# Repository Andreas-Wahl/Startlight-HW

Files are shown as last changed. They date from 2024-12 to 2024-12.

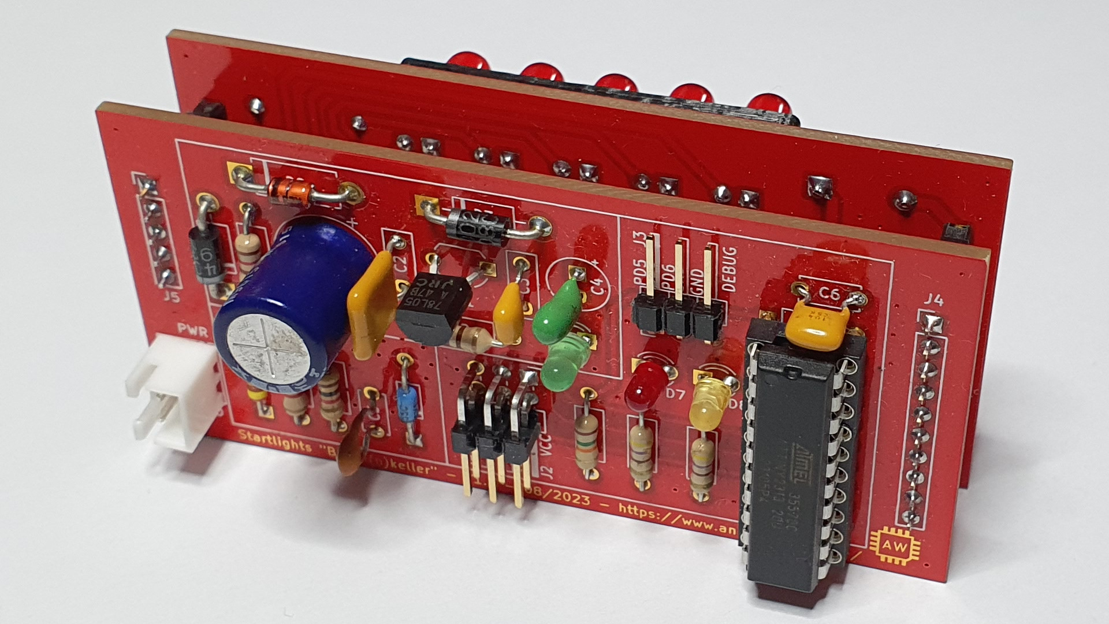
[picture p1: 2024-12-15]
#JPEG/Picture_PCB1-Mainboard.jpeg

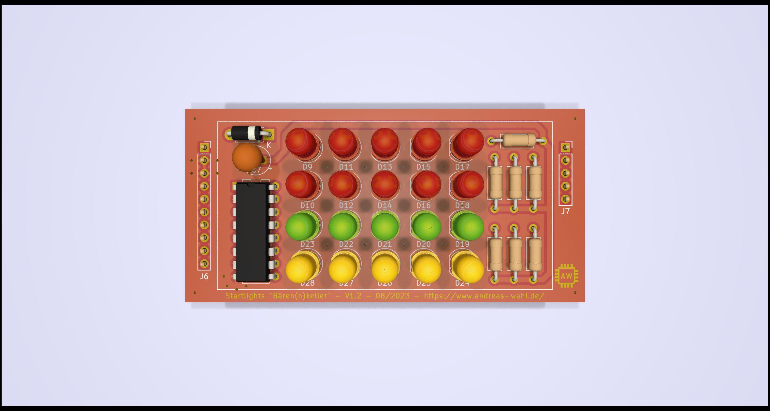
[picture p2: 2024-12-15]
#JPEG/3D-Viewer_PCB2_Display.jpg

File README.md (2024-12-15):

# STARTAMPEL "Bären(n)keller" 🚦

## Project Overview 🏎️

In a private cellar bar that has been in existence for over two generations, originally named "Bärenkeller," a CARRERA® digital 132 racetrack was set up, and the first races were held. This quickly gained popularity among friends and acquaintances. As a result, the racetrack was gradually expanded, and possible extensions were discussed.

The idea of creating a custom starting light emerged because the original CARRERA® Startlight (30354) could not bridge three lanes (two lanes + pit lane). Additionally, the custom STARTAMPEL should not only display the start sequence with red lights but also indicate the race operation with green LEDs, the safety car/pace car operation, and a false start.

The idea was quickly taken up, the data signal was analyzed with an oscilloscope and data logger, and the development of hardware, software, and housing design was initiated.

In reference to the "Bärenkeller," which was renamed "Bären(n)keller" due to the expansion of the CARRERA® digital 132 racetrack, the custom starting light was also named "STARTAMPEL 'Bären(n)keller'."

The STARTAMPEL "Bären(n)keller" was so well received that the developer decided to produce a small quantity as "prototypes" and make the development available for non-commercial use.

## Licensing 📜

- **Electronics and Housing Design**: Released under the Creative Commons Attribution-NonCommercial-ShareAlike 4.0 International License (CC BY-NC-SA 4.0).
- **Software**: Released under the GNU Affero General Public License, Version 3.0 (AGPL-3.0).

## Repository Contents 📂

- **Schematic**: The complete schematic for the STARTAMPEL "Bären(n)keller".
- **PCB Layout**: The PCB layout files for the project.
- **Hardware Documentation**: Detailed documentation on the hardware development and usage.

## Getting Started 🚀

To get started with the project, clone the repository and follow the instructions in the documentation to set up the hardware and software.

```bash
git clone https://github.com/Andreas-Wahl/Startlight-HW.git

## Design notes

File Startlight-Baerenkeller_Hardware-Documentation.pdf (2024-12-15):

# SLOTCAR STARTAMPEL „Bären(n)keller“

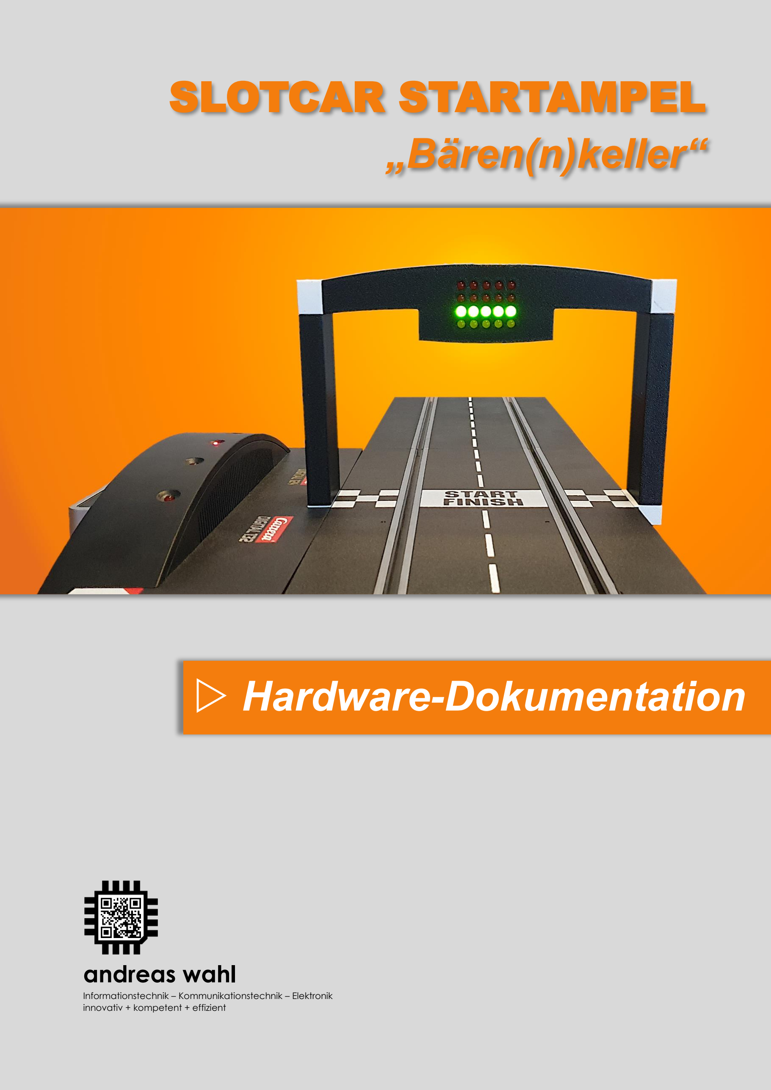
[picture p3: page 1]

SLOTCAR STARTAMPEL "Bären(n)keller" - Hardware-Dokumentation

# - Hardware-Dokumentation

## andreas wahl

Informationstechnik – Kommunikationstechnik – Elektronik innovativ + kompetent + effizient

# SLOTCAR STARTAMPEL

# „Bären(n)keller“

# Hardware-Dokumentation

# Version 1.0 - 31.01.2024

Software-Version: 1.0
https://github.com/Andreas-Wahl/Startlight-SW
Hardware-Version: 1.3
https://github.com/Andreas-Wahl/Startlight-HW
Gehäuse-Version 1.0
https://github.com/Andreas-Wahl/Startlight-3D

## andreas wahl

Informationstechnik – Kommunikationstechnik – Elektronik innovativ + kompetent + effizient
https:/www.andreas-wahl.de/

### Inhaltsverzeichnis

### Einführung und Ziele

Idee und Namensgebung

In einer bereits über zwei Generationen bestehenden privaten Kellerbar, die ursprünglich den Namen „Bärenkeller“ erhalten hat, wurde eine CARRERA® digital 132 Rennbahn aufgebaut und die ersten Rennen ausgetragen.

Schnell fand dies bei Freunden und Bekannten großen Anklang. So wurde die Rennbahn sukzessive weiter ausgebaut und über mögliche Erweiterungen diskutiert.

So entstand auch die Idee einer eigenen Startampel, da die originale Startampel CARRERA® Startlight (30354) nicht über drei Fahrspuren (zwei Fahrspuren + Boxengasse) überbrücken kann. Weiter sollte die eigene Startampel nicht nur die Start-Sequenz über rote Anzeigen darstellen können, sondern auch den freigegebenen Rennbetrieb mit grünen LEDs, den Safety-Car-/Pace-Car-Betrieb und einen Frühstart anzeigen.

Kurzerhand wurde die Idee aufgegriffen, das Datensignal mit Oszilloskop und Datenlogger analysiert und die Entwicklung von Hardware, Software und Gehäuse-Design angestoßen.

In Bezug auf den „Bärenkeller“, welcher durch die Erweiterung der CARRERA® digital 132 Rennbahn zum „Bärennkeller“ umbenannt wurde, erhielt auch die selbst entwickelte Startampel den Namen „STARTAMPEL „Bären(n)keller““.

Die STARTAMPEL „Bären(n)keller“ fand so großen Anklang, dass sich der Entwickler entschlossen hat, eine kleine Menge als „Prototypen“ zu produzieren und die Entwicklung für nicht kommerzielle Nutzung zur Verfügung zu stellen.

Die Elektronik und das Gehäusedesign sind unter der Creative Commons Version 4.0 Lizenz „Namensnennung, nicht kommerziell, Weitergabe unter gleichen Bedingungen (CC BY-NC-SA 4.0)“ und die Software unter der „GNU Affero General Public License, Version 3.0“ veröffentlicht.
Über diese Dokumentation

Nachfolgend wird die für die „STARTAMPEL „Bären(n)keller“ entwickelte Elektronik betrachtet und beschrieben.

Das Projekt „STARTAMPEL „Bären(n)keller“ soll insbesondere dazu anregen, sich spielerisch mit der Elektronik und der Programmierung von Mikrocontrollern, insbesondere in Assembler, auseinanderzusetzen.

Diese Dokumentation soll als Hilfestellung dienen und weitere Anreize und Ideen für interessanten Projekten bei Spiel und Spaß bieten.

Entsprechend der Software-Dokumentation wurde auch die Hardware-Dokumentation weitgehend an den Aufbau und die Struktur der arc42¹
-Software-Architekturdokumentation angelehnt. Dadurch erhalten sowohl die Software- als auch die Hardware-Dokumentation einen vergleichbaren Aufbau und eine durchgängige Struktur, was die Lesbarkeit und das Verständnis erleichtern sollen.

1 arc42: https://arc42.org/

Aufgabenstellung

Für die STARTAMPEL „Bären(n)keller“ wurden nachfolgend aufgeführte und beschriebene Funktionen festgelegt.

ID | Anforderung | Erklärung
M-1 | THT-Aufbau | Damit die Elektronik auch von Anfängern leicht nachgebaut und gewartet werden kann, ist diese in Durchsteckmontage (THT, through-hole technology) aufzubauen.
M-2 | AVR-Mikrocontroller | Für die Steuerung ist der AVR® Mikrocontroller Attiny2313 zu verwenden.
M-3 | 4x5 5 mm-LED Anzeige | Für die Anzeige der Startampel sind 5 mm LEDs zu verwenden, welche in 4 Reihen und 5 Spalten wie folgt aufzubauen sind: 2 Reihen in 5 Spalten rot, 1 Reihe grün, 1 Reihe gelb.
M-4 | Unterbringung im Startampelgehäuse | Die komplette Elektronik muss im Gehäuse der Startampel untergebracht werden können.
M-5 | Stromversorgung und Daten über den Fahrleiter | Die Stromversorgung der Elektronik muss über den Fahrleiter der CARRERA® digital Rennbahn erfolgen. Über diesen ist auch das Datensignal zu gewinnen.
M-6 | Schutz vor Anschlussfehler | Die Elektronik muss vor fehlerhaftem Anschluss der Anschlussleitungen geschützt werden.
M-7 | Schutz vor Überspannung | Die Elektronik muss vor Überspannungen, welche auf dem Fahrleiter auftreten könnten, geschützt werden.
M-8 | Zugängliche ISP-Schnittstelle | Für die Software-Entwicklung und spätere Aktualisierungen muss die ISP-Schnittstelle des Mikrocontrollers über Pfostenverbinder zugänglich sein.
M-9 | Einfacher Nachbau | Die Schaltung soll auch für Einsteiger verständlich und leicht nachzubauen sein. Auch bei der Bauteilauswahl soll daher auf gut verfügbare Bauteile und Werte Rücksicht genommen werden.

Qualitätsziele

Folgende wesentliche Qualitätsanforderungen wurden für die STARTAMPEL „Bären(n)keller“ bestimmt:

ID | Anforderung | Erklärung
Q-1 | Korrektheit | Die jeweils signalisierten Zustände müssen korrekt sein.
Q-2 | Zuverlässigkeit | Die Zustände müssen zuverlässig signalisiert werden.
Q-3 | Leistungsfähigkeit | Schnelle Auswertung und kurze Reaktionszeit.
Q-4 | Darstellung | Gute und eindeutige Darstellung der einzelnen Zustände.

Stakeholder

Folgende Personen und Gruppen haben Interesse am Aufbau, an der Funktion und Qualität der Elektronik (Hardware) der STARTAMPEL „Bären(n)keller“:

Rolle | Ziel | Erwartungshaltung
Rennleitung | Zuverlässiger Betrieb. | Möchte eine zuverlässige und störungsfreie Funktion.
Fahrer | Schnelle, zuverlässige und fehlerfreie Signalisierung. | Möchte die Zustände des Rennbetriebes schnell, korrekt und zuverlässig erkennen können.
Zuschauer | Gute Visualisierung des Rennbetriebs. | Möchte die Zustände des Rennbetriebes gut und ohne Verwechslungsgefahr erkennen können.

Folgende Personen und Gruppen haben Interesse am Schaltplan und einer Beschreibung der Hardware für die STARTAMPEL „Bären(n)keller“:

Rolle | Ziel | Erwartungshaltung
Entwickler | Effizientes Umsetzen der definierten Anforderung in der Hardware. | Gute und detaillierte Beschreibung der zu erwartenden Funktionen und Qualitätsziele sowie umfangreiche Dokumentation der angebundenen Systeme.
Tester | Prüfen der Anwendung auf mögliche Fehler. | Ausfallsichere und langlebige Hardware, die robust gegenüber möglichen Störungen und Fehlbedienung ist
Nutzer | Möchte die Elektronik nachbauen und bei Bedarf reparieren. | Leichter Nachbau, klare, präzise und fehlerfreie Dokumentation.

### Randbedingungen

Für die Entwicklung der Elektronik (Hardware) für die STARTAMPEL „Bären(n)keller“ liegen folgende Randbedingungen vor.

ID | Anforderung
RB-1 | Mikrocontroller: Microchip AVR®-Mikrocontroller ATtiny2313² 8 MHz Taktfrequenz, interner Takt Interner SRAM Externen Interrupt 7 digitale Ausgänge In-System-Programmierung und debugWIRE
RB-2 | Carrera® digital 124/132 Rennbahn³ 14,8 V Fahrspannung bei 132 (18 V Fahrspannung bei 124) 10 kHz Manchester Code
RB-3 | 5mm-LEDs für die Anzeige 2 Reihen rot in 5 Spalten 1 Reihe grün 1 Reihe gelb
RB-4 | Verfügbarer Platz im Gehäuse der STARTAMPEL „Bären(n)keller“: Breite: 79 mm Höhe: 39 mm Tiefe: 41 mm +15 mm für LEDs
RB-5 | Die Schaltung und das Platinen-Layout sind mit der Open-Source Schematic Capture & PCB Design Software KiCAD EDA⁴ zu entwickeln.
RB-6 | Für Schaltungssimulationen ist die von ANALOG DEVICES⁵ kostenlos zur Verfügung gestellte Simulationssoftware LTspice⁶ zu verwenden.

2 Microchip ATtiny2313: https://www.microchip.com/en-us/product/ATtiny2313
3 CARRERA® digital 132 Rennbahn: https://carrera-toys.com/digital-132
4 KiCad Open Source Electronics Design Automation Suite: https://www.kicad.org/
5 ANALOG DEVICES: https://www.analog.com/en/index.html
6 LTspice: https://www.analog.com/en/resources/design-tools-and-calculators/ltspice-simulator.html

### Kontextabgrenzung

Fachlicher Kontext

Spannungsversorgung

Die Fahrbahnen der CARRERA® digital 124/132 Rennbahnen⁷ werden mit folgende Versorgungsspannungen betrieben:

Variante/Maßstab | Nennspannung | Nennstrom | Nennleistung
digital 124 | 18 V | 3 A | 54 VA
digital 132 | 14,8 V | 3,5 A | 51 VA
Die hier beschriebene Hardware wurde für die CARRERA® digital 132 dimensioniert. Daher berücksichtigt diese Dokumentation maßgeblich die Nennspannung von 14,8 V.

Über die Fahrspannung wird das Datensignal in Anlehnung an den Manchester Code⁸ moduliert.

Im Abstand von 6,2 ms folgen Datenpakete mit einer Länge von acht bis zwölf Bits und einer Dauer von 0,8 bis 1,2 ms.

Während der Übertragung wird die Spannungsversorgung entsprechend dem Flankenwechsel des Datensignales unterbrochen. Die längste Low- (GND-) Phase liegt außerhalb einer Boxengasse entsprechend der Übertragungsfrequenz von 10 kHz bei 100 µs Periodendauer. Für den Datenempfang von Fahrzeugen und Zubehör erzeugt die CARRERA® digital Control-Unit ebenfalls Low- (GND-) Phasen mit einer Länge von 50 µs, auf die bei Bedarf mit einem Hochziehen des Signales auf High-Potential geantwortet wird.

Datensignal

Die Datenübertragung erfolgt im Manchester-Code mit einer Übertragungsfrequenz von 10 kHz, was einer Übertragungsrate von 10 KBaud entspricht.

Werden aufeinanderfolgend gleiche Bits (bspw.: 00000000 oder 11111111) übertragen, findet ein Flankenwechsel alle 50 µs statt, was einer Frequenz von 20 kHz entspricht.

Bei jeweils aufeinanderfolgend unterschiedlichen Bits (bspw. 01010101), erfolgt der Flankenwechsel alle 100 µs, was einer Frequenz von 20 kHz, entspricht.

Der durchschnittliche Tastgrad (Duty-Cycle) des Manchester-Code-Datensignals beträgt 0,5 (50 %).

Anzeige-Einheit

Die Anzeigeeinheit der STARTAMPEL „Bären(n)keller“ soll aus jeweils 5 x 2 roten LEDs für die Anzeige der Startsequenz (Countdown), 5 grünen LEDs für die freigegebene Rennstrecke und 5 gelbe LEDs für die Pace-Car/Safety-Car-Phase bestehen.

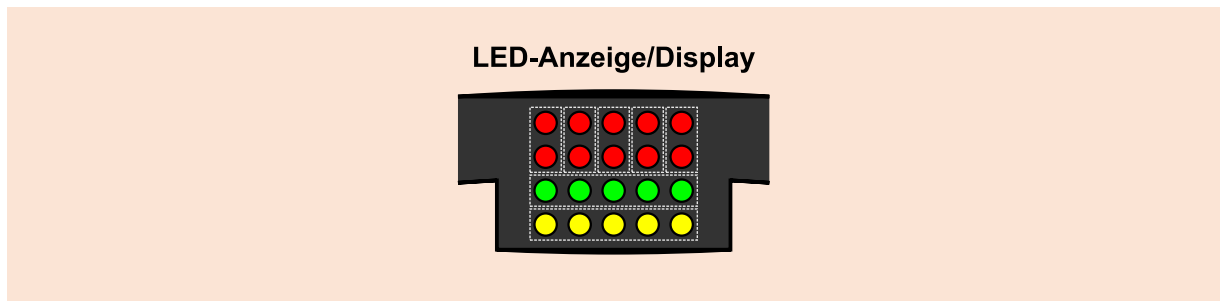
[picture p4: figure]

7 CARRERA® digital 132 Rennbahn: https://carrera-toys.com/digital-132 8 Manchester Code: https://de.wikipedia.org/wiki/Manchester-Code

Technischer Kontext

Übersicht der Komponenten

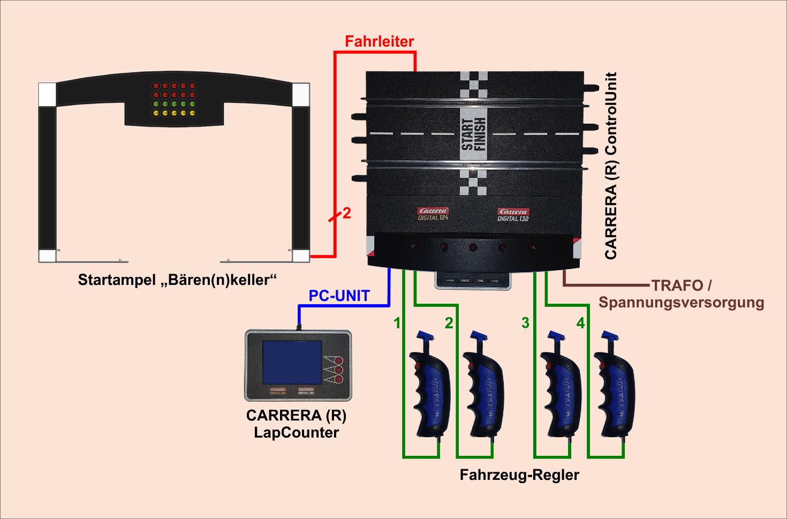
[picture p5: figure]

Bezeichnung | Beschreibung
Control-Unit | Zentraleinheit der CARRERA® digital 124/132 Rennbahn für die Bedienung und Steuerung des Rennbetriebs und Anschluss aller Komponenten.
Lap-Counter | Rundenzähler für die CARRERA® digital 124/132 Rennbahn. Über diesen werden Zeit- und Rundenrennen gestartet und das Rennen entsprechend beendet, wenn Zeit oder Anzahl der Runden erreicht wurden. Der Sieger, bzw. das Fahrzeug, welches das Rennen beendet, wird durch den Lap-Counter signalisiert. Alternativ können an der PC-Unit-Schnittstelle auch anderweitige Lösungen, wie bspw. PC-Software, angebunden werden.
Regler | Mit den Reglern (Controller / Drücker) werden die Fahrzeuge (fern-) gesteuert. Es können bis zu 6 Regler gleichzeitig angeschlossen werden.
Fahrzeug | Das Fahrzeug (Slotcar) im Maßstab 1:24 bzw. 1:32 fährt mittels Leitkiel in einem Schlitz seiner zugehörigen Fahrspur auf der Rennstrecke. Über Kontaktschleifer wird das Fahrzeug über die Fahrbahn mit Spannung versorgt. Bei der CARRERA® digital 124/132 Rennbahn erhält das Fahrzeug über den Fahrleiter auch die Steuerinformationen mittels Datenpaketen im Manchester Code. Es können bis zu 8 Fahrzeuge (6x Regler +1 Ghost Car +1 Pace Car) zeitgleich auf der Rennstrecke fahren.
Startampel | Die STARTAMPEL „Bären(n)keller“ ergänzt die Rennstrecke um eine Visualisierung der Start-Sequenz, des Zustandes der Rennstrecke usw.
Datenpakete | Mittels Datenpaketen, welche im Manchester-Code über den Fahrleiter gesendet werden, kommuniziert die CARRERA® digital 124/132 Control-Unit mit Fahrzeugen und Zubehör (wie Weichen, Zeitmessungen, Boxengassen u. ä.). Auch die für die STARTAMPEL „Bären(n)keller“ erforderlichen Informationen werden auf diese Weise übertragen.

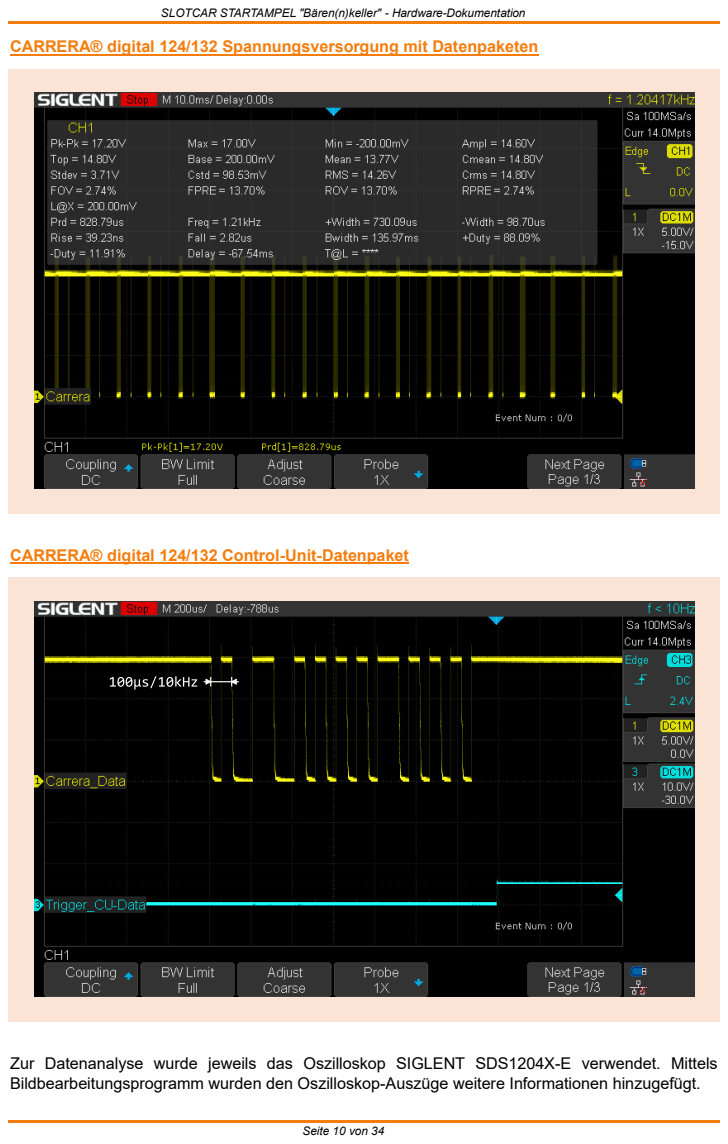
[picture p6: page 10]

CARRERA® digital 124/132 Spannungsversorgung mit Datenpaketen

CARRERA® digital 124/132 Control-Unit-Datenpaket

Zur Datenanalyse wurde jeweils das Oszilloskop SIGLENT SDS1204X-E verwendet. Mittels
Bildbearbeitungsprogramm wurden den Oszilloskop-Auszüge weitere Informationen hinzugefügt.

### Lösungsstrategie

Die Elektronik wird in zwei Platinen

- Hauptplatine
(Enthält alle Komponenten zur Auswertung des Datensignals.)
- Displayplatine
(Enthält alle Komponenten für die LED-Anzeige.)

aufgeteilt, welche über Stift- und Buchsenleisten jeweils rückseitig zusammengesteckt werden und damit eine Einheit bilden.

Auf den einzelnen Platinen wird die Elektronik in Funktionsblöcken aufgeteilt, die in der nachfolgenden Beschreibung näher betrachtet werden:

Hauptplatine:

- Spannungsversorgung Mikrocontroller
(Stellt aus der Fahrspannung der CARRERA® digital Rennbahn eine stabile +5 V Spannungsversorgung für den Mikrocontroller bereit.)
- Signalaufbereitung
(Bereitet das auf der Fahrspannung der CARRERA® digital Rennbahn modulierte Datensignal für die Verarbeitung über einen Porteingang des Mikrocontrollers auf.)
- Mikrocontroller
(Enthält den Mikrocontroller und dessen zum Betrieb erforderliche Komponenten.)

Displayplatine:

- LED-Anzeige
(Enthält die LEDs der Startampel, sowie die notwendigen Treiber.)

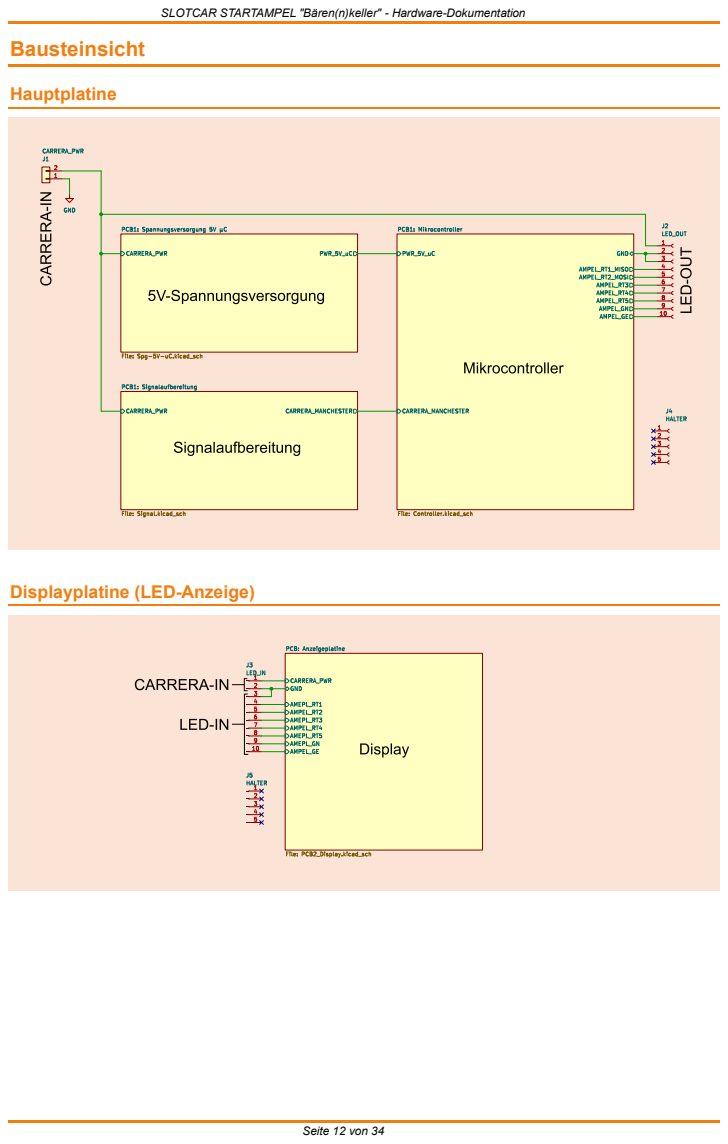
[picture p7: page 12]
Bausteinsicht; Hauptplatine

Displayplatine (LED-Anzeige)

### Schaltungsentwicklung

Stromversorgung (Hauptplatine)

Eckdaten

Auf der Hauptplatine benötigt der Microchip AVR®-Mikrocontroller ATtiny2313 und seine externe Beschaltung eine Spannungsversorgung von 5 V.

Zur Ermittlung des Strombedarfes werden folgende Komponenten berücksichtigt:

Nr. | Komponente | Strombedarf
1 | Mikrocontroller Atmel 2313 mit internem Oszillator bei 8 MHz | 7,5 mA
2 | Spannungsregler | 6 mA
3 | Power-LED, 3 mm, grün | 10 mA
4 | Debug-LED, 3 mm, gelb | 10 mA
5 | Debug-LED, 3 mm, rot | 10 mA
6 Ansteuerung Treiberbaustein ULN2003A | (maximal 5 Treiber zeitgleich aktiv) | 5x1,35 mA =6,75 mA
| Maximaler Gesamtstrombedarf (ICC): | 50,3 mA

Schaltungsaufbau

Die dargestellte Schaltung zur 5 V-Spannungsversorgung des Mikrocontrollers mit einem linearen Festspannungsregler wird im Folgenden näher beschrieben.

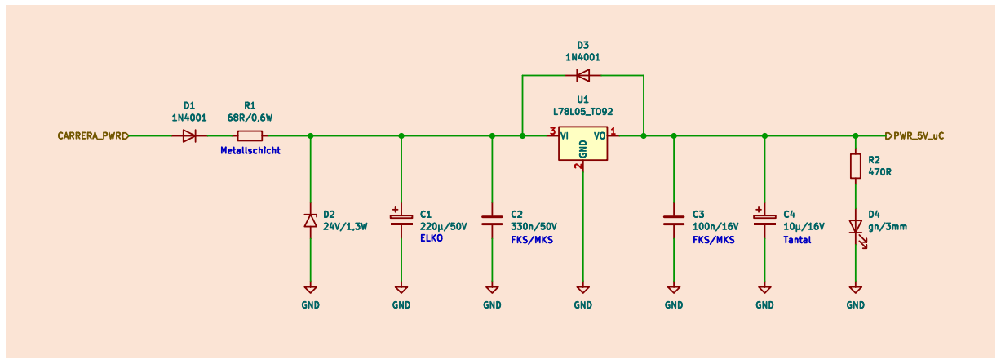
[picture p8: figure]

Verpolungsschutz und Rückwirkungsfreiheit

Um die Schaltung vor fehlerhaftem Anschluss zu schützen, wird am Eingang eine 1N4001-Diode (D1) in Durchlassrichtung eingesetzt. Zudem verhindert die Diode am Eingang Rückwirkungen auf das durch die Control-Unit modulierte Datensignal der Fahrspannung, die durch die nachfolgenden Glättungs- und Siebkondensatoren verursacht werden könnten.

Vorwiderstand

Um die Verlustleistung am nachfolgenden Spannungsregler zu begrenzen, wird ein Vorwiderstand in Reihe geschaltet. Ziel ist es, die Verlustleistung zwischen Widerstand und Spannungsregler so zu verteilen, dass es bei keinem der beiden Bauteile in Extremfällen zu einer Überlastung kommen kann.

Damit dem Spannungsregler eine ausreichende Eingangsspannung zur Verfügung steht, ist die maximal am Vorwiderstand abfallende Spannung wie folgt zu berechnen:

UR1 = URV = UCC − UD1 − UU1 − UU1_Ausgang

Die im Datenblatt⁹ des Spannungsreglers 78L05 von ST angegebene Dropout-Spannung beträgt 1,7 V. Um die Störunterdrückung bei eingangsseitigen Spannungsschwankungen in den vom Hersteller angegebenen Grenzen zu halten, wurden 300 mV Regelreserve für die Betriebssicherheit berücksichtigt.

UU1 = UU1_DropOut + UU1_Regelreserve = 1,7 V + 0,3 V = 2 V

Damit ergibt sich für die am Vorwiderstand maximal abfallende Spannung:

UR1 = 14,8 V − 0,7 V − 2 V − 5 V = 7, 1 V

Die von der Control-Unit übertragenen Daten sind periodisch und nicht sinusförmig (Rechteck). Das für die Spannungsversorgung bei der Manchester-Code-Übertragung ungünstigste Tastverhältnis liegt bei 0,5. Bei einem Tastverhältnis von 50 % und einem Gleichstrommittelwert von 50,3 mA muss somit in der ersten Halbwelle des Rechtecksignals der doppelte Strom zur Verfügung stehen, damit die Schaltung mit ausreichend Energie versorgt wird. (Siehe auch Pulsweitenmodulation¹⁰)

Somit ergibt sich für den Vorwiderstand:

R1 = RV =

UR1

ICC

× d =

UR1

ICC

×

tein
t

=

7,1 V
50,3 mA

×

50 µs
100 µs

= 70, 6 Ω

Durch die Auswahl eines 68 Ω-Vorwiderstandes aus der E12-Reihe ist der ungünstigste Fall des Tastverhältnisses für eine sichere und zuverlässige Versorgung der Schaltung mit der erforderlichen Energie berücksichtigt.

Berechnung der Verlustleistung am Vorwiderstand R1:

Für den nach der E12-Serie ausgewählten 68 Ω Widerstand ergibt sich folgende mittlere Verlustleistung:

PR1 =

UR1

2
R1

× d =

(7,1 V)

2
68 Ω

×

50 µs
100 µs

= 370, 7 mW

Damit ist ein üblicher Kohleschichtwiderstand mit 1/4 W maximaler Verlustleistung für den zuverlässigen Dauerbetrieb nicht ausreichend. Hier wird deshalb ein 0,6 W Metallschichtwiderstand eingesetzt.

Überspannungsschutz

Eine nachgeschaltete Zenerdiode in Sperrrichtung gegen Ground schützt die Schaltung vor möglichen Spannungsspitzen der Eingangsspannung, die durch Induktivitäten der Fahrzeuge und Weichen auf der CARRERA® digital Rennbahn verursacht werden könnten.

9 78L05 – Datenblatt von ST: https://www.st.com/resource/en/datasheet/l78l.pdf
10 Pulsweitenmodulation: https://www.mikrocontroller.net/articles/Pulsweitenmodulation

Glättungskondensator

Die mit 10 kHz Manchester-Code modulierte Fahrspannung muss für eine stabile 5 V-Spannungsversorgung zunächst „geglättet“ werden, um auch in den Low-Phasen der Eingangsspannung den nachfolgenden Spannungsregler mit der erforderlichen Eingangsspannung von mindestens ca. 7,1 V sicher zu versorgen.

Bei einer mit Manchester-Code modulierten Spannung handelt es sich um eine periodische, nicht sinusförmige Rechteckspannung. Übliche Berechnungen für sinusförmige periodische Signale sind hier daher nichtzutreffend.

Kapazität

Da das Rechtecksignal einem wechselnden Ein- und Ausschalten einer an den Kondensator angeschlossenen Spannungsquelle entspricht, wird zur Ermittlung der erforderlichen Kapazität der Lade- und Entladevorgang des Kondensators betrachtet. Während der High-Phase des Rechtecksignals wird der Kondensator aufgeladen, und während der Low-Phase wird er entladen.

Für die Ladung eines Kondensators gilt:

Q = I × t und Q = C × U

Daraus ergibt sich:

I × t = C × U

Die erforderliche Kapazität des Glättungskondensators lässt sich damit für einen Laststrom von ICC=50,3 mA, einer maximalen Restwelligkeit von ΔUU1_Ripple_Eingang=0,1 V und einer High-Phase des 10 kHz-Rechtecksignals von t=50 µs, wie folgt berechnen:

C1 =

ICC × Δt

∆UU1_Ripple_Eingang

=

50,3 mA × 50 µs
0,1 V

= 25, 2 µF

Equivalent Series Resistance (ESR)

### 11 und Lebensdauer

Für die Auswahl eines Kondensators ist es, insbesondere bei höherfrequenten Spannungen, entscheidend, wie schnell sich der Kondensator aufladen lässt und wie schnell er die Ladung wieder abgeben kann. Maßgeblich hierfür ist der Innenserienwiderstand des Kondensators, auch als ESR (Equivalent Series Resistance) bekannt. Je niedriger der ESR, desto schneller kann der Kondensator auf- und entladen werden. Ein niedrigerer ESR bedeutet auch eine niedrigere Restwelligkeit des geglätteten Signals und eine niedrigere Verlustleistung im Kondensator.

Grundsätzlich bietet ein Tantal-Kondensator aufgrund seines vergleichsweisen niedrigen
äquivalenten | Serienwiderstands | (ESR) | im | Verhältnis | zu | seinen | Abmessungen | zu
Elektrolytkondensatoren einen Vorteil. Allerdings sind Tantal-Kondensatoren teurer und empfindlicher gegenüber Ripplestrom-Überlastungen und schnellen Schaltflanken. Daher wurde für den Eingang des Spannungsreglers entschieden, einen vergleichbaren Elektrolytkondensator auszuwählen.

Zu berücksichtigen ist allerdings, dass sich bei Elektrolytkondensatoren der Innenserienwiderstand ESR mit dem Alter infolge der Diffundierung ihres Elektrolytes erhöht. Dabei sinkt auch die Kapazität. Die Lebensdauer von handelsüblichen Elektrolytkondensatoren bei Ausschöpfung der Nenndaten beträgt je nach Qualität etwa 2.000 bis 5.000 Betriebsstunden bei voller Ausnutzung der Kapazität und Einhaltung des Umgebungstemperaturbereichs. Durch höheres Dimensionieren kann eine

11 Ersatzserien-Widerstand / Equivalent Series Resistance (ESR): https://de.wikipedia.org/wiki/Elektrolytkondensator#Scheinwiderstand_Z_und_Ersatzserienwiderstand_ESR

Verlängerung der Lebensdauer erreicht werden, da der Elektrolytkondensator nicht im Grenzbereich betrieben wird und genügend Reservekapazität besteht.

Bei der Auswahl des Elektrolytkondensators wurde, ausgehend von einem Tantal-Kondensator¹² mit 33 µF Kapazität, ein ESR von ca. 77 mΩ gemessen.

Da sich bei Elektrolytkondensatoren mit steigender Frequenz die effektiv wirkende Kapazität verringert, wurde ein Elektrolytkondensator mit ausreichender Restkapazität in angegebenem Frequenzbereich ausgewählt, um die Restwelligkeit in oben berechneten Grenzen zu halten. Ein Elektrolytkondensator mit einer Kapazität von 220 µF hatte einen vergleichbaren ESR von ca. 77 mΩ und wird in dieser Schaltung eingesetzt.

Spannungsregler

Der Einsatz eines 5 V-Festspannungsreglers¹³ 78L05¹⁴ (U1) bietet eine einfache Möglichkeit, eine stabile Versorgungsspannung von 5 V bereitzustellen. Unter Berücksichtigung des ermittelten Strombedarfs ist der lineare Festspannungsregler 78L05 im TO-92 Gehäuse ausreichend und kann einen Strom von bis zu 100 mA liefern. Die maximal zulässige Eingangsspannung des 78L05 beträgt 30 V und wird durch die geringeren Fahrspannungen der Carrera® digital Rennbahnen nicht erreicht.

Um die 5 V Ausgangsspannung zuverlässig bereitzustellen, benötigt der 78L05 bei einer Dropout-Spannung von 1,7 V am Eingang eine Eingangsspannung von mindestens 6,7 V. Wie oben bereits erwähnt, sind für die Regelreserve zusätzliche 0,3 V berücksichtigt.

Restwelligkeit (Ripple)

Der vorgeschaltete Glättungskondensator wurde für eine Restwelligkeit von maximal ΔUU1_Ripple_Eingang=0,1 V dimensioniert, sodass die erforderliche Eingangsspannung bereits sehr stabil und zuverlässig zur Verfügung steht. Über die Supply Voltage Rejection (SVR) lässt sich die zu erwartende Restwelligkeit am Ausgang eines Spannungsreglers berechnen.

Der hier eingesetzte lineare Festspannungsregler 78L05 von ST hat gemäß Datenblatt im ungünstigsten Fall ein SVR von -40 dB.

Für die Amplitude (A) gilt:

A = 20 × log (
UAusgang

UEingang)

Nach Umstellung auf Ua

Ua = Ue × 10(

A
20)

lässt sich die zu erwartende Restwelligkeit wie folgt berechnen:

∆UU1_Ripple_Ausgang = ∆UU1_Ripple_Eingang × 10(

SVR
20 ) = 0,1 V × 10(

−40
20 ) = 1 mV

Verlustleistung

Die am Spannungsregler abfallende Verlustleistung berechnet sich wie folgt:

PU1 = UU1 × ICC = 2V × 50,3 mA = 100, 6mW

12 Tantal-Kondensatoren: https://de.wikipedia.org/wiki/Tantal-Elektrolytkondensator 13 Festspannungsregler: https://de.wikipedia.org/wiki/Spannungsregler
14 78L05 – Datenblatt von ST: https://www.st.com/resource/en/datasheet/l78l.pdf

Daraus ergibt sich eine Wärmeentwicklung von

∆T = PU1 × θJA = 100,6 mW × 200 K/W = 20, 12 K

Bei einer Umgebungstemperatur von 25°C steigt die Temperatur auf 45,12°C. Eine für den eingesetzten Festspannungsregler ohne Kühlung mögliche Temperatur.

Schwingneigung

Um ein Schwingen des Spannungsreglers zu verhindern, ist gemäß dem Datenblatt am Eingang ein Kondensator mit einer Kapazität von 330 nF (C2) und am Ausgang ein Kondensator mit einer Kapazität von 100 nF (C3) vorzusehen. Dies wurde hier entsprechend übernommen.

Schutzdiode

Eine Diode (D3) in Sperrrichtung vom Eingang zum Ausgang des Spannungsreglers schützt diesen davor, dass dessen Ausgangsspannung nicht spürbar (hier maximal 0,7 V) über der
Eingangsspannung | liegen | kann. | Würde | die | Ausgangsspannung | deutlich | über | der
Eingangsspannung liegen, könnte dies den im Spannungsregler eingebauten Längstransistor zerstören. Dieser Fall könnte beispielsweise durch einen Kurzschluss am Glättungskondensator (C1) eintreten.

Pufferkondensator

Um die 5 V-Ausgangsspannung weiter zu stabilisieren, insbesondere zur Pufferung der Stromspitzen des Mikrocontrollers sowie als Blockkondensator zur Filterung von hochfrequenten Störungen, wird am Ausgang der 5 V-Spannungsversorgung ein 10 µF Tantal-Kondensator (C4)
eingesetzt. | Tantal-Kondensatoren | haben, | wie | oben | bereits | beschrieben, | gegenüber
Elektrolytkondensatoren einen deutlich niedrigeren äquivalenten Serienwiderstand (ESR, Equivalent Series Resistance) und können daher benötigte Energie deutlich schneller bereitstellen, da sie sich schnell laden und entladen lassen.

Da die eingangsseitige Glättung und der lineare Festspannungsregler die Spannung bereits wesentlich stabilisieren und damit die Restwelligkeit deutlich verringern, fällt die Empfindlichkeit von Tantal-Kondensatoren gegenüber Ripplestrom-Überlastungen und schnellen Schaltflanken hier nicht mehr maßgeblich ins Gewicht.

Kontroll-LED-Anzeige

Zur Kontrolle der anliegenden 5 V-Ausgangsspannung wird eine grüne LED (D4) mit entsprechendem Vorwiderstand (R2) an den Ausgang geschaltet.

Signalaufbereitung (Hauptplatine)

Eckdaten

Die I/O-Eingänge des Mikrocontrollers haben einen Spannungsbereich von -0,5 V bis VCC +0,5 V. Eingangsspannungen

- im Bereich von -0,5 V bis 0,3 * VCC werden sicher als Low-Pegel und
- im Bereich von 0,6 * VCC und VCC + 0,5 V als High-Pegel

erkannt.

Bei einer Spannungsversorgung von VCC=5 V ergibt sich somit

- eine maximale Eingangsspannung von 5,5 V,
- ein Low-Pegel zwischen -0,5 V und 1,5 V und
- ein High-Pegel zwischen 3,0 V und 5,5 V

Das CARRERA® digital 124/132 Datensignal hat eine Spannung von 14,8 V (132) und 18 V (124) und muss daher über einen Spannungsteiler auf die zulässige Eingangsspannung des verwendeten I/O-Pins des Mikrocontrollers reduziert werden.

Zusätzlich muss der I/O-Pin des Mikrocontrollers vor Spannungsspitzen über 5,5 V geschützt werden.

Schaltungsaufbau

Für den Teil der Signalaufbereitung ergibt sich folgender Schaltungsaufbau:

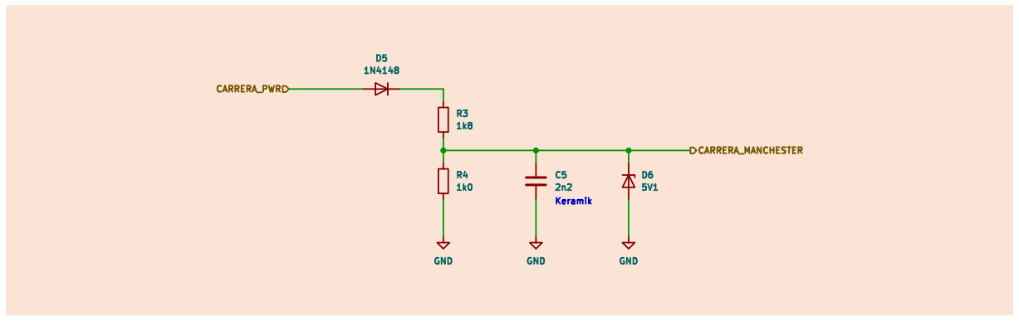
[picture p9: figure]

Schutzschaltungen

Um die Schaltung vor falscher Polung zu schützen, wird am Eingang in Durchlassrichtung eine 1N4148-Diode (D5) eingesetzt. Zudem verhindert die Diode am Eingang Rückwirkungen auf die Fahrspannung und das darauf modulierte Datensignal durch den nachfolgenden Tiefpass-Kondensator.

Eine 5V1-Zenerdiode¹⁵
, (D6) welche in Sperrrichtung am I/O-Pin des Mikrocontrollers Richtung Ground geschaltet wird, schützt den Eingang des Mikrocontrollers vor Überspannungen.

Hinweis: Durch diese Zenerdiode ist grundsätzlich auch ein unveränderter Betrieb an einer CARRERA® digital 124 Rennbahn möglich. Allerdings fließt dabei ein unnötig hoher Strom über den 1k8-Widerstand und die Zenerdiode ab.

Spannungsteiler

Zunächst wird die Eingangsspannung durch die Eingangsdiode um 0,7 V herabgesetzt. Der darauffolgende Spannungsteiler mit den Widerständen 1k8 (R3) und 1k0 (R4) der E12-Reihe teilt die Spannung weiter im Verhältnis 1,8:1,0 auf. Am Eingang des Mikrocontrollers liegt bei 14,8 V Fahrspannung ein High-Pegel von 5,04 V an.

Hinweis: Wird der Spannungsteiler für den dauerhaften Betrieb an einer CARRERA® digital 124 Rennbahn mit einer Fahrspannung von 18 V angepasst, so muss auch die nachfolgende Berechnung des Kondensators entsprechend angepasst werden!

Bei Betrieb an einer CARRERA® digital 124 Rennbahn mit 18 V Fahrspannung empfiehlt es sich daher, den 1k8 Widerstand gegen einen 2k7 Widerstand zu ersetzen. Dann liegt bei 18 V Fahrspannung ein High-Pegel von 4,68 V am Eingang des Mikrocontrollers an. Dies ist noch ausreichend, um ein High-Signal am Eingang sicher zu erkennen.

15 Zenerdiode: https://de.wikipedia.org/wiki/Z-Diode

Filter

Zur Filterung hochfrequenter Störungen des Eingangssignals am Mikrocontroller wird ein Kondensator vom Eingangssignal gegen Ground geschaltet. Dieser bildet zusammen mit dem Spannungsteiler einen Tiefpass¹⁶

Die Grenzfrequenz¹⁷ (-3 dB) des Tiefpasses soll bei etwa der 10-fachen Frequenz des Nutzsignals liegen. Da die Übertragung des Manchester-Codes mit 10 kHz erfolgt, berechnet sich der Filterkondensator für eine Grenzfrequenz von 100 kHz wie folgt:

Cg =

1
2 × π × R × fg

Gemäß dem Thévenin-Theorem¹⁸ werden für die Wechselstromanalyse Spannungsquellen kurzgeschlossen und Stromquellen geöffnet. Damit sind die Widerstände des Spannungsteilers für die Frequenzanalyse als Parallelschaltung zu betrachten.

Für den Widerstand Rp ergibt sich somit:

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
1,8 kΩ

+

1
1,0 kΩ

=

1
1,556 kΩ

⇒ Rp = 643 Ω

Nun lässt sich der Filterkondensator (C5) wie folgt berechnen:

C5 = Cg =

1
2 × π × Rp × fg

=

1
2 × π × 643 Ω × 100 kHz = 2, 4 nF

Für eine genauere Berechnung des Tiefpasses müssten zusätzlich der Eingangswiderstand und die Eingangskapazität des Mikrocontrollers sowie die entsprechenden Eigenschaften der Zenerdiode berücksichtigt werden. Für diesen Anwendungszweck werden diese Abweichungen jedoch in Kauf genommen.

Unter Berücksichtigung verfügbarer Kondensatoren gemäß der E6-Reihe wird für C5 ein Keramikkondensator mit einer Kapazität von 2,2 nF ausgewählt.

Daraus ergibt sich eine Grenzfrequenz von:

fg =

1
2 × π × Rp × C5

=

1
2 × π × 643 Ω × 2,2 nF = 112 kHz

16 Tiefpass: https://de.wikipedia.org/wiki/Tiefpass
17 Grenzfrequenz: https://de.wikipedia.org/wiki/Grenzfrequenz
18 Thévenin-Theorem: https://de.wikipedia.org/wiki/Th%C3%A9venin-Theorem

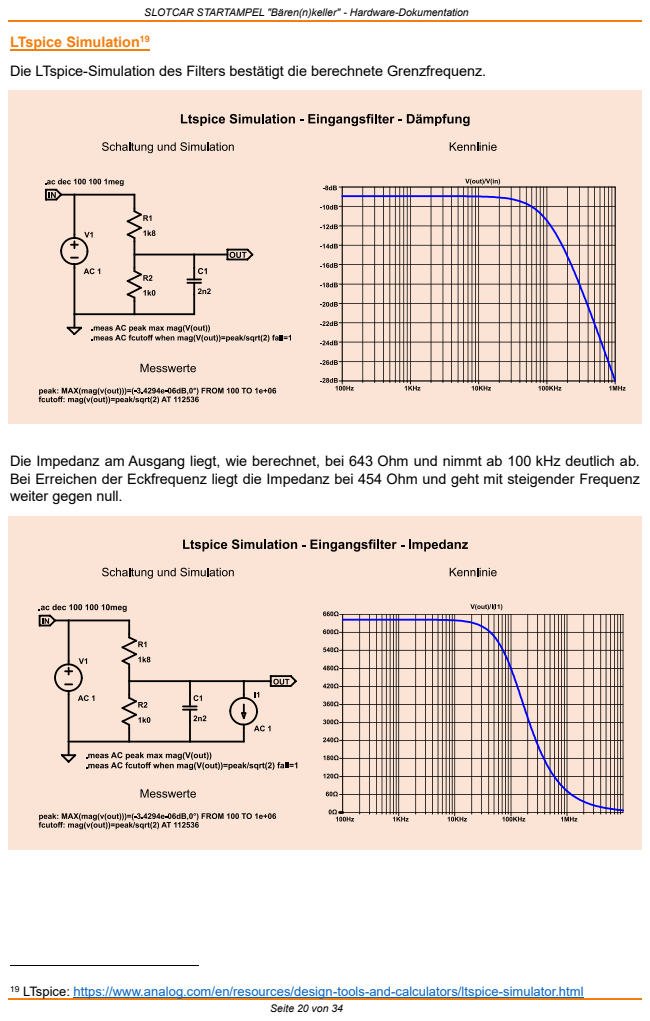
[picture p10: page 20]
LTspice Simulation¹⁹

Die LTspice-Simulation des Filters bestätigt die berechnete Grenzfrequenz.

Die Impedanz am Ausgang liegt, wie berechnet, bei 643 Ohm und nimmt ab 100 kHz deutlich ab.
Bei Erreichen der Eckfrequenz liegt die Impedanz bei 454 Ohm und geht mit steigender Frequenz
weiter gegen null.

19 LTspice: https://www.analog.com/en/resources/design-tools-and-calculators/ltspice-simulator.html

Mikrocontroller (Hauptplatine)

Eckdaten

Das Herzstück ist der Microchip AVR®-Mikrocontroller ATtiny2313²⁰, welcher mit der eigens dafür entwickelten Assembler-Software²¹ die Dekodierung und Auswertung des CARRERA® digital 124/132 Datensignales sowie die Steuerung der LED-Anzeigen der Startampel „Bären(n)keller“ übernimmt. Für den Systemtakt wird der interne Oszillator verwendet, wodurch eine separate Quarz-Beschaltung entfällt.

Hinweis: Für die Assembler-Software wurde eine eigene Software-Dokumentation erstellt, auf die hier für Informationen zur Software verwiesen wird.

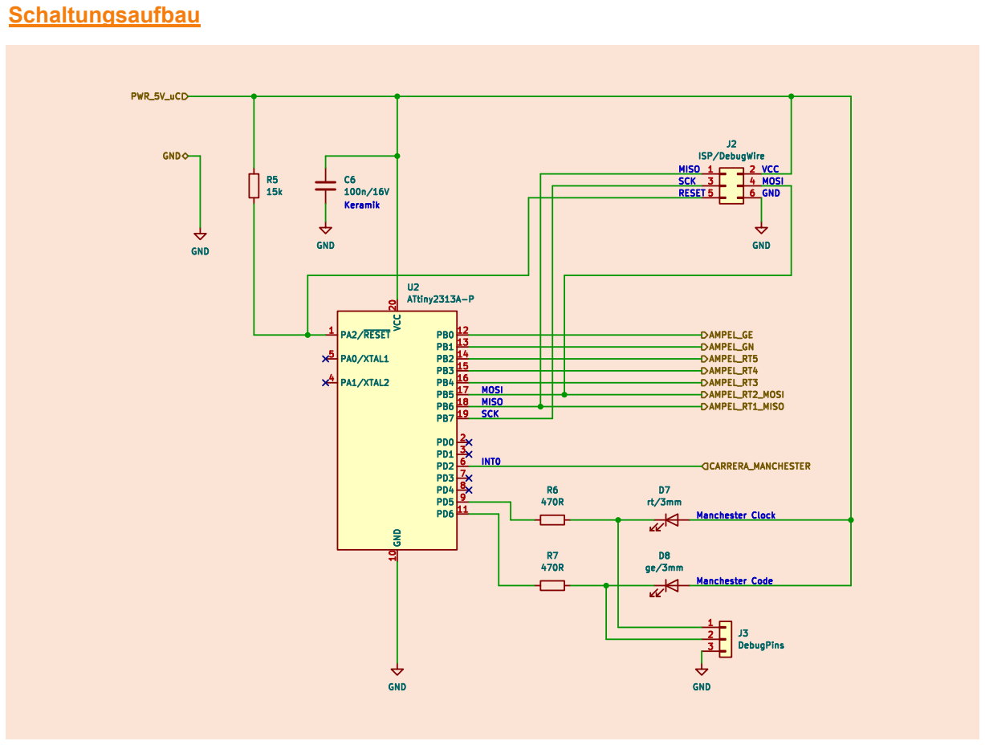
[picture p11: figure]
Schaltungsaufbau

Stromversorgung

Der Mikrocontroller erhält über den linearen Festspannungsregler der Hauptplatine seine 5 V-Versorgungsspannung. Ein Blockkondensator²² (C6) von 100 nF zwischen VCC und Ground direkt am Mikrocontroller sorgt dafür, dass Störungen durch impulsweise sehr hohe Ströme frühzeitig abgeblockt werden und sich nicht störend auf den Rest der Schaltung ausbreiten.

20 ATtiny2313: https://www.microchip.com/en-us/product/ATtiny2313 21 Assembler: https://de.wikipedia.org/wiki/Assemblersprache
22 Blockkondensator: https://de.wikipedia.org/wiki/Blockkondensator

ISP und debugWIRE

Die Schnittstellen für die In-System-Programmierung²³ (ISP) und zur Fehlersuche (debugWIRE²⁴) werden über eine Pfostensteckverbindung so herausgeführt, dass ein einfaches Programmieren und Debuggen komfortabel möglich sind. Hierzu wird der Programmieradapter Microchip Atmel ICE²⁵ verwendet.
Selbstverständlich | kann | dies | auch | mit | anderen | ISP- | und | debugWIRE-kompatiblen
Programmieradaptern erfolgen, die von der verwendeten Programmiersoftware unterstützt werden.

Pull-up-Widerstand für Reset-PIN

Der Reset-PIN wird zusätzlich zum relativ hochohmigen internen Pull-up-Widerstand mit einem externen Pull-up-Widerstand von 15 kOhm gegen VCC beschaltet. So wird sichergestellt, dass der Mikrocontroller nicht durch Einstreuung von Störsignalen ungewollt ein Reset-Signal erhält. Weiterhin ist der Pull-up-Widerstand (R15) mit 15 kOhm ausreichend hochohmig, damit der Programmieradapter am ISP/debugWIRE die Reset-Funktion sicher auslösen kann.

Debug-PINs und -LEDs

Zur Kontrolle und Fehlersuche werden zwei I/O-Ausgänge als Debug-PINs (J3) für Messungen herausgeführt und zur optischen Signalisierung mit LEDs beschaltet. Um Beschädigungen durch versehentliche Kurzschlüsse bei Messungen zu vermeiden, erfolgt der Abgriff der herausgeführten Debug-PINs jeweils im Spannungsteiler zwischen der jeweiligen LED (D7, D8) und dem Vorwiderstand (R7, R8).

Dabei wird die LED mit der Anode an VCC angeschlossen und mit der Kathode über einen Vorwiderstand an den I/O-Ausgang des Mikrocontrollers. Die jeweiligen Debug-PINs werden zwischen der Kathode der LED und dem Vorwiderstand abgegriffen. Bei einem versehentlichen Kurzschluss über die Messleitung wird der Strom, welcher aus oder in den Mikrocontroller fließt, über den Vorwiderstand der LED begrenzt.

LED-Anzeige (Displayplatine)

Eckdaten

Die LED-Anzeige oder Displayplatine wird rückseitig über Pfostenverbinder mit der Hauptplatine verbunden und bildet so eine kompakte Einheit. Zur Stromversorgung der LEDs wird die Fahrspannung der CARRERA® digital 124/132 verwendet.

Die LED-Anzeige der STARTAMPEL „Bären(n)keller“ besteht aus:

- 5 roten LEDs, jeweils 2 in Reihe geschaltet, für die Startphase
- 4 grünen LEDs, in Reihe geschaltet, für den Rennbetrieb
- 4 gelben LEDs, in Reihe geschaltet, für die Pace-Car-/Safety-Car-Phase

Diese werden durch den Mikrocontroller über das 7-fach-Darlington-Transistor-Array ULN2003A angesteuert.

23 In-System-Programmierung: https://de.wikipedia.org/wiki/In-System-Programmierung 24 debugWire: https://de.wikipedia.org/wiki/DebugWIRE
25 Atmel ICE: https://www.microchip.com/en-us/development-tool/atatmel-ice

Zur Ermittlung des Strombedarfes werden folgende Komponenten berücksichtigt:

Nr. | Komponente | Strombedarf
1 | 5 Spalten, je 2 in Reihe geschaltete rote LEDs | 5x 10 mA = 50 mA
2 | 1 Reihe mit 4 in Reihe geschalteten grüne LEDs | 10 mA
3 | 1 Reihe mit 4 in Reihe geschalteten gelben LEDs | 10 mA
| Maximaler Gesamtstrombedarf: | 70 mA

Unter Berücksichtigung, dass nicht alle LEDs gleichzeitig aktiv sein werden, wird der ermittelte maximale Gesamtstrombedarf im realen Betrieb nicht erreicht. Der maximale Strom im Regelbetrieb fließt, wenn alle roten LEDs eingeschaltet sind. Zu diesem Zeitpunkt sind die grünen und gelben LEDs nicht aktiv. Der ermittelte Strombedarf im Regelbetrieb wird bei maximal 50 mA liegen. Dies tritt ein, wenn durch die Startampel „Bären(n)keller“ signalisiert wird, dass die Rennstrecke aktuell gesperrt ist (Chaos) oder bei Rennvorbereitung und am Ende der Startsequenz.

Schaltungsaufbau

Es ergibt sich folgender Schaltungsaufbau für den Teil der Displayplatine:

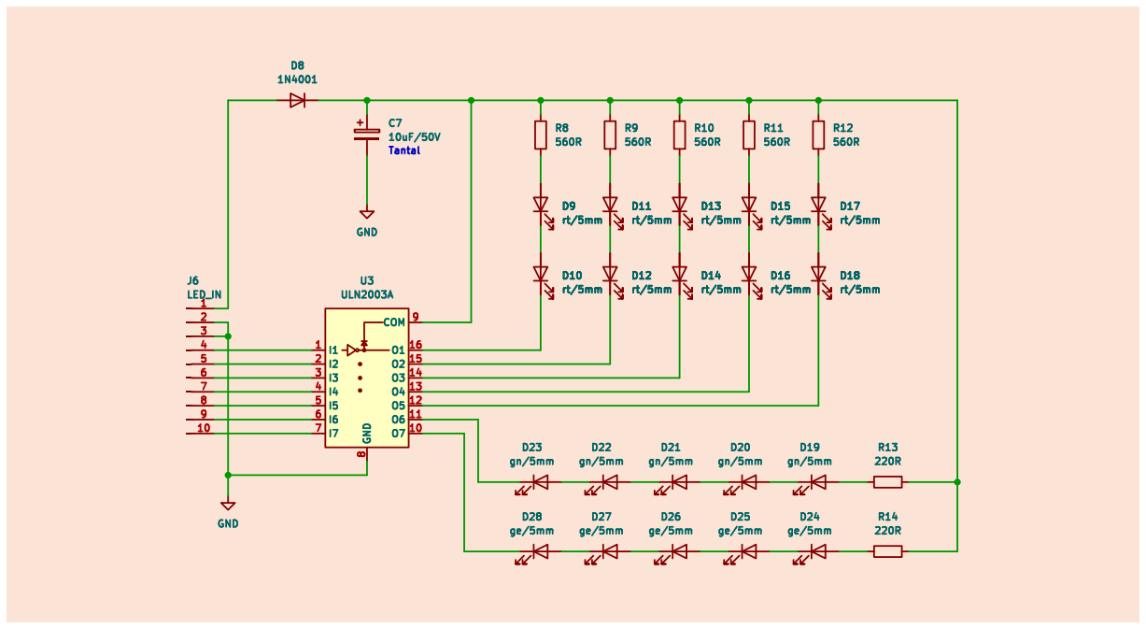
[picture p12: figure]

Schutzschaltungen

Um die Schaltung vor falscher Polung zu schützen, wird am Eingang in Durchlassrichtung eine 1N4001-Diode (D8) eingesetzt. Zudem verhindert die Diode am Eingang Rückwirkungen auf die Fahrspannung und das darauf modulierte Datensignal.

Pufferkondensator

Um eine möglichst stabile Versorgungsspannung zu gewährleisten, wird als Pufferkondensator ein 10 µF Tantal-Kondensator (C7) eingesetzt, welcher die Spannungseinbrüche aufgrund des auf die Fahrspannung modulierten Datensignals überbrückt. Tantal-Kondensatoren haben gegenüber Elektrolytkondensatoren einen deutlich niedrigeren äquivalenten Serienwiderstand (ESR, Equivalent Series Resistance) und können daher benötigte Energie deutlich schneller bereitstellen, da sie sich schnell laden und entladen lassen.

Wie oben bereits beschrieben, sind Tantal-Kondensatoren teurer und empfindlicher gegenüber Ripplestromüberlastungen und schnellen Schaltflanken. Aufgrund des Vorteils eines niedrigeren ESR wurde hier dennoch entschieden, einen Tantal-Kondensator zu verwenden, um die LEDs jederzeit mit ausreichend Energie versorgen zu können.

Darlington-Array

Die Eingänge des Darlington²⁶
-Arrays (U3) werden über Pfostenverbinder mit den Ausgängen des Mikrocontrollers verbunden. Der gemeinsame Anschluss (COM) der Freilaufdioden des ULN2003A²⁷ müsste zwingend nur bei induktiven Lasten an VCC angeschlossen werden. Aufgrund der Vollständigkeit und um mögliche Störungen abzuleiten, wurde der COM-Anschluss hier trotz ausschließlich ohmscher Lasten mit VCC verbunden.

LEDs

Die LEDs (D9-D23) werden über die entsprechenden Vorwiderstände (R8-R14) mit der gepufferten Fahrspannung und über den jeweils vorgesehenen Ausgang des Darlington-Arrays mit Ground verbunden.

26 Darlington-Schaltung: https://de.wikipedia.org/wiki/Darlington-Schaltung
27 Texas Instruments ULN2003A: https://www.ti.com/product/de-de/ULN2003A

### Platinen-Layout

Der Aufbau der Platine wurde so gewählt, dass die Bauteile zu den jeweiligen Funktionsblöcken
(Spannungsversorgung, | Signalaufbereitung, | Mikrocontroller) | logisch | gruppiert | sind. | Die
Funktionsblöcke sind deutlich zu erkennen.

Bei der Leiterbahnführung wurde auf möglichst kurze Leiterbahnen unter Berücksichtigung des Stromflusses geachtet. Mittels Durchkontaktierungen wird für eine möglichst niederohmige Verbindung zum GND-Potential gesorgt, um insbesondere hochfrequente Störeinflüsse möglichst zu vermeiden bzw. deutlich zu verringern.

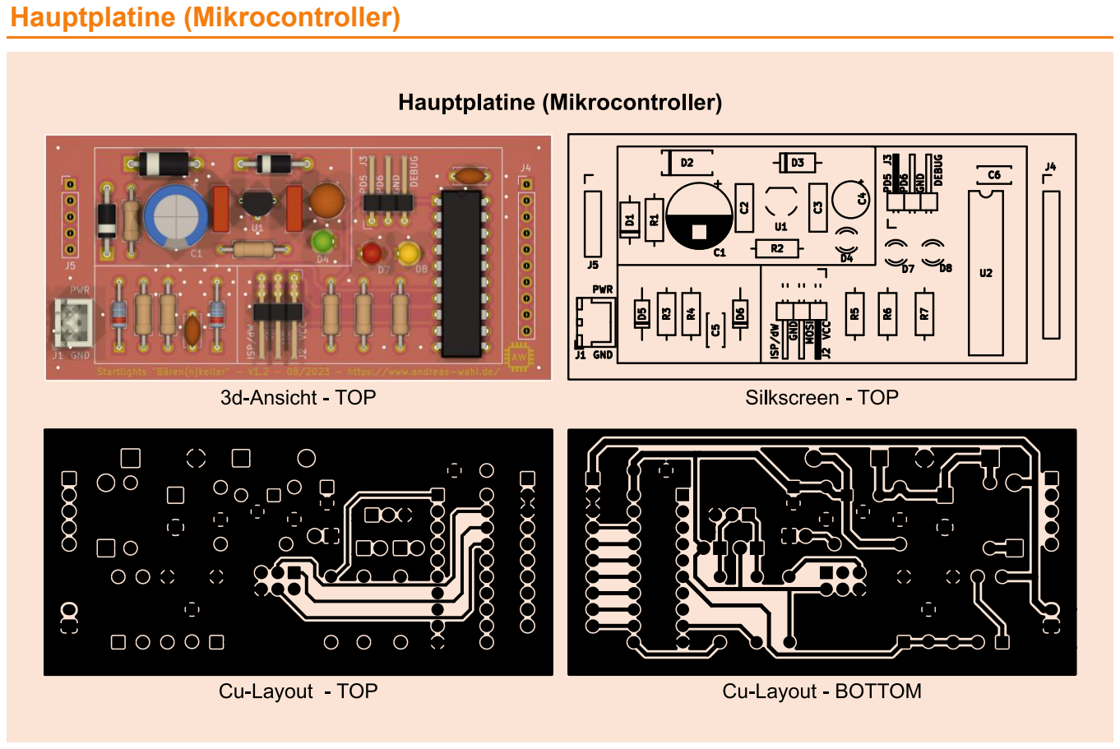
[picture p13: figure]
Hauptplatine (Mikrocontroller)
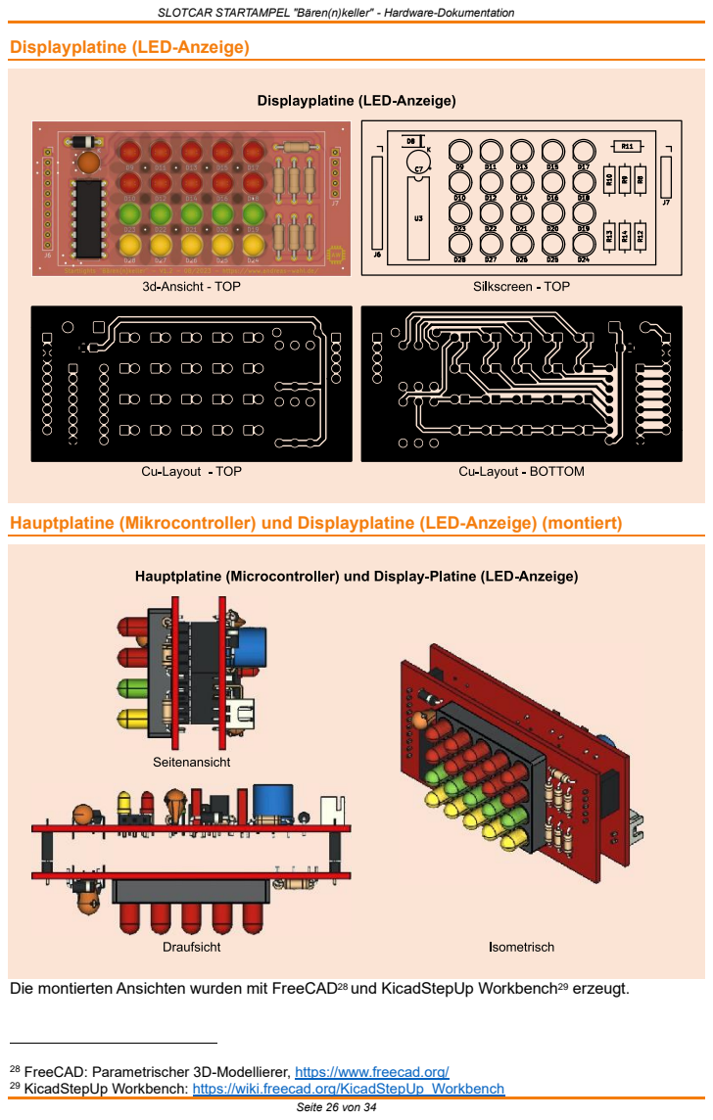
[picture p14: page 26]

Displayplatine (LED-Anzeige)

Hauptplatine (Mikrocontroller) und Displayplatine (LED-Anzeige) (montiert)

Die montierten Ansichten wurden mit FreeCAD²⁸ und KicadStepUp Workbench²⁹ erzeugt.

28 FreeCAD: Parametrischer 3D-Modellierer, https://www.freecad.org/
29 KicadStepUp Workbench: https://wiki.freecad.org/KicadStepUp_Workbench

### Qualitätsanforderungen

Für die nachfolgende Messungen wurde das Oszilloskop SIGLENT SDS-1204X-E

30 verwendet. Bei
allen Messungen wurden die Masse mit der Ground Spring am Tastkopf direkt in Signalnähe abgegriffen, um Einstreuungen durch Erdschleifen der Masse-Leitungen zu vermeiden. Dies ist insbesondere bei der Messung der Restwelligkeit³¹ (Ripple) von Bedeutung, da hier in Größenordnungen von wenigen Millivolt gemessen wird.

### 5 V-Spannungsversorgung

Zunächst wurde die 5 V-Spannungsversorgung in der Gleichstrombetrachtung gemessen. Für die Zeitbasis wurden 100 µs/Div. gewählt, um eventuelle Einflüsse durch das 10 kHz-Datensignal direkt zu erkennen. Der Messbereich für die Spannung liegt bei 2,00 V/Div. und wurde zur Darstellung der Messergebnisse um -6 V nach unten verschoben.

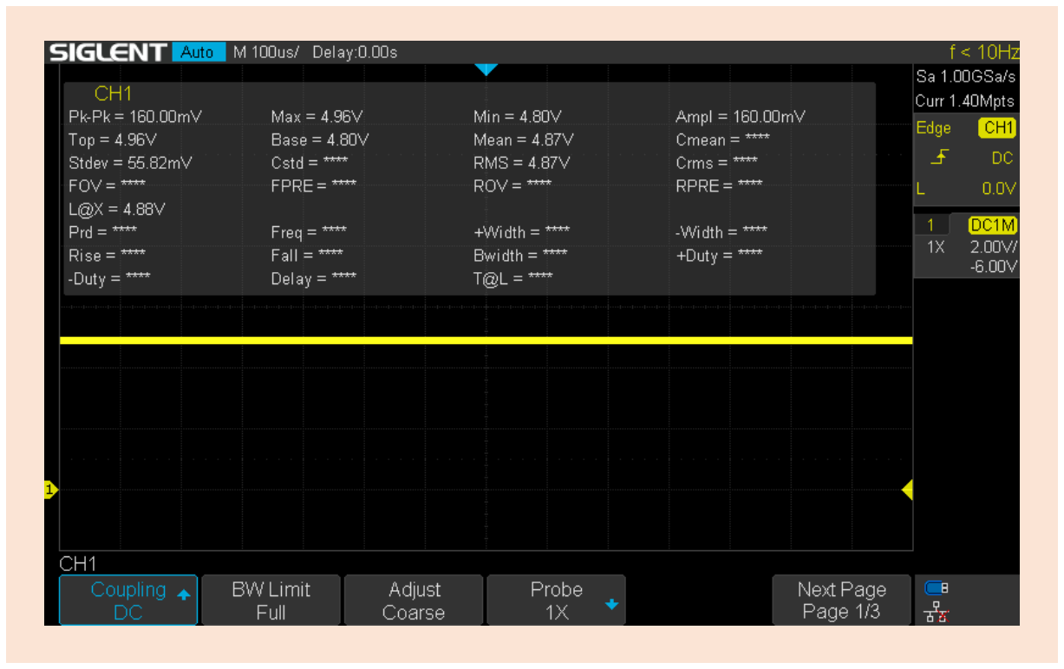
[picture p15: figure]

Die Messung zeigt eine konstante Spannungsversorgung von 4,87 V mit einer durchschnittlichen Restwelligkeit von 55,82 mV. Einzelne Peaks wurden mit +90 mV und -70 mV festgestellt.

Im Wechselstrommodus (AC) lässt sich der Ripple näher betrachten. Die Zeitbasis wurde auf 200 µs/Div. erhöht, um einen größeren Zeitausschnitt zu betrachten. Für den Messbereich der Spannung wurden 5,00 mV/Div. gewählt und zur Anzeige der Messdaten um -10,0 mV nach unten verschoben.

30 SIGLENT SDS1204X-E: https://www.siglent.eu/product/1139259/siglent-sds1204x-e-200mhz-four-channel-oscilloscope (https://www.siglent.eu/product/1139259/siglent-sds1204x-e-200mhz-four-channel-oscilloscope)
31 Restwelligkeit: https://de.wikipedia.org/wiki/Restwelligkeit

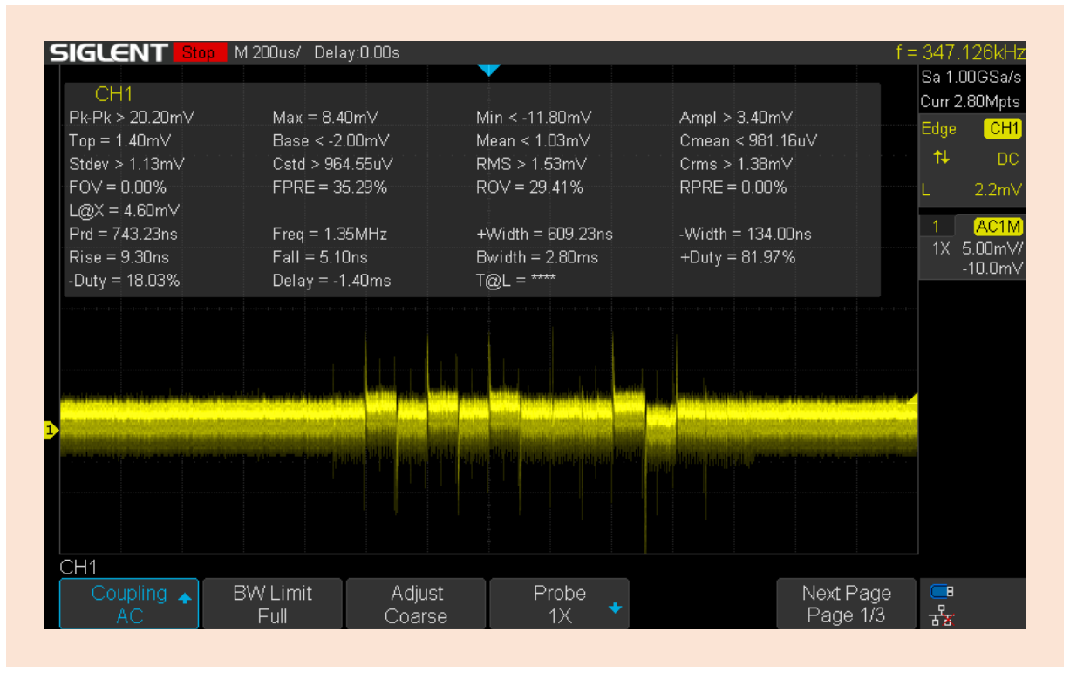
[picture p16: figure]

Zu erkennen sind die trotz Glättung und Siebung verbliebenen Störimpulse, die durch das der auf die Fahrspannung modulierte, steilflankige Datensignal verursacht werden. Diese werden hier mit einer Spitzen-Spitzen-Spannung von 20,2 mVPk-Pk gemessen. Der Maximalwert der Störimpulse liegt bei +8,4 mVMax, der Minimalwert der Störimpulse bei -11,80 mVMin.

Die durchschnittliche Restwelligkeit beträgt 3,4mVAmpl und bewegt sich im Bereich von +1,4 mVTop bis -2,0 mVBase.

Für diesen Anwendungsfall der STARTAMPEL „Bären(n)keller“ wird die erreichte Qualität der Spannungsversorgung als mehr als ausreichend erachtetet.

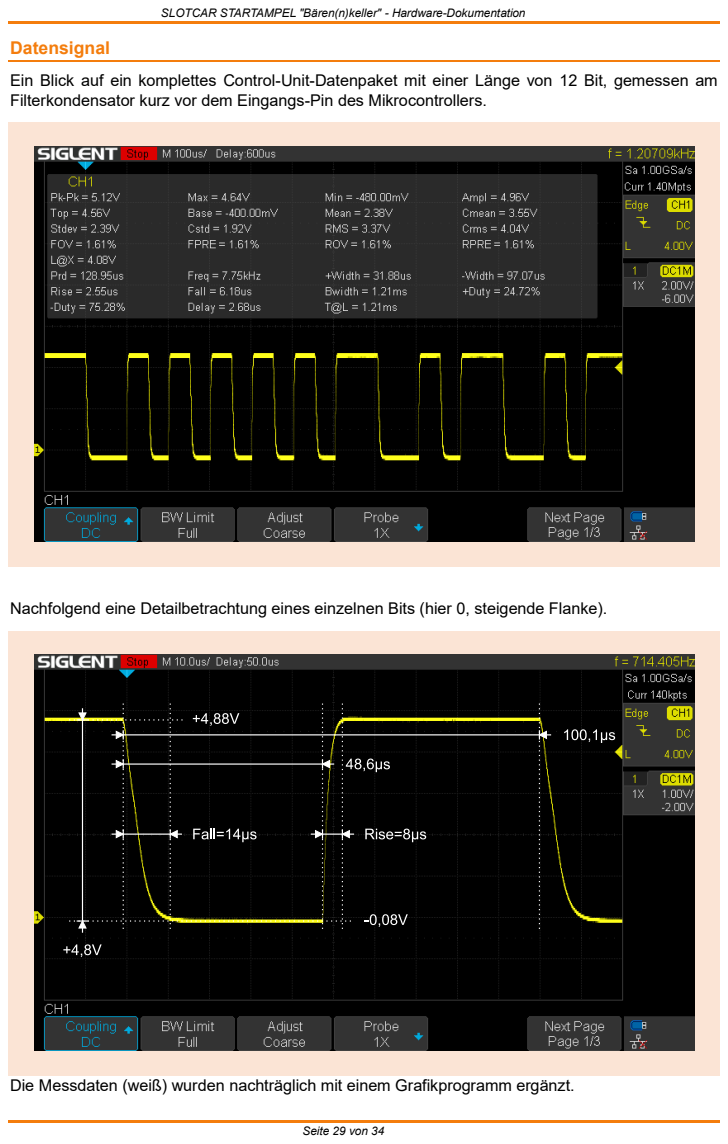
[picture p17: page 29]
Datensignal

Ein Blick auf ein komplettes Control-Unit-Datenpaket mit einer Länge von 12 Bit, gemessen am
Filterkondensator kurz vor dem Eingangs-Pin des Mikrocontrollers.

Nachfolgend eine Detailbetrachtung eines einzelnen Bits (hier 0, steigende Flanke).

Die Messdaten (weiß) wurden nachträglich mit einem Grafikprogramm ergänzt.

### Technische Daten

Funktionen³²:
- Startsequenz
- Pace Car - Anzeige
- Frühstart - Anzeige
- Chaos-/Stop - Anzeige
- Renn-Ende/Sieger - Anzeige³³

Spannungsversorgung (aus Fahrleiter):
digital 132 | 14,8 V
digital 124 | 18,0 V

Stromaufnahme @ 14,8V (digital 132):
maximal: | 110 mA
bei Fahrbetrieb (grün) | 40 mA
bei Start/Chaos (alle rot) ....... 109 mA

Stromaufnahme @ 18V (digital 124):
maximal: | 135 mA
bei Fahrbetrieb (grün) | 50 mA
bei Start/Chaos (alle rot) ....... 132 mA

Decoder:
Assembler Software Decoder für Microchip/Atmel AVR ATtiny 2313
Reaktionszeit: | 125 µs

Abmessungen:
Höhe: | 161 cm
Tiefe: | 44 cm
Breite bei 2 Spuren: | 228 cm
Breite bei 3 Spuren: | 327 cm
Breite bei 4 Spuren: | 426 cm

32 In Verbindung mit der CARRERA® Control Unit (Art.-Nr.: 20030352).
33 Zusätzlich mit dem CARRERA® Lap Counter (Art.-Nr.: 20030355).

### Glossar

arc42 | Frei verfügbares (Open Source) Konzept für die Entwicklung, Dokumentation und zur Kommunikation von Softwareprojekten. https://arc42.org/
Assembler | Maschinenorientierte Programmiersprache https://de.wikipedia.org/wiki/Assemblersprache
AVR® Mikrocontroller | 8 Bit-Mikrocontroller-Familie des US-amerikanischen Herstellers Microchip, vormals Atmel. https://www.microchip.com/en-us/products/microcontrollers-and-microprocessors/8-bit-mcus/avr-mcus (https://www.microchip.com/en-us/products/microcontrollers-and-microprocessors/8-bit-mcus/avr-mcus) https://de.wikipedia.org/wiki/Microchip_AVR
Control-Unit | Zentraleinheit zur Bedienung, Steuerung und Stromversorgung der CARRERA® digital 124/132 Modellrennbahn. CARRERA® Control-Unit (Art.-Nr. 20030352) https://carrera-toys.com/de/product/20030352-control-unit
debugWire | Serielles Übertragungsprotokoll von Atmel (Microchip) für die Programmierung und Fehlersuche bei AVR®-Mikrocontrollern. https://de.wikipedia.org/wiki/DebugWIRE
ISP | Schnittstelle zur Programmierung von AVR®-Mikrocontrollern (In-System Programming).
Lap-Counter | Renncomputer zur Zeitmessung und Zählung der Rennrunden und Steuerung von Rennen als Ergänzung zur CARRERA® Control-Unit. CARRERA® Lap-Counter (Art.-Nr. 20030355) https://carrera-toys.com/de/product/20030355-lap-counter
Oszilloskop | Elektronisches Messgerät, welches den zeitlichen Verlauf von elektrischen Spannungen optisch darstellen kann. https://de.wikipedia.org/wiki/Oszilloskop
SRAM | Static random-access memory https://de.wikipedia.org/wiki/Static_random-access_memory Arbeitsspeicher des Mikrocontrollers
Startampel Startlight | Startampel zur Signalisierung der Startfreigabe für den stehenden Start im Motorsport. https://de.wikipedia.org/wiki/Start_(Motorsport) CARRERA® Startlights (Art.-Nr. 20030354) https://carrera-toys.com/product/20030354-startlight
Startlight „Bären(n)keller“ | Eigenentwicklung einer Startampel mit erweitertem Funktionsumfang. (Start-Sequenz, Früh-Start, Pace-Car, Chaos, Sieger,…) In diesem Dokument beschrieben.

### Ergänzende Informationen

Carrera Toys GmbH

- CARRERA Toys GmbH
https://carrera-toys.com/
- CARRERA® digital 132
https://carrera-toys.com/digital-132
- CARRERA® digital 124
https://carrera-toys.com/digital-124
- CARRERA® Control-Unit (20030352)
https://carrera-toys.com/product/20030352-control-unit
- CARRERA® Handregler/Controller (20030340)
https://carrera-toys.com/product/20030340-digital-132-124-handregler
- CARRERA® Startlight (20030354)
https://carrera-toys.com/product/20030354-startlight
- CARRERA® Lap-Counter (20030355)
https://carrera-toys.com/product/20030355-lap-counter
- CARRERA® Position Tower (20030357)
https://carrera-toys.com/product/20030357-position-tower
- CARRERA® Adapter Unit (20030360)
https://carrera-toys.com/de/product/20030360-adapter-unit
Entwickler-Tools
- KiCAD EDA Suite
Schaltplan und Platinenlayout
https://www.kicad.org/
- Analog Devices LTspice
Simulation von elektronischen Schaltungen
https://www.analog.com/en/design-center/design-tools-and-calculators/ltspice-simulator.html
- Microchip Studio
Software-Entwicklung für Mikrocontroller ATmega/ATtiny in Assembler und C
https://www.microchip.com/en-us/tools-resources/develop/microchip-studio
- FreeCAD
Parametrische 3D-Konstruktionen
https://www.freecadweb.org/
- Ultimaker Cura
3D printing Software / Slicer
https://ultimaker.com/software/ultimaker-cura/
Ähnliche Projekte
- Dipl.-Ing. Peter Niehues
http://www.wasserstoffe.de/carrera-hacks/
- Stephan Heß
http://slotbaer.de/carrera-digital-124-132.html

### Entwickler und Herausgeber

## andreas wahl

Informationstechnik – Kommunikationstechnik – Elektronik innovativ + kompetent + effizient
https://www.andreas-wahl.de/

STARTAMPEL „Bären(n)Keller“ auf GitHub:

- Software
https://github.com/Andreas-Wahl/Startlight-SW
- Hardware
https://github.com/Andreas-Wahl/Startlight-HW
- Gehäuse
https://github.com/Andreas-Wahl/Startlight-3D

STARTAMPEL – Bären(n)keller auf Thingiverse:

- Gehäuse
https://www.thingiverse.com/thing:6443510
- Stecker
https://www.thingiverse.com/thing:6444956

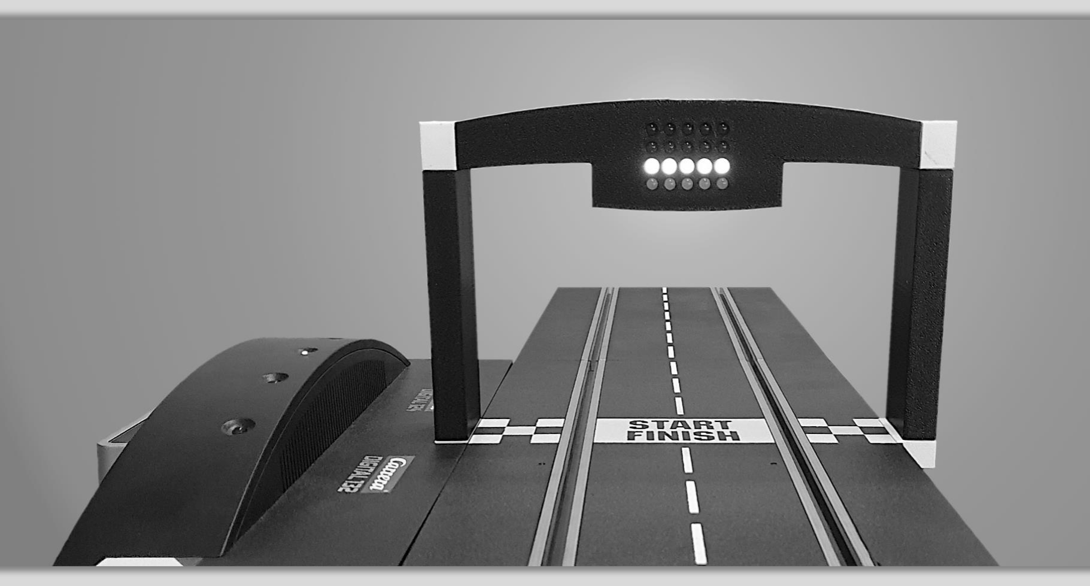
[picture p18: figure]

## andreas wahl

Informationstechnik – Kommunikationstechnik – Elektronik innovativ + kompetent + effizient

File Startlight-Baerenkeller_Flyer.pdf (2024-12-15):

# SLOTCAR STARTAMPEL „Bären(n)keller“

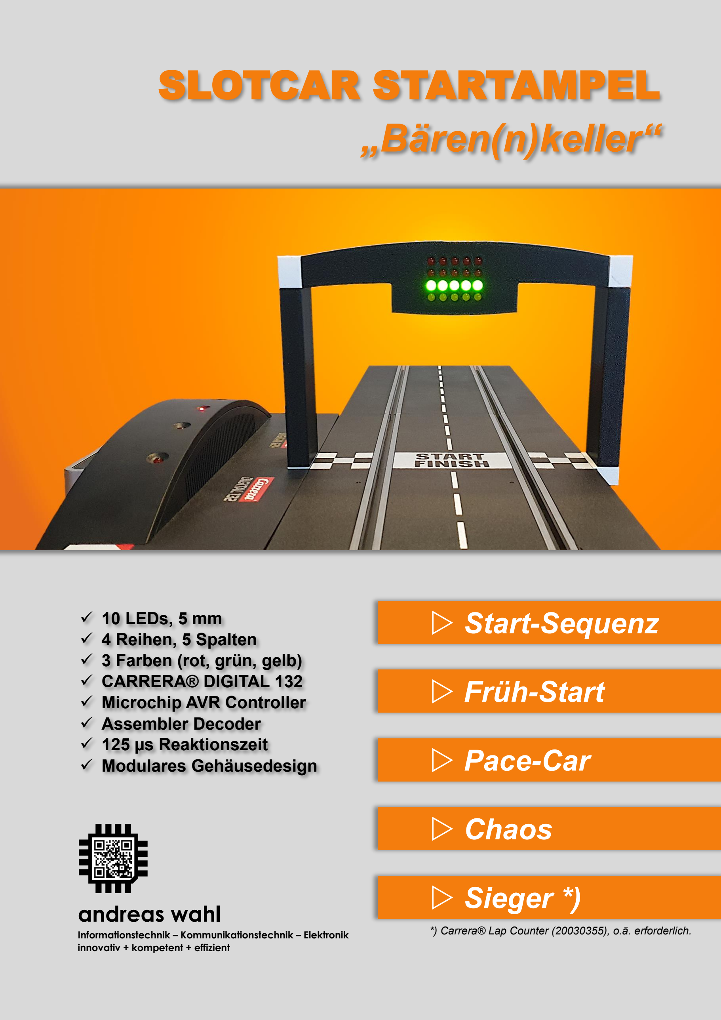
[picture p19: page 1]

# - Start-Sequenz

# - Früh-Start

# - Pace-Car

# - Sieger *)

# - Chaos

✓ 10 LEDs, 5 mm
✓ 4 Reihen, 5 Spalten
✓ 3 Farben (rot, grün, gelb) ✓ CARRERA® DIGITAL 132
✓ Microchip AVR Controller ✓ Assembler Decoder
✓ 125 µs Reaktionszeit
✓ Modulares Gehäusedesign

## andreas wahl

Informationstechnik – Kommunikationstechnik – Elektronik innovativ + kompetent + effizient

*) Carrera® Lap Counter (20030355), o.ä. erforderlich.

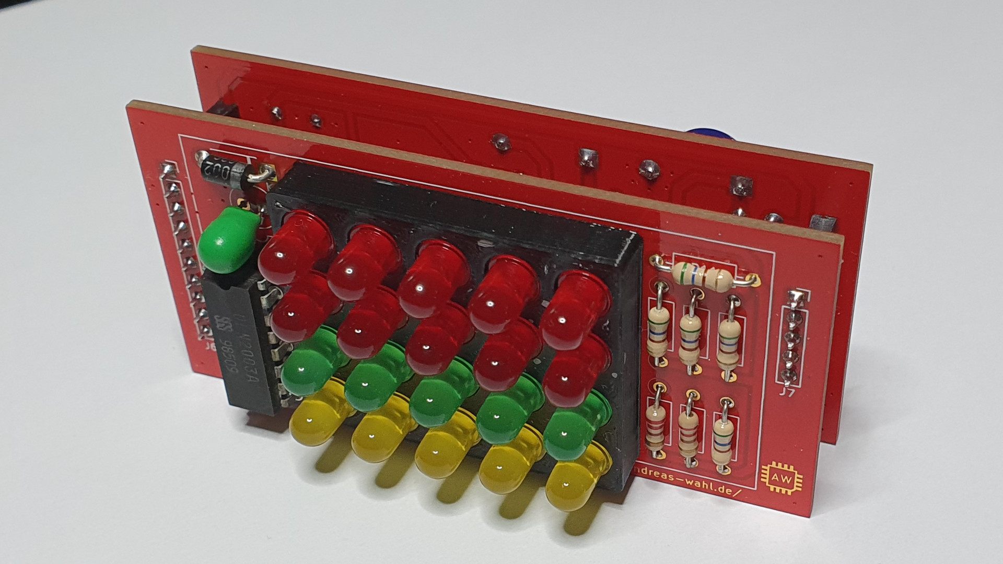
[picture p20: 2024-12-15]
#JPEG/Picture_PCB2-Display.jpeg

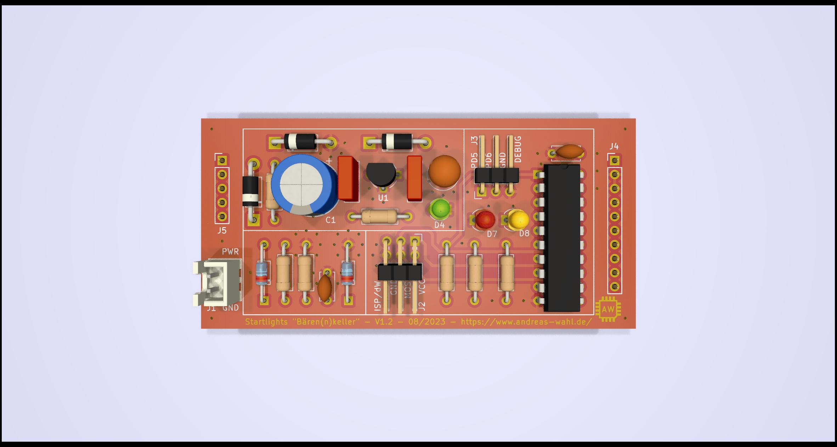
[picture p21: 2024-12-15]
#JPEG/3D-Viewer_PCB1_Mainboard.jpg

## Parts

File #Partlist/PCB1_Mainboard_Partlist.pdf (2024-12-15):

Startlight "Bärenkeller"

### PCB1: MAINBOARD - Stückliste - Version 1.2 - 08/2023

Nr | Platine | Referenz | Wert | Beschreibung | Stückzahl | Best. Nr. (Reichtelt) | Stückpreis | Gesamtpreis
1 | Mainboard | PCB1 | | PCB1_Mainboard_Controller | 1 | | 7,10 EUR | 7,10 EUR
2 | Mainboard | C1 | 220µ/50V | CP_Radial_D10.0mm_P5.00mm | 1 | M-A 220U 63 | 0,38 EUR | 0,38 EUR
3 | Mainboard | C2 | 330n/50V | C_Rect_L7.2mm_W2.5mm_P5.00mm_FKS2_FKP2_MKS2_MKP2 | 1 | MKS2-50 330N | 0,33 EUR | 0,33 EUR
4 | Mainboard | C3 | 100n/16V | C_Rect_L7.2mm_W2.5mm_P5.00mm_FKS2_FKP2_MKS2_MKP2 | 1 | MKS2-63 100N | 0,29 EUR | 0,29 EUR
5 | Mainboard | C4 | 10µ/16V | CP_Radial_Tantal_D5.5mm_P2.50mm | 1 | TANTAL 10/35 | 0,61 EUR | 0,61 EUR
6 | Mainboard | C5 | 2n2 | C_Disc_D5.0mm_W2.5mm_P5.00mm | 1 | KERKO 2,2N | 0,02 EUR | 0,02 EUR
7 | Mainboard | C6 | 100n/16V | C_Disc_D5.0mm_W2.5mm_P5.00mm | 1 | KERKO 100N | 0,03 EUR | 0,03 EUR
8 | Mainboard | R2, R6, R7 | 470R | R_Axial_DIN0207_L6.3mm_D2.5mm_P10.16mm_Horizontal | 3 | 1/4W 470 | 0,12 EUR | 0,36 EUR
9 | Mainboard | R1 | 68R / 0,6W | R_Axial_DIN0207_L6.3mm_D2.5mm_P10.16mm_Horizontal | 1 | METALL 68,0 | 0,07 EUR | 0,07 EUR
10 | Mainboard | R3 | 1k8 | R_Axial_DIN0207_L6.3mm_D2.5mm_P10.16mm_Horizontal | 1 | 1/4W 1,8K | 0,15 EUR | 0,15 EUR
11 | Mainboard | R4 | 1k0 | R_Axial_DIN0207_L6.3mm_D2.5mm_P10.16mm_Horizontal | 1 | 1/4W 1,0K | 0,11 EUR | 0,11 EUR
12 | Mainboard | R5 | 15k | R_Axial_DIN0207_L6.3mm_D2.5mm_P10.16mm_Horizontal | 1 | 1/4W 15K | 0,10 EUR | 0,10 EUR
13 | Mainboard | D1, D3 | 1N4001 | D_DO-41_SOD81_P10.16mm_Horizontal | 2 | 1N 4001 | 0,03 EUR | 0,06 EUR
14 | Mainboard | D2 | 24V 1,3W | D_DO-41_SOD81_P10.16mm_Horizontal | 1 | BZX 85C24 VIS | 0,09 EUR | 0,09 EUR
15 | Mainboard | D4 | gn/3mm | LED_D3.0mm-gn | 1 | LED 3MM ST GN | 0,15 EUR | 0,15 EUR
16 | Mainboard | D5 | 1N4148 | D_DO-35_SOD27_P10.16mm_Horizontal | 1 | 1N 4148 DIO | 0,02 EUR | 0,02 EUR
17 | Mainboard | D6 | 5V1 | D_DO-35_SOD27_P10.16mm_Horizontal | 1 | BZX 85C5V1 VIS | 0,08 EUR | 0,08 EUR
18 | Mainboard | D7 | rt/3mm | LED_D3.0mm-rd | 1 | LED 3MM ST RT | 0,18 EUR | 0,18 EUR
19 | Mainboard | D8 | ge/3mm | LED_D3.0mm-ye | 1 | LED 3MM ST GE | 0,15 EUR | 0,15 EUR
20 | Mainboard | D4, D7, D8 | LED/Halter/3mm | LED_Halter_D3.00mm_L5.00mm | 3 | MEN 2818.3045 | 0,25 EUR | 0,75 EUR
21 | Mainboard | U1 | L78L05_TO92 | TO-92_Wide | 1 | MC 78L05 ACPG | 0,24 EUR | 0,24 EUR
22 | Mainboard | U2 | ATtiny2313A-P | DIP-20_W7.62mm | 1 | ATTINY 2313 DIP | 2,45 EUR | 2,45 EUR
23 | Mainboard | J1 | CARRERA_PWR | JST_XH_B2B-XH-A_1x02_P2.50mm_Vertical | 1 | JST XH2P ST | 0,15 EUR | 0,15 EUR
24 | Mainboard | J1 | CARRERA_PWR | JST_XH_B2B-XH-A_1x02_P2.50mm_Vertical | 1 | JST XH2P BU | 0,06 EUR | 0,06 EUR
25 | Mainboard | J1 | CARRERA_PWR | JST_XH_B2B-XH-A_1x02_P2.50mm_Vertical | 2 | JST XH CKB | 0,13 EUR | 0,26 EUR
26 | Mainboard | J2 | ISP/DebugWire | PinHeader_2x03_P2.54mm_Horizontal | 1 | MPE 088-2-006 | 0,33 EUR | 0,33 EUR
27 | Mainboard | J3 | DebugPins | PinHeader_1x03_P2.54mm_Horizontal | 1 | SL1X50W 2,54 | 2,05 EUR | 2,05 EUR
28 | Mainboard | J4 | LED_OUT | PinSocket_1x10_P2.54mm_Vertical | 1 | MPE 094-1-005 | 0,29 EUR | 0,29 EUR
29 | Mainboard | J5 | HALTER | PinSocket_1x05_P2.54mm_Vertical | 1 | MPE 094-1-010 | 0,31 EUR | 0,31 EUR
Preise inklusive Mehrwertsteuer zum Zeitpunkt der Auflistung. Verfügbarkeit und Preise jeweils neu nachfragen! | SUMME | 17,17 EUR

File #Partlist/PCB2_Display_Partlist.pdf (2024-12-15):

Startlight "Bärenkeller"

### PCB2: DISPLAY - Stückliste - Version 1.2 - 08/2023

Nr | Platine | Referenz | Wert | Beschreibung | Stückzahl | Best. Nr. (Reichelt) | Stückpreis | Gesamtpreis
1 | Display | PCB2 | | PCB2_Display | 1 | | 7,10 EUR | 7,10 EUR
2 | Display | C7 | 10uF/50V | CP_Radial_Tantal_D5.5mm_P2.50mm | 1 | TANTAL 10/35 | 0,61 EUR | 0,61 EUR
3 | Display | R8, R9, R10, R11, R12 | 560R | R_Axial_DIN0207_L6.3mm_D2.5mm_P10.16mm_Horizontal | 5 | 1/4W 560 | 0,06 EUR | 0,30 EUR
4 | Display | R13, R14 | 220R | R_Axial_DIN0207_L6.3mm_D2.5mm_P10.16mm_Horizontal | 2 | 1/4W 220 | 0,11 EUR | 0,22 EUR
5 | Display | D9, D10, D11, D12, D13, D14, D15, D16, D17, D18 | rt/5mm | LED_D5.0mm_rd | 10 | LED 5MM ST RT | 0,17 EUR | 1,70 EUR
6 | Display | D19, D20, D21, D22, D23 | gn/5mm | LED_D5.0mm_gn | 5 | LED 5MM ST GN | 0,14 EUR | 0,70 EUR
7 | Display | D24, D25, D26, D27, D28 | ge/5mm | LED_D5.0mm_ye | 5 | LED 5MM ST GE | 0,15 EUR | 0,75 EUR
8 | Display | D9-28 | LED/Halter/5mm | LED_Halter_D5.00mm_L5.00mm | 20 | MEN 2819.5045 | 0,25 EUR | 5,00 EUR
9 | Display | D8 | 1N4001 | D_DO-41_SOD81_P7.62mm_Horizontal | 1 | 1N 4001 | 0,03 EUR | 0,03 EUR
10 | Display | U3 | ULN2003A | DIP-16_W7.62mm | 1 | ULN 2003A STM | 0,30 EUR | 0,30 EUR
11 | Display | J6 | LED_IN | PinHeader_1x10_P2.54mm_Vertical | 1 | MPE 087-1-010 | 0,25 EUR | 0,25 EUR
12 | Display | J7 | HALTER | PinHeader_1x05_P2.54mm_Vertical | 1 | MPE 087-1-005 | 0,14 EUR | 0,14 EUR
Preise inklusive Mehrwertsteuer zum Zeitpunkt der Auflistung. Verfügbarkeit und Preise jeweils neu nachfragen! | SUMME | 17,10 EUR

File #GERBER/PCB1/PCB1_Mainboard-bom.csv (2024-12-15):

Designator | Quantity | Value | Footprint | Package | MPN | DNP | Mount_Type | Sim.Device | Sim.Pins
C1 | 1 | 220µ/50V | CP_Radial_D10.0mm_P5.00mm |  |  |  | tht
C2 | 1 | 330n/50V | C_Rect_L7.2mm_W2.5mm_P5.00mm_FKS2_FKP2_MKS2_MKP2 |  |  |  | tht
C3 | 1 | 100n/16V | C_Rect_L7.2mm_W2.5mm_P5.00mm_FKS2_FKP2_MKS2_MKP2 |  |  |  | tht
C4 | 1 | 10µ/16V | CP_Radial_Tantal_D5.5mm_P2.50mm |  |  |  | tht
C5 | 1 | 150p/16V | C_Disc_D5.0mm_W2.5mm_P5.00mm |  |  |  | tht
C6 | 1 | 100n/16V | C_Disc_D5.0mm_W2.5mm_P5.00mm |  |  |  | tht
D1, D3 | 2 | 1N4001 | D_DO-41_SOD81_P10.16mm_Horizontal |  |  |  | tht | D | 1=K 2=A
D2 | 1 | 24V/1,3W | D_DO-41_SOD81_P10.16mm_Horizontal |  |  |  | tht
D4 | 1 | gn/3mm | LED_D3.0mm-gn |  |  |  | tht
D5 | 1 | 1N4148 | D_DO-35_SOD27_P10.16mm_Horizontal |  |  |  | tht | D | 1=K 2=A
D6 | 1 | 5V1/0,5W | D_DO-35_SOD27_P10.16mm_Horizontal |  |  |  | tht
D7 | 1 | rt/3mm | LED_D3.0mm-rd |  |  |  | tht
D8 | 1 | ge/3mm | LED_D3.0mm-ye |  |  |  | tht
J1 | 1 | CARRERA_PWR | JST_XH_B2B-XH-A_1x02_P2.50mm_Vertical |  |  |  | tht
J2 | 1 | ISP/DebugWire | PinHeader_2x03_P2.54mm_Horizontal |  |  |  | tht
J3 | 1 | DebugPins | PinHeader_1x03_P2.54mm_Horizontal |  |  |  | tht
J4 | 1 | LED_OUT | PinSocket_1x10_P2.54mm_Vertical |  |  |  | tht
J5 | 1 | HALTER | PinSocket_1x05_P2.54mm_Vertical |  |  |  | tht
R1 | 1 | 68R/0,6W | R_Axial_DIN0207_L6.3mm_D2.5mm_P10.16mm_Horizontal |  |  |  | tht
R2, R6, R7 | 3 | 470R | R_Axial_DIN0207_L6.3mm_D2.5mm_P10.16mm_Horizontal |  |  |  | tht
R3 | 1 | 1k8 | R_Axial_DIN0207_L6.3mm_D2.5mm_P10.16mm_Horizontal |  |  |  | tht
R4 | 1 | 1k0 | R_Axial_DIN0207_L6.3mm_D2.5mm_P10.16mm_Horizontal |  |  |  | tht
R5 | 1 | 15k | R_Axial_DIN0207_L6.3mm_D2.5mm_P10.16mm_Horizontal |  |  |  | tht
U1 | 1 | L78L05_TO92 | TO-92_Wide |  |  |  | tht
U2 | 1 | ATtiny2313A-P | DIP-20_W7.62mm |  |  |  | tht

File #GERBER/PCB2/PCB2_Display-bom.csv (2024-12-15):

Designator | Quantity | Value | Footprint | Package | MPN | DNP | Mount_Type | Description | Sim.Device | Sim.Pins
C7 | 1 | 10uF/50V | CP_Radial_Tantal_D5.5mm_P2.50mm |  |  |  | tht | Polarized capacitor
D10, D11, D12, D13, D14, D15, D16, D17, D18, D9 | 10 | rt/5mm | LED_D5.0mm_rd |  |  |  | tht | Light emitting diode
D19, D20, D21, D22, D23 | 5 | gn/5mm | LED_D5.0mm_gn |  |  |  | tht | Light emitting diode
D24, D25, D26, D27, D28 | 5 | ge/5mm | LED_D5.0mm_ye |  |  |  | tht | Light emitting diode
D8 | 1 | 1N4001 | D_DO-41_SOD81_P7.62mm_Horizontal |  |  |  | tht | 50V 1A General Purpose Rectifier Diode, DO-41 | D | 1=K 2=A
J6 | 1 | LED_IN | PinHeader_1x10_P2.54mm_Vertical |  |  |  | tht | Generic connector, single row, 01x10, script generated
J7 | 1 | HALTER | PinHeader_1x05_P2.54mm_Vertical |  |  |  | tht | Generic connector, single row, 01x05, script generated
R10, R11, R12, R8, R9 | 5 | 560R | R_Axial_DIN0207_L6.3mm_D2.5mm_P10.16mm_Horizontal |  |  |  | tht | Resistor
R13, R14 | 2 | 220R | R_Axial_DIN0207_L6.3mm_D2.5mm_P10.16mm_Horizontal |  |  |  | tht | Resistor
U3 | 1 | ULN2003A | DIP-16_W7.62mm |  |  |  | tht | High Voltage, High Current Darlington Transistor Arrays, SOIC16/SOIC16W/DIP16/TSSOP16

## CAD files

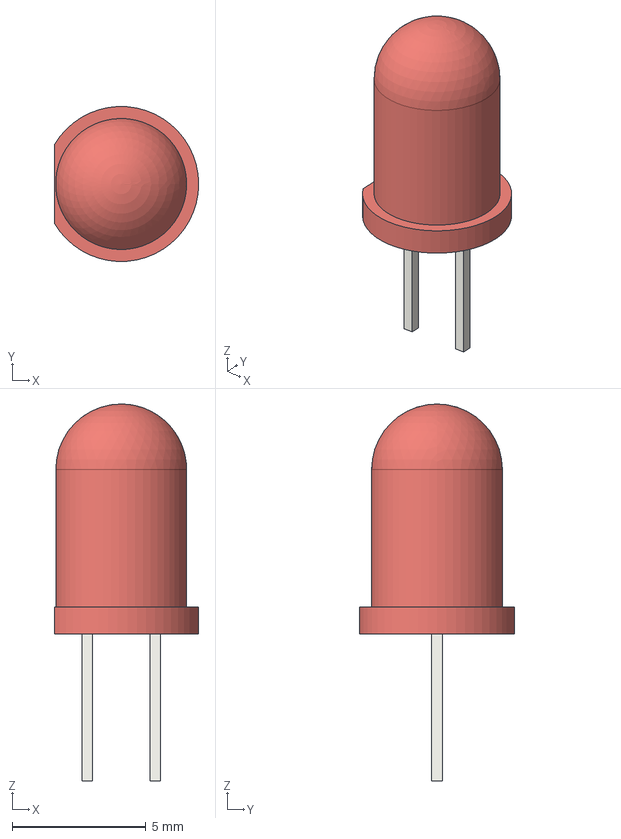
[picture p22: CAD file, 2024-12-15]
KiCAD/ProjectLibraries/3dmodels/LED_D5.0mm_rd.step
5.40 x 5.79 x 14.1 mm

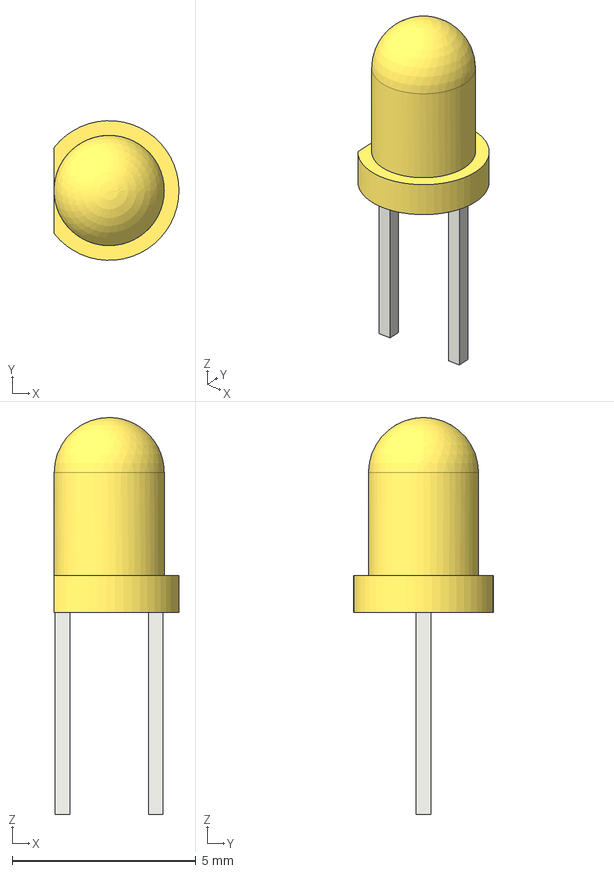
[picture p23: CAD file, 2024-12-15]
KiCAD/ProjectLibraries/3dmodels/LED_D3.0mm_ye.step
3.40 x 3.80 x 10.8 mm

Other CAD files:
KiCAD/ProjectLibraries/3dmodels/LED_D5.0mm_gn.step
KiCAD/ProjectLibraries/3dmodels/LED_D5.0mm_ye.step
KiCAD/ProjectLibraries/3dmodels/LED_D3.0mm_gn.step
KiCAD/ProjectLibraries/3dmodels/LED_D3.0mm_rd.step

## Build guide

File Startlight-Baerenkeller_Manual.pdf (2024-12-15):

# SLOTCAR STARTAMPEL „Bären(n)keller“

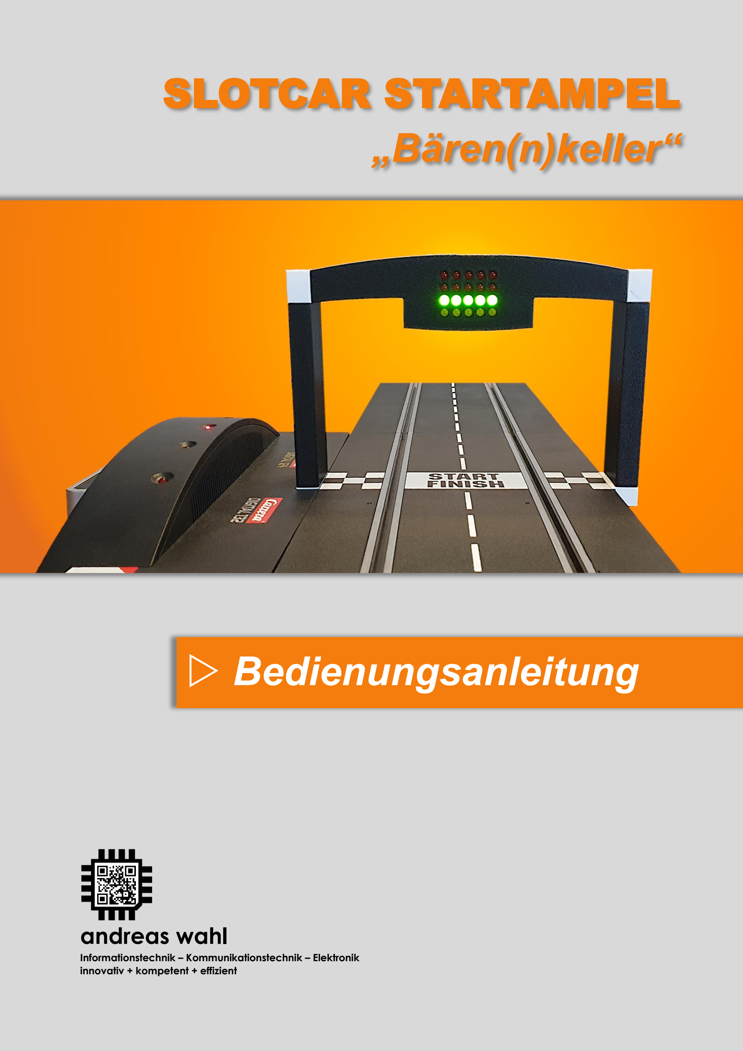
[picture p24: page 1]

SLOTCAR STARTAMPEL "Bären(n)keller" - Bedienungsanleitung

# - Bedienungsanleitung

## andreas wahl

Informationstechnik – Kommunikationstechnik – Elektronik innovativ + kompetent + effizient

# SLOTCAR STARTAMPEL

# „Bären(n)keller“

# Bedienungsanleitung

# Version 1.0 - 31.01.2024

Software-Version: 1.0
https://github.com/Andreas-Wahl/Startlight-SW
Hardware-Version: 1.3
https://github.com/Andreas-Wahl/Startlight-HW
Gehäuse-Version 1.0
https://github.com/Andreas-Wahl/Startlight-3D

## andreas wahl

Informationstechnik – Kommunikationstechnik – Elektronik innovativ + kompetent + effizient
https:/www.andreas-wahl.de/

### Inhaltsverzeichnis

### Idee und Namensgebung

In einer bereits über zwei Generationen
bestehenden | privaten | Kellerbar, | die
ursprünglich | den | Namen | „Bärenkeller“
erhalten hat, wurde eine CARRERA® digital 132 Rennbahn aufgebaut und die ersten Rennen ausgetragen.
Schnell | fand | dies | bei | Freunden | und
Bekannten großen Anklang. So wurde die Rennbahn sukzessive weiter ausgebaut und über mögliche Erweiterungen diskutiert.

So entstand auch die Idee einer eigenen Startampel, da die originale Startampel CARRERA® Startlight (30354) nicht über drei Fahrspuren (zwei Fahrspuren + Boxengasse) überbrücken kann. Weiter sollte die eigene Startampel nicht nur die Start-Sequenz über rote Anzeigen darstellen können, sondern auch den freigegebenen Rennbetrieb mit grünen LEDs, den Safety-Car-/Pace-Car-Betrieb und einen Frühstart anzeigen.

Kurzerhand wurde die Idee aufgegriffen, das Datensignal mit Oszilloskop und Datenlogger analysiert und die Entwicklung von Hardware, Software und Gehäuse-Design angestoßen.

In Bezug auf den „Bärenkeller“, welcher durch die Erweiterung der CARRERA® digital 132 Rennbahn zum „Bärennkeller“ umbenannt wurde, erhielt auch die selbst entwickelte
Startampel | den | Namen | „STARTAMPEL
„Bären(n)keller““.

Die STARTAMPEL „Bären(n)keller“ fand so großen Anklang, dass sich der Entwickler entschlossen hat, eine kleine Menge als
„Prototypen“ | zu | produzieren | und | die
Entwicklung für nicht kommerzielle Nutzung zur Verfügung zu stellen.

Die Elektronik und das Gehäusedesign sind unter der Creative Commons Version 4.0 Lizenz „Namensnennung, nicht kommerziell, Weitergabe unter gleichen Bedingungen (CC BY-NC-SA 4.0)“ und die Software unter der „GNU Affero General Public License, Version 3.0“ veröffentlicht.

1
In Verbindung mit der CARRERA® Control Unit (Art.-Nr.: 20030352).

### Technische Daten

Funktionen¹
:
- Startsequenz
- PACE CAR - Anzeige
- Frühstart - Anzeige
- CHAOS-/STOP - Anzeige
- Renn-Ende/Sieger - Anzeige²

Spannungsversorgung (aus Fahrleiter):
digital 132 | 14,8 V
digital 124 | 18,0 V

Stromaufnahme @ 14,8V (digital 132):
maximal: | 110 mA
bei Fahrbetrieb (grün) | 40 mA
bei Start/Chaos (alle rot) | 109 mA

Stromaufnahme @ 18V (digital 124):
maximal: | 135 mA
bei Fahrbetrieb (grün) | 50 mA
bei Start/Chaos (alle rot) | 132 mA

Decoder:
Assembler Software Decoder für Microchip/Atmel AVR ATtiny 2313
Reaktionszeit: | 125 µs

Abmessungen:
Höhe: | 161 cm
Tiefe: | 44 cm
Breite bei 2 Spuren | 228 cm
Breite bei 3 Spuren | 327 cm
Breite bei 4 Spuren | 426 cm

2 Zusätzlich mit dem CARRERA® Lap Counter (Art.-Nr.: 20030355).

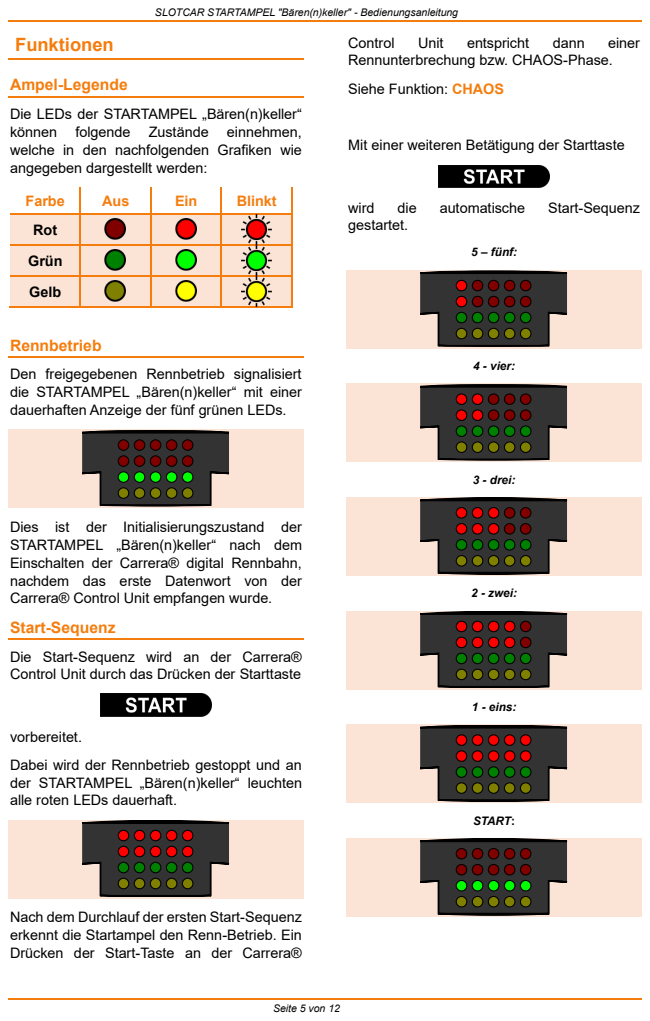
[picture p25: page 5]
Funktionen; Ampel-Legende; können; folgende; Zustände; einnehmen,; Farbe; Aus; Ein; Blinkt; Rot; Grün; Gelb; Rennbetrieb; Dies; ist; der Initialisierungszustand; der; Start-Sequenz; vorbereitet.; Control; Unit; entspricht; dann; einer; wird; die; automatische; gestartet.; 5 – fünf:; 4 - vier:; 3 - drei:; 2 - zwei:; 1 - eins:; START:

Rennunterbrechung bzw. CHAOS-Phase.

Siehe Funktion: CHAOS

Die LEDs der STARTAMPEL „Bären(n)keller“
welche in den nachfolgenden Grafiken wie
angegeben dargestellt werden:

Mit einer weiteren Betätigung der Starttaste

Den freigegebenen Rennbetrieb signalisiert
die STARTAMPEL „Bären(n)keller“ mit einer
dauerhaften Anzeige der fünf grünen LEDs.

STARTAMPEL „Bären(n)keller“ nach dem
Einschalten der Carrera® digital Rennbahn,
nachdem das erste Datenwort von der
Carrera® Control Unit empfangen wurde.

Die Start-Sequenz wird an der Carrera®
Control Unit durch das Drücken der Starttaste

Dabei wird der Rennbetrieb gestoppt und an
der STARTAMPEL „Bären(n)keller“ leuchten
alle roten LEDs dauerhaft.

Nach dem Durchlauf der ersten Start-Sequenz
erkennt die Startampel den Renn-Betrieb. Ein
Drücken der Start-Taste an der Carrera®

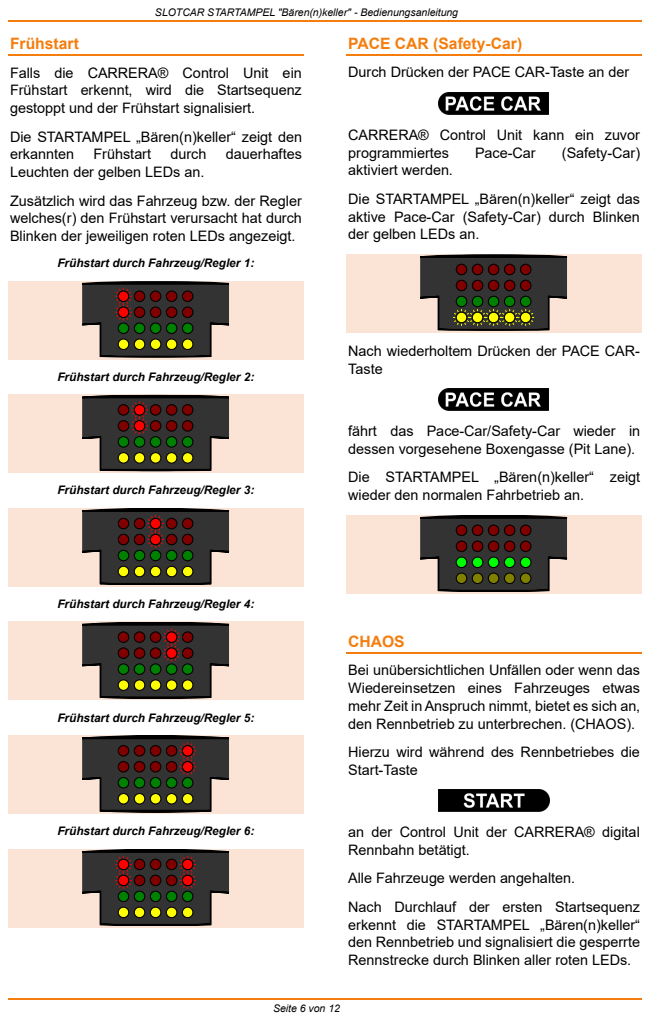
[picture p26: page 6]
Frühstart; erkannten; durch; dauerhaftes; programmiertes; Pace-Car; (Safety-Car); CHAOS

PACE CAR (Safety-Car)

Falls die CARRERA® Control Unit ein
Frühstart erkennt, wird die Startsequenz
gestoppt und der Frühstart signalisiert.

Durch Drücken der PACE CAR-Taste an der

Die STARTAMPEL „Bären(n)keller“ zeigt den
Leuchten der gelben LEDs an.

CARRERA® Control Unit kann ein zuvor
aktiviert werden.

Zusätzlich wird das Fahrzeug bzw. der Regler
welches(r) den Frühstart verursacht hat durch
Blinken der jeweiligen roten LEDs angezeigt.

Die STARTAMPEL „Bären(n)keller“ zeigt das
aktive Pace-Car (Safety-Car) durch Blinken
der gelben LEDs an.

Frühstart durch Fahrzeug/Regler 1:

Nach wiederholtem Drücken der PACE CAR-
Taste

Frühstart durch Fahrzeug/Regler 2:

fährt das Pace-Car/Safety-Car wieder in
dessen vorgesehene Boxengasse (Pit Lane).

Die STARTAMPEL „Bären(n)keller“ zeigt
wieder den normalen Fahrbetrieb an.

Frühstart durch Fahrzeug/Regler 3:

Frühstart durch Fahrzeug/Regler 4:

Bei unübersichtlichen Unfällen oder wenn das
Wiedereinsetzen eines Fahrzeuges etwas
mehr Zeit in Anspruch nimmt, bietet es sich an,
den Rennbetrieb zu unterbrechen. (CHAOS).

Frühstart durch Fahrzeug/Regler 5:

Hierzu wird während des Rennbetriebes die
Start-Taste

Frühstart durch Fahrzeug/Regler 6:

an der Control Unit der CARRERA® digital
Rennbahn betätigt.

Alle Fahrzeuge werden angehalten.

Nach Durchlauf der ersten Startsequenz
erkennt die STARTAMPEL „Bären(n)keller“
den Rennbetrieb und signalisiert die gesperrte
Rennstrecke durch Blinken aller roten LEDs.

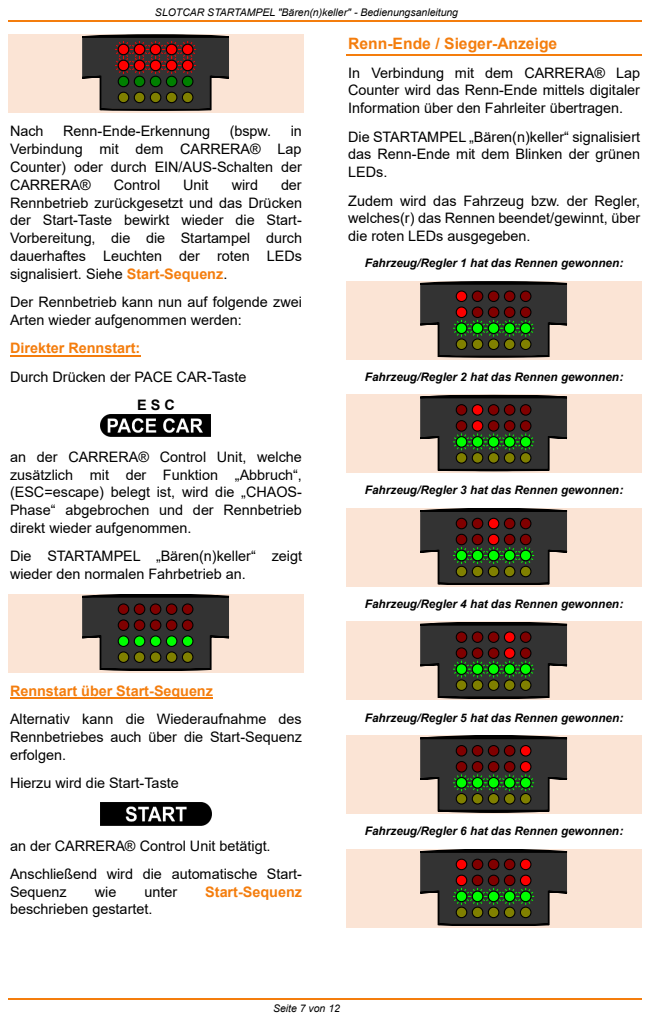
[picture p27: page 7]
Nach; Renn-Ende-Erkennung; (bspw.; Verbindung; mit; dem; CARRERA®; Lap; Control; Unit; wird; der; dauerhaftes; Leuchten; roten; LEDs; Direkter Rennstart:; zusätzlich; Funktion; „Abbruch“,; Sequenz; wie; unter; Start-Sequenz

Renn-Ende / Sieger-Anzeige

In Verbindung mit dem CARRERA® Lap
Counter wird das Renn-Ende mittels digitaler
Information über den Fahrleiter übertragen.

Counter) oder durch EIN/AUS-Schalten der
Rennbetrieb zurückgesetzt und das Drücken
der Start-Taste bewirkt wieder die Start-
Vorbereitung, die die Startampel durch
signalisiert. Siehe Start-Sequenz.

Die STARTAMPEL „Bären(n)keller“ signalisiert
das Renn-Ende mit dem Blinken der grünen
LEDs.

Zudem wird das Fahrzeug bzw. der Regler,
welches(r) das Rennen beendet/gewinnt, über
die roten LEDs ausgegeben.

Fahrzeug/Regler 1 hat das Rennen gewonnen:

Der Rennbetrieb kann nun auf folgende zwei
Arten wieder aufgenommen werden:

Durch Drücken der PACE CAR-Taste

Fahrzeug/Regler 2 hat das Rennen gewonnen:

an der CARRERA® Control Unit, welche
(ESC=escape) belegt ist, wird die „CHAOS-
Phase“ abgebrochen und der Rennbetrieb
direkt wieder aufgenommen.

Fahrzeug/Regler 3 hat das Rennen gewonnen:

Die STARTAMPEL „Bären(n)keller“ zeigt
wieder den normalen Fahrbetrieb an.

Fahrzeug/Regler 4 hat das Rennen gewonnen:

Rennstart über Start-Sequenz

Alternativ kann die Wiederaufnahme des
Rennbetriebes auch über die Start-Sequenz
erfolgen.

Fahrzeug/Regler 5 hat das Rennen gewonnen:

Hierzu wird die Start-Taste

Fahrzeug/Regler 6 hat das Rennen gewonnen:

an der CARRERA® Control Unit betätigt.

Anschließend wird die automatische Start-
beschrieben gestartet.

### Aufbau der STARTAMPEL

Die STARTAMPEL „Bären(n)keller ist modular
aufgebaut | und | kann | mittels | optionaler
Verlängerungen zwei, drei, vier oder mehrere Fahrspuren überbrücken.

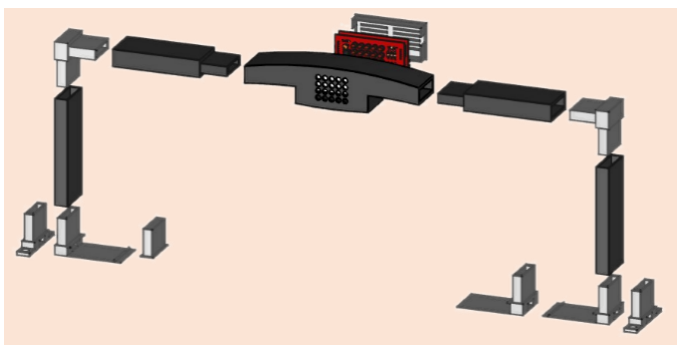
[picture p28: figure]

Verschiedene Montagefüße erlauben die Befestigung an

- einer Standardgeraden,
- der CARRERA ® Control Unit (Start/Ziel-Linie),
- oder per Verschraubung auf einer Montageplatte.

Die STARTAMPEL „Bären(n)keller“ kann somit nahezu jedem Aufbau der Rennstrecke flexibel angepasst werden.

Ampel-Brücke

Die Ampel-Brücke ist das grundlegende
Element | und | Gesicht | der | Start-Ampel
„Bären(n)keller“.

Durch die Brücke wird die Breite einer
Standard-Geraden | (zwei | Fahrspuren)
überbrückt.

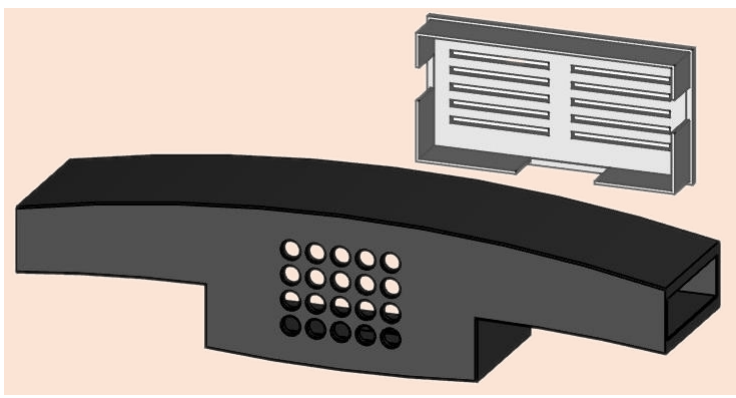
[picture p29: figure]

Nach dem Einsetzen der Elektronik und dem
Durchführen | und | Anschließen | der
Versorgungsleitung wird der Deckel rückseitig aufgesteckt.

Elektronik

Die Elektronik besteht aus zwei Platinen.

Eine Platine enthält den Microcontroller und die zur Auswertung des Manchester-Signals erforderlichen Komponenten. Die andere Platine enthält die LEDs, die Treiber und deren notwendiger Beschaltung.

Beide Platinen werden jeweils rückseitig zusammengesteckt.

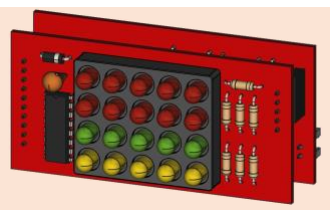
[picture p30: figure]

Die Elektronik wird mit den LEDs voran in die Brücke der STARTAMPEL „Bären(n)keller“ so eingesetzt, dass die LEDs durch die dafür vorgesehenen Löcher ragen. Die roten LED-Reihen zeigen dabei nach oben.

Verlängerungen [optional]

Mit | den | optionalen | waagerechten
Verlängerungen kann die Brücke um jeweils eine Fahrspurbreite erweitert werden.

Die Verlängerungen sind identisch und können sowohl rechts als auch links der Brücke angebracht werden.

Winkel-Verbinder

Zur Verbindung der senkrechten Säulen mit der Ampel-Brücke bzw. den Verlängerungen dienen die folgenden Winkelverbinder.

Säulen

Die senkrechten Säulen werden mit den
Winkelverbindern | und | mit | den | Füßen
verbunden.

Füße

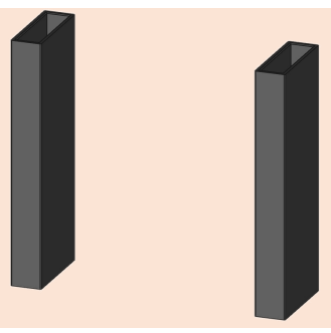
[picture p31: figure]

Montage an Standardgeraden

Zur Befestigung an einer Standardgeraden, bspw. direkt nach der CARRERA® Control Unit stehen L-Füße mit Arretierung zur Verfügung.

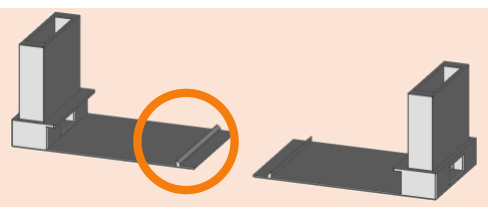
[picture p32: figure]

Diese L-Füße werden von der Seite an die Fahrbahn gesteckt und rasten unterhalb der Fahrbahn ein.

So hat die STARTAMPEL „Bären(n)keller den besten Halt.

Montage an Control Unit

Um die STARTAMPEL “Bären(n)keller“ direkt an der Start-/Ziellinie der CARRERA® Control Unit anzubringen, werden angepasste Füße benötigt.

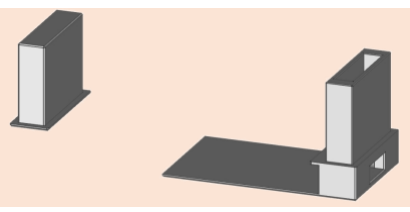
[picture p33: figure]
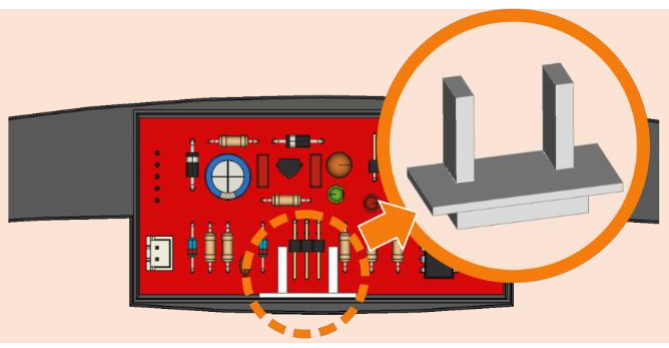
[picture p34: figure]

Auf der linken Seite wird ein „Blindstopfen“ benötigt, da hier die Ampel auf dem Randstreifen aufliegt.
Zur weiteren Befestigung kann hier bei Bedarf doppelseitiges Klebeband oder Klettstreifen verwendet werden.

Die rechte Seite kann mit einem L-Fuß unter die Fahrbahn gesteckt werden, so dass hier ein Halt gegen Umkippen gegeben ist. Aufgrund der Abdeckung der Verdrahtung der
CARRERA® | Control | Unit | ist | eine
Arretierungsmöglichkeit hier nicht gegeben.

Montage mit Schrauben

Alternativ kann mittels schraubbarer Füße auch die direkte Befestigung auf einer Montageplatte erfolgen.

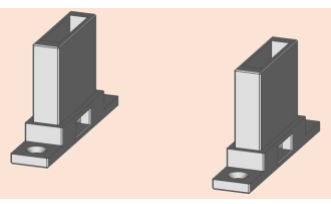
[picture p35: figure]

Dies eignet sich insbesondere dann, wenn mehrere Fahrspuren überbrückt werden sollen oder aufgrund des Aufbaus der Rennstrecke ein Unterschieben mittels L-Füßen nicht möglich ist.

Steckverbinder

Für den Anschluss an der CARRERA® Control Unit oder einer CARRERA® Adapter Unit wurde ein passender Anschlussstecker entworfen.

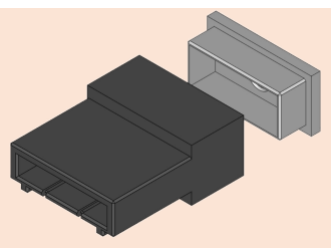
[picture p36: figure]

Platinenhalter

Um ein zurückschieben der Platinen und damit der LED-Anzeige zu verhindern, wird der Platinenhalter in die Aussparung des ISP-Anschlusses eingesetzt.

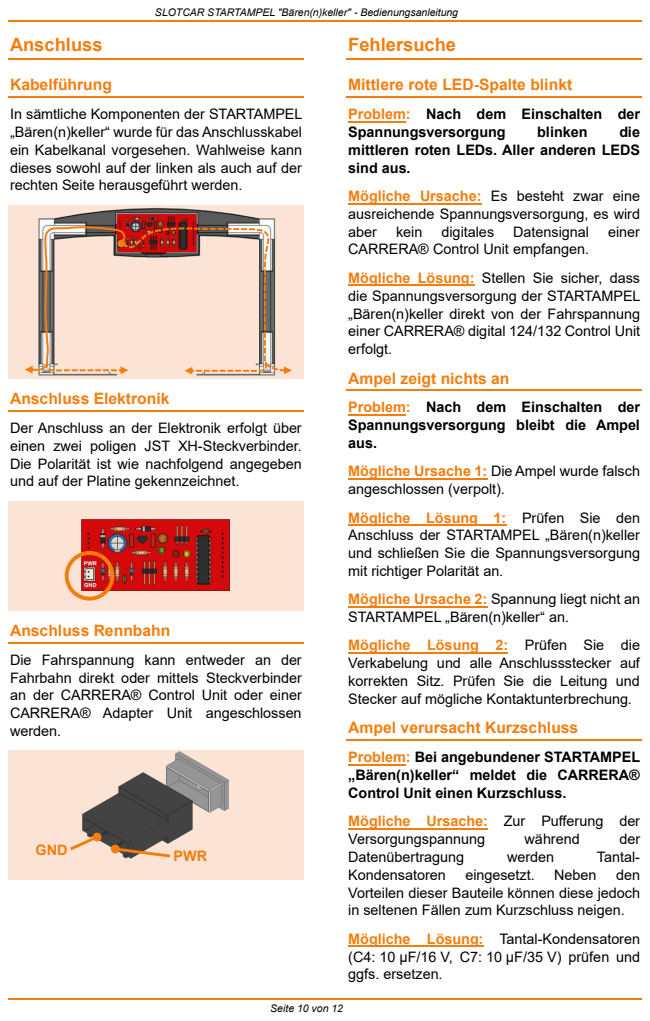
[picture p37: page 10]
Anschluss; Kabelführung; Anschluss Elektronik; Anschluss Rennbahn; Fehlersuche; Spannungsversorgung; blinken; die; aber; kein; digitales; Datensignal; einer; Mögliche; Lösung; Prüfen; Sie; Versorgungspannung; während; der; Datenübertragung; werden; Tantal-; Kondensatoren; eingesetzt.; Neben; den; Lösung: Tantal-Kondensatoren; GND; PWR

Mittlere rote LED-Spalte blinkt

In sämtliche Komponenten der STARTAMPEL
„Bären(n)keller“ wurde für das Anschlusskabel
ein Kabelkanal vorgesehen. Wahlweise kann
dieses sowohl auf der linken als auch auf der
rechten Seite herausgeführt werden.

Problem: Nach dem Einschalten der
mittleren roten LEDs. Aller anderen LEDS
sind aus.

Mögliche Ursache: Es besteht zwar eine
ausreichende Spannungsversorgung, es wird
CARRERA® Control Unit empfangen.

Mögliche Lösung: Stellen Sie sicher, dass
die Spannungsversorgung der STARTAMPEL
„Bären(n)keller direkt von der Fahrspannung
einer CARRERA® digital 124/132 Control Unit
erfolgt.

Ampel zeigt nichts an

Spannungsversorgung bleibt die Ampel
aus.

Der Anschluss an der Elektronik erfolgt über
einen zwei poligen JST XH-Steckverbinder.
Die Polarität ist wie nachfolgend angegeben
und auf der Platine gekennzeichnet.

Mögliche Ursache 1: Die Ampel wurde falsch
angeschlossen (verpolt).

Mögliche Lösung 1: Prüfen Sie den
Anschluss der STARTAMPEL „Bären(n)keller
und schließen Sie die Spannungsversorgung
mit richtiger Polarität an.

Mögliche Ursache 2: Spannung liegt nicht an
STARTAMPEL „Bären(n)keller“ an.

Verkabelung und alle Anschlussstecker auf
korrekten Sitz. Prüfen Sie die Leitung und
Stecker auf mögliche Kontaktunterbrechung.

Die Fahrspannung kann entweder an der
Fahrbahn direkt oder mittels Steckverbinder
an der CARRERA® Control Unit oder einer
CARRERA® Adapter Unit angeschlossen
werden.

Ampel verursacht Kurzschluss

Problem: Bei angebundener STARTAMPEL
„Bären(n)keller“ meldet die CARRERA®
Control Unit einen Kurzschluss.

Mögliche Ursache: Zur Pufferung der
Vorteilen dieser Bauteile können diese jedoch
in seltenen Fällen zum Kurzschluss neigen.

(C4: 10 µF/16 V, C7: 10 µF/35 V) prüfen und
ggfs. ersetzen.

### Ergänzende Informationen

Carrera Toys GmbH

- CARRERA Toys GmbH
https://carrera-toys.com/
- CARRERA® digital 132
https://carrera-toys.com/digital-132
- CARRERA® digital 124
https://carrera-toys.com/digital-124
- CARRERA® Control Unit (20030352)
https://carrera-toys.com/product/20030352-control-unit
- CARRERA® Startlight (20030354)
https://carrera-toys.com/product/20030354-startlight
- CARRERA® Lap Counter (20030355)
https://carrera-toys.com/product/20030355-lap-counter
- CARRERA® Adapter Unit (20030360)
https://carrera-toys.com/de/product/20030360-adapterunit (https://carrera-toys.com/de/product/20030360-adapter-unit)
Entwickler-Tools
- KiCAD EDA Suite
Schaltplan und Platinenlayout
https://www.kicad.org/
- Analog Devices LTspice
Simulation von elektronischen Schaltungen
https://www.analog.com/en/design-center/design-toolsand-calculators/ltspice-simulator.html (https://www.analog.com/en/design-center/design-tools-and-calculators/ltspice-simulator.html)
- Microchip Studio
Software-Entwicklung für Microcontroller ATmega/ATtiny in Assembler und C
https://www.microchip.com/en-us/toolsresources/develop/microchip-studio (https://www.microchip.com/en-us/tools-resources/develop/microchip-studio)
- FreeCAD
Parametrische 3D-Konstruktionen
https://www.freecadweb.org/
- Ultimaker Cura
3D printing Software / Slicer
https://ultimaker.com/software/ultimaker-cura/
Ähnliche Projekte
- Stephan Heß
http://slotbaer.de/carrera-digital-124-132.html
- Dipl. Ing. Peter Niehues
http://www.wasserstoffe.de/carrera-hacks/

### Entwickler und Herausgeber

## andreas wahl

Informationstechnik – Kommunikationstechnik – Elektronik innovativ + kompetent + effizient
https://www.andreas-wahl.de/

STARTAMPEL – Bären(n)keller auf GitHub:

- Software
https://github.com/Andreas-Wahl/Startlight-SW
- Hardware
https://github.com/Andreas-Wahl/Startlight-HW
- Gehäuse & Stecker
https://github.com/Andreas-Wahl/Startlight-3D

STARTAMPEL – Bären(n)keller auf Thingiverse:

- Gehäuse
https://www.thingiverse.com/thing:6443510
- Stecker
https://www.thingiverse.com/thing:6444956


## andreas wahl

Informationstechnik – Kommunikationstechnik – Elektronik innovativ + kompetent + effizient

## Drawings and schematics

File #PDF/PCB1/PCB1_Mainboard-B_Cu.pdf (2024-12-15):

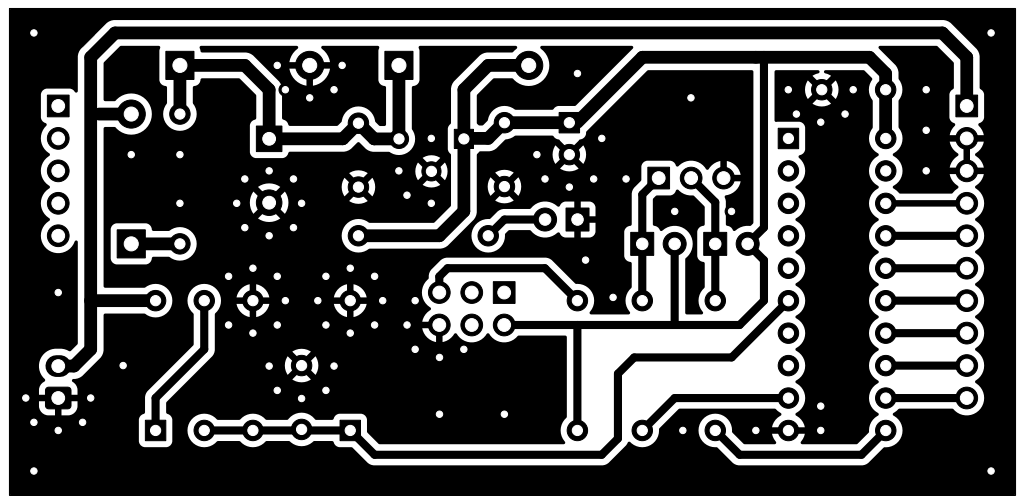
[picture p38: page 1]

https://www.andreas-wahl.de/
File: PCB1_Mainboard.kicad_pcb Sheet: Andreas Wahl - Welzheim

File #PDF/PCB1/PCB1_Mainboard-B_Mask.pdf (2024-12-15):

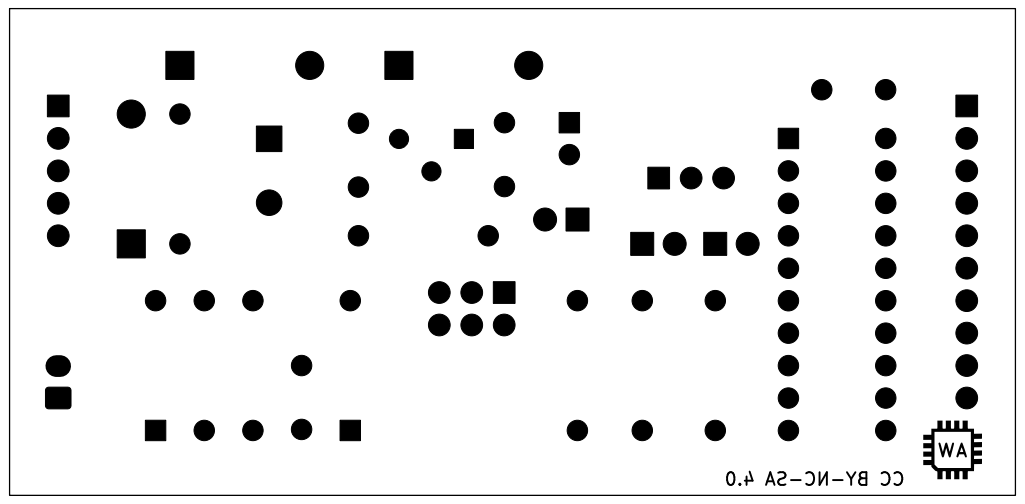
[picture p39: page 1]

https://www.andreas-wahl.de/
File: PCB1_Mainboard.kicad_pcb Sheet: Andreas Wahl - Welzheim

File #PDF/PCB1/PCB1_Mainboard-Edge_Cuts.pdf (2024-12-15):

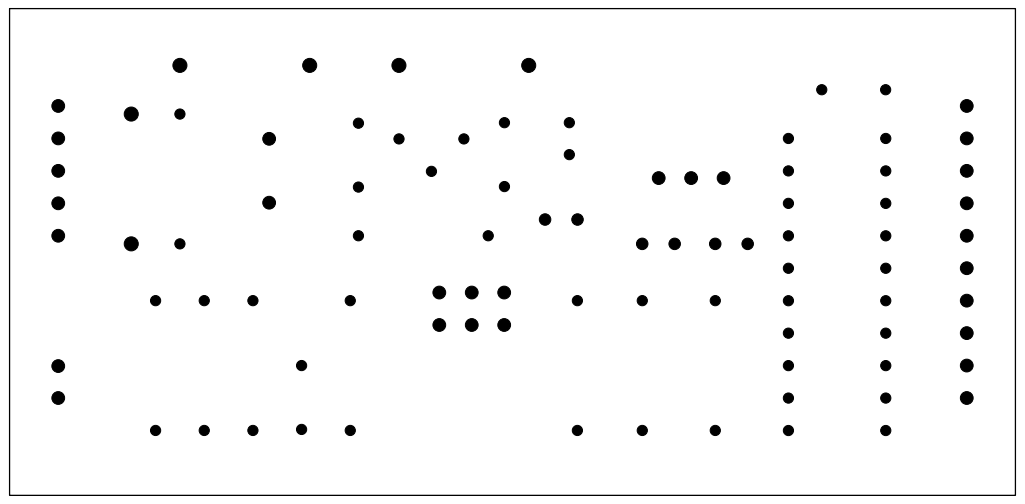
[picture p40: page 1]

https://www.andreas-wahl.de/
File: PCB1_Mainboard.kicad_pcb Sheet: Andreas Wahl - Welzheim

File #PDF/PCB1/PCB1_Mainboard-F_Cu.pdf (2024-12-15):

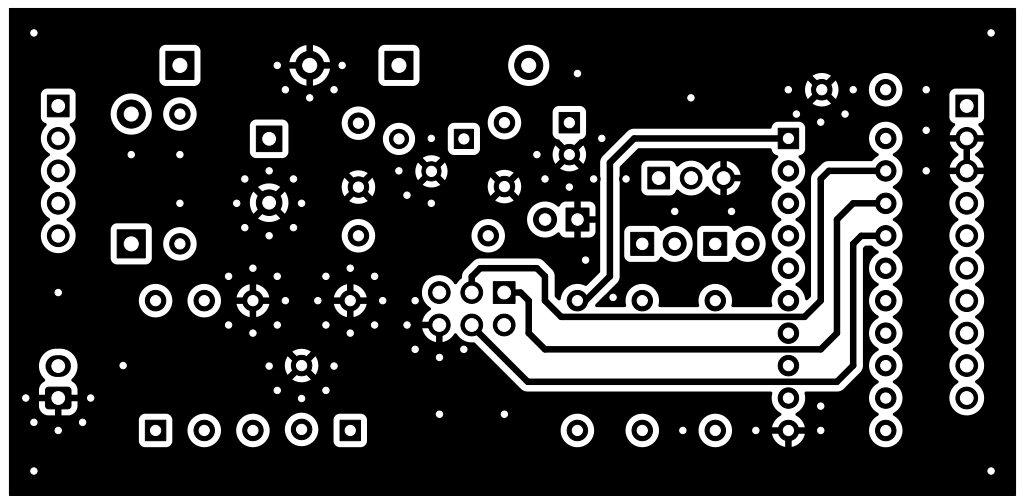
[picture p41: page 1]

https://www.andreas-wahl.de/
File: PCB1_Mainboard.kicad_pcb Sheet: Andreas Wahl - Welzheim

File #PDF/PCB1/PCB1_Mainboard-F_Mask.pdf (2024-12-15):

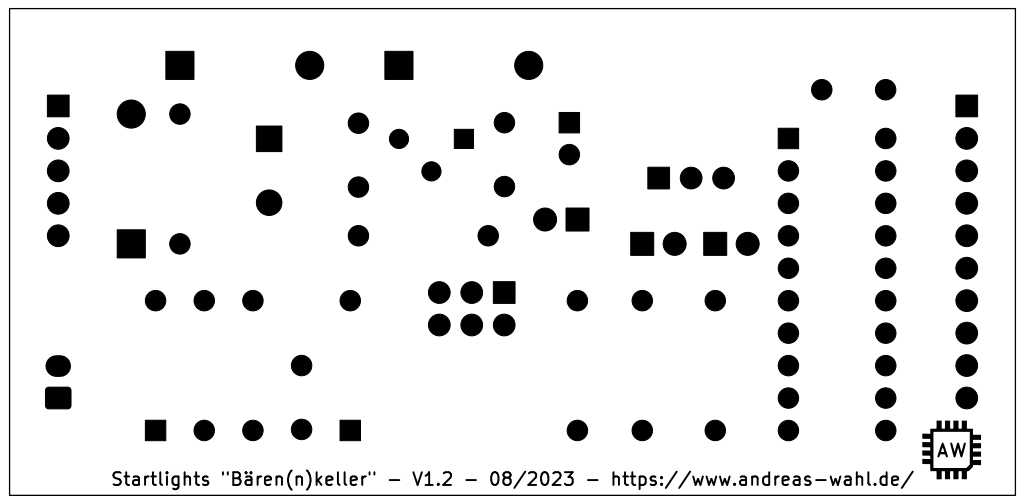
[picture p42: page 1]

https://www.andreas-wahl.de/
File: PCB1_Mainboard.kicad_pcb Sheet: Andreas Wahl - Welzheim

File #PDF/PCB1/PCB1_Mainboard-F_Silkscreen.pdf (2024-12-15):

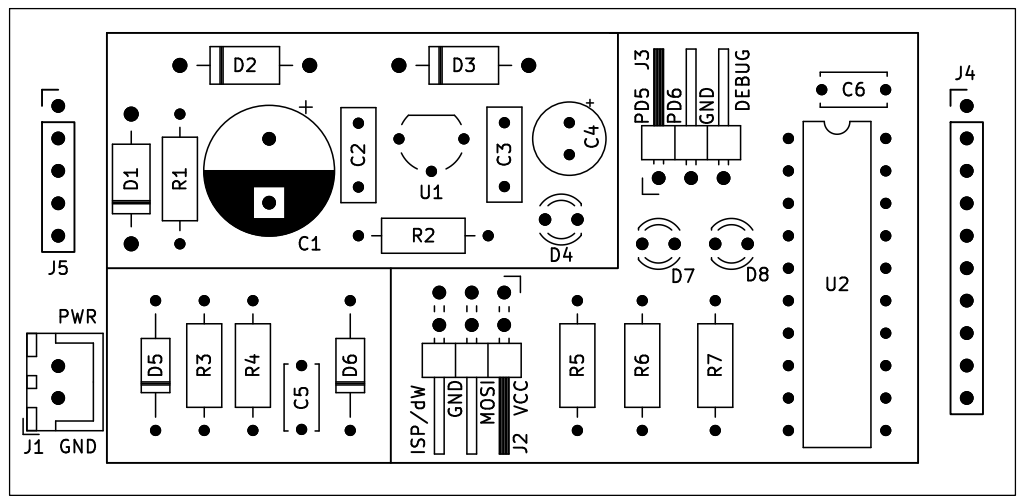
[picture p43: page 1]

File: PCB1_Mainboard.kicad_pcb Sheet: Andreas Wahl - Welzheim

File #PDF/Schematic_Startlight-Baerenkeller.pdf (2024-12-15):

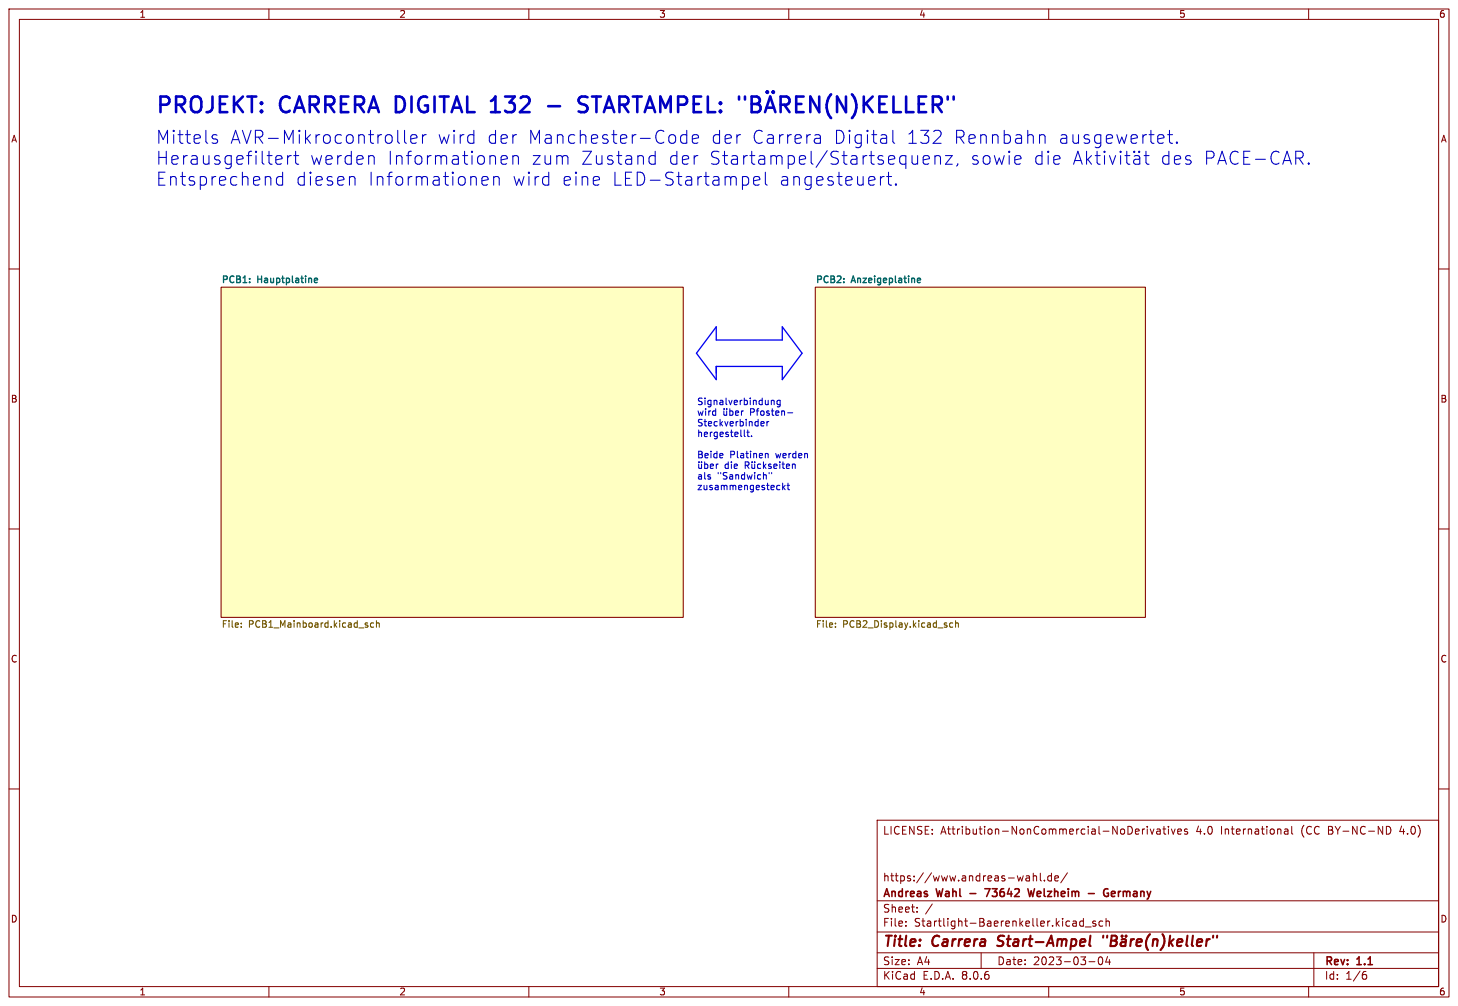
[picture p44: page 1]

PROJEKT: CARRERA DIGITAL 132 - STARTAMPEL: þÿ"BÄREN(N)KELLER"

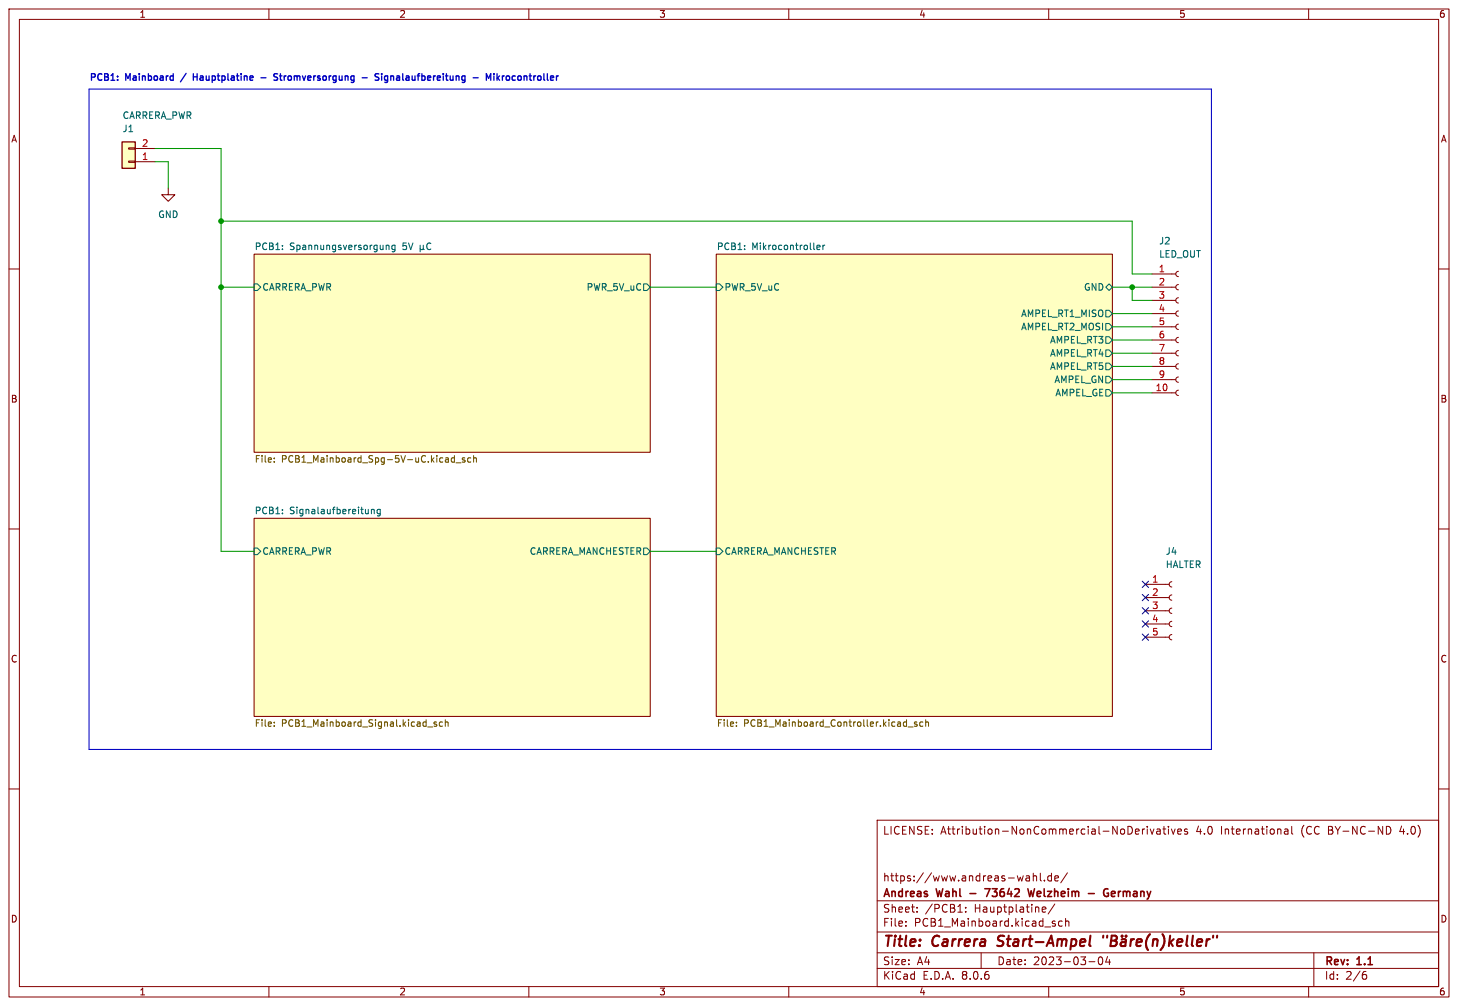
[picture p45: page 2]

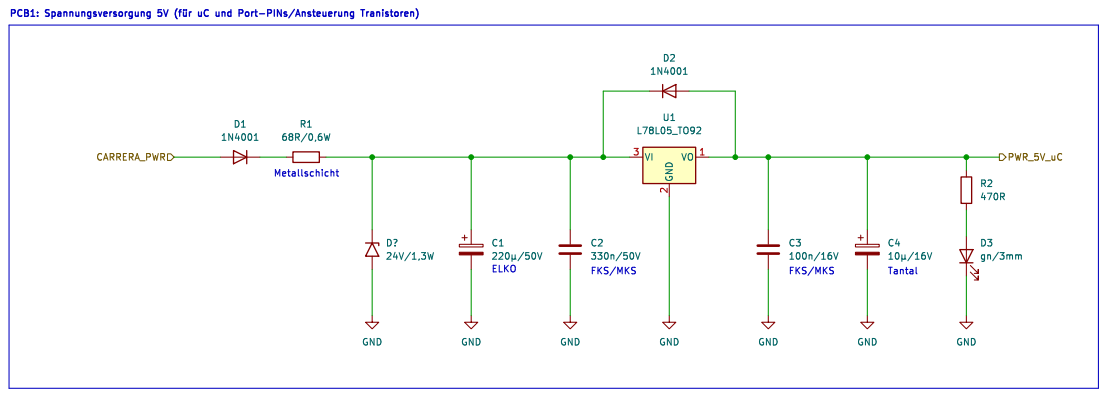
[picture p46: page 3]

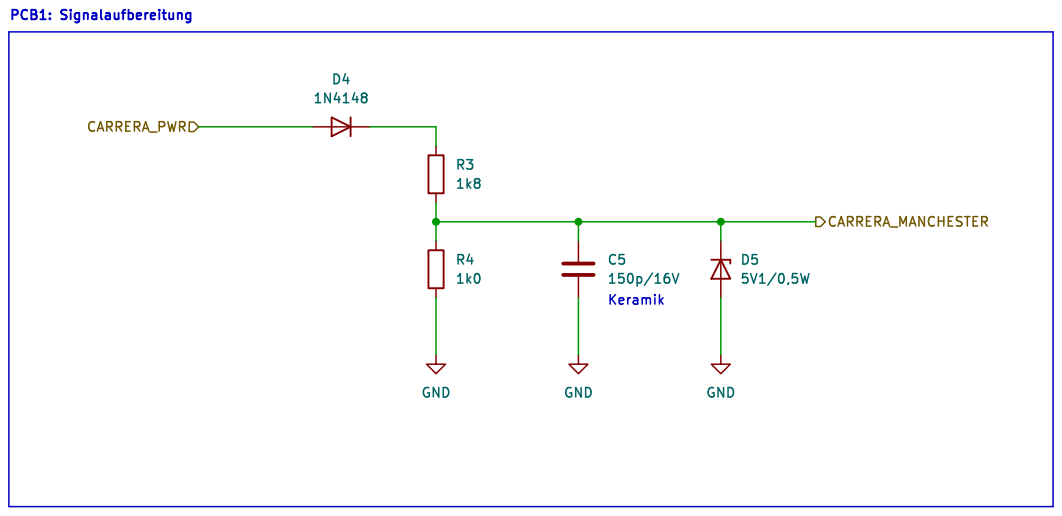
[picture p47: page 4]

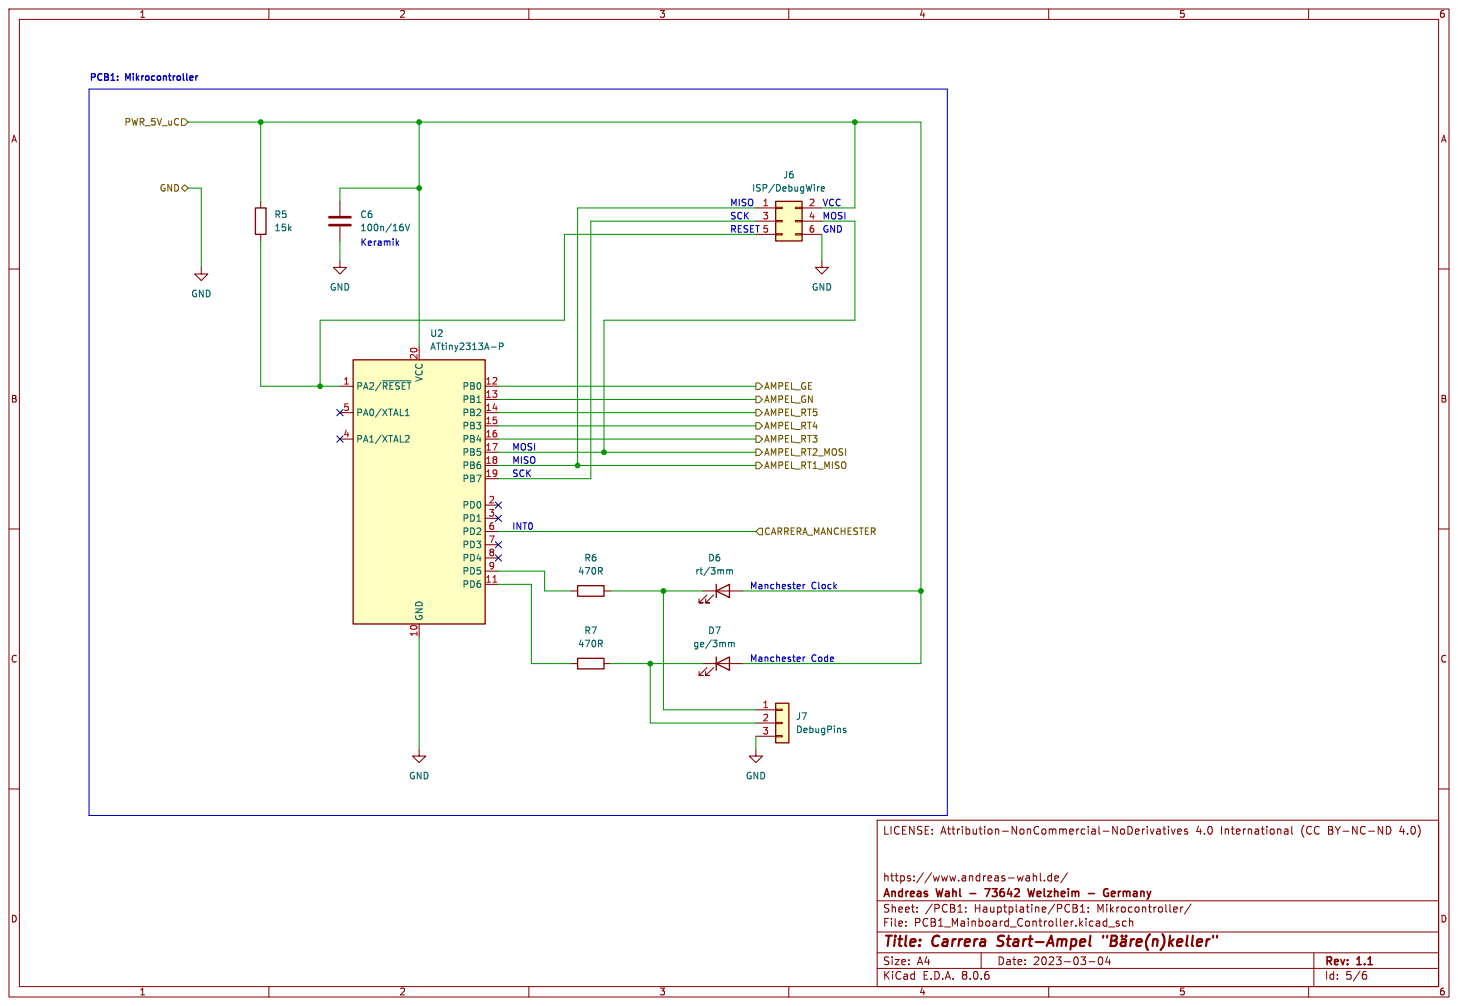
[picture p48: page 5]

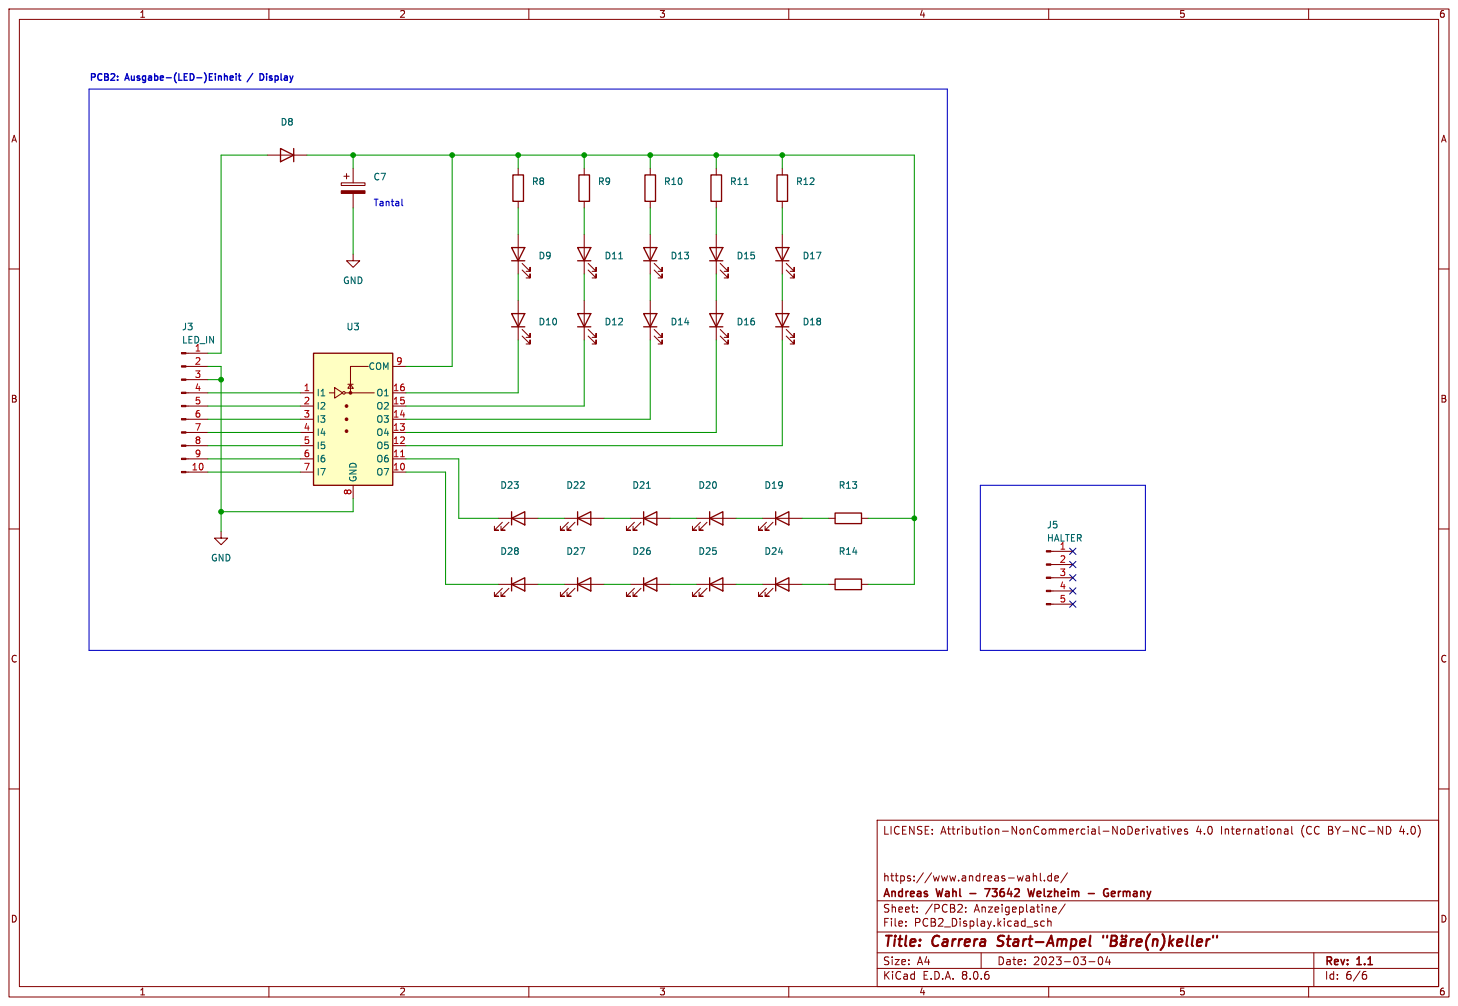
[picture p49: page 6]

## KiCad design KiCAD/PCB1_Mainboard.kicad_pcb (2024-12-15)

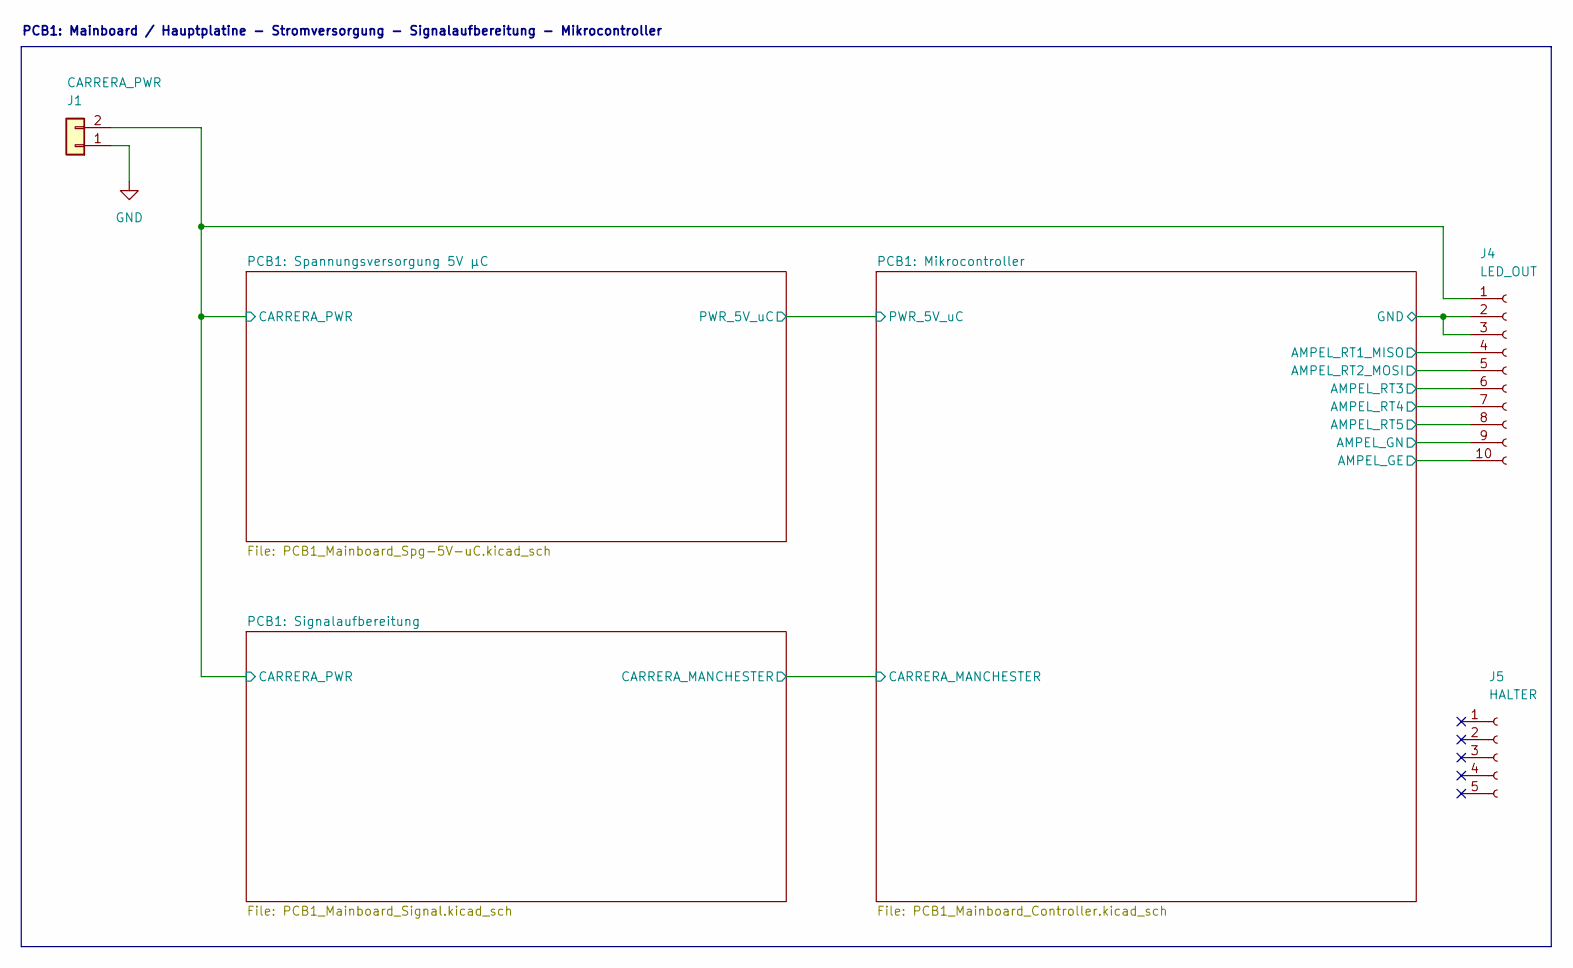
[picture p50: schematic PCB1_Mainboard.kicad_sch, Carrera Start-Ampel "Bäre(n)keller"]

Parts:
J1: CARRERA_PWR; JST_XH_B2B-XH-A_1x02_P2.50mm_Vertical
J4: LED_OUT; PinSocket_1x10_P2.54mm_Vertical
J5: HALTER; PinSocket_1x05_P2.54mm_Vertical

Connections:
/PCB1: Mikrocontroller/AMPEL_GE: J4.10; also elsewhere on the board
/PCB1: Mikrocontroller/AMPEL_GN: J4.9; also elsewhere on the board
/PCB1: Mikrocontroller/AMPEL_RT1_MISO: J4.4; also elsewhere on the board
/PCB1: Mikrocontroller/AMPEL_RT2_MOSI: J4.5; also elsewhere on the board
/PCB1: Mikrocontroller/AMPEL_RT3: J4.6; also elsewhere on the board
/PCB1: Mikrocontroller/AMPEL_RT4: J4.7; also elsewhere on the board
/PCB1: Mikrocontroller/AMPEL_RT5: J4.8; also elsewhere on the board
/PCB1: Signalaufbereitung/CARRERA_PWR: J1.2, J4.1; also elsewhere on the board
GND: J1.1, J4.2, J4.3; also elsewhere on the board

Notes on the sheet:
PCB1: Mainboard / Hauptplatine - Stromversorgung - Signalaufbereitung - Mikrocontroller

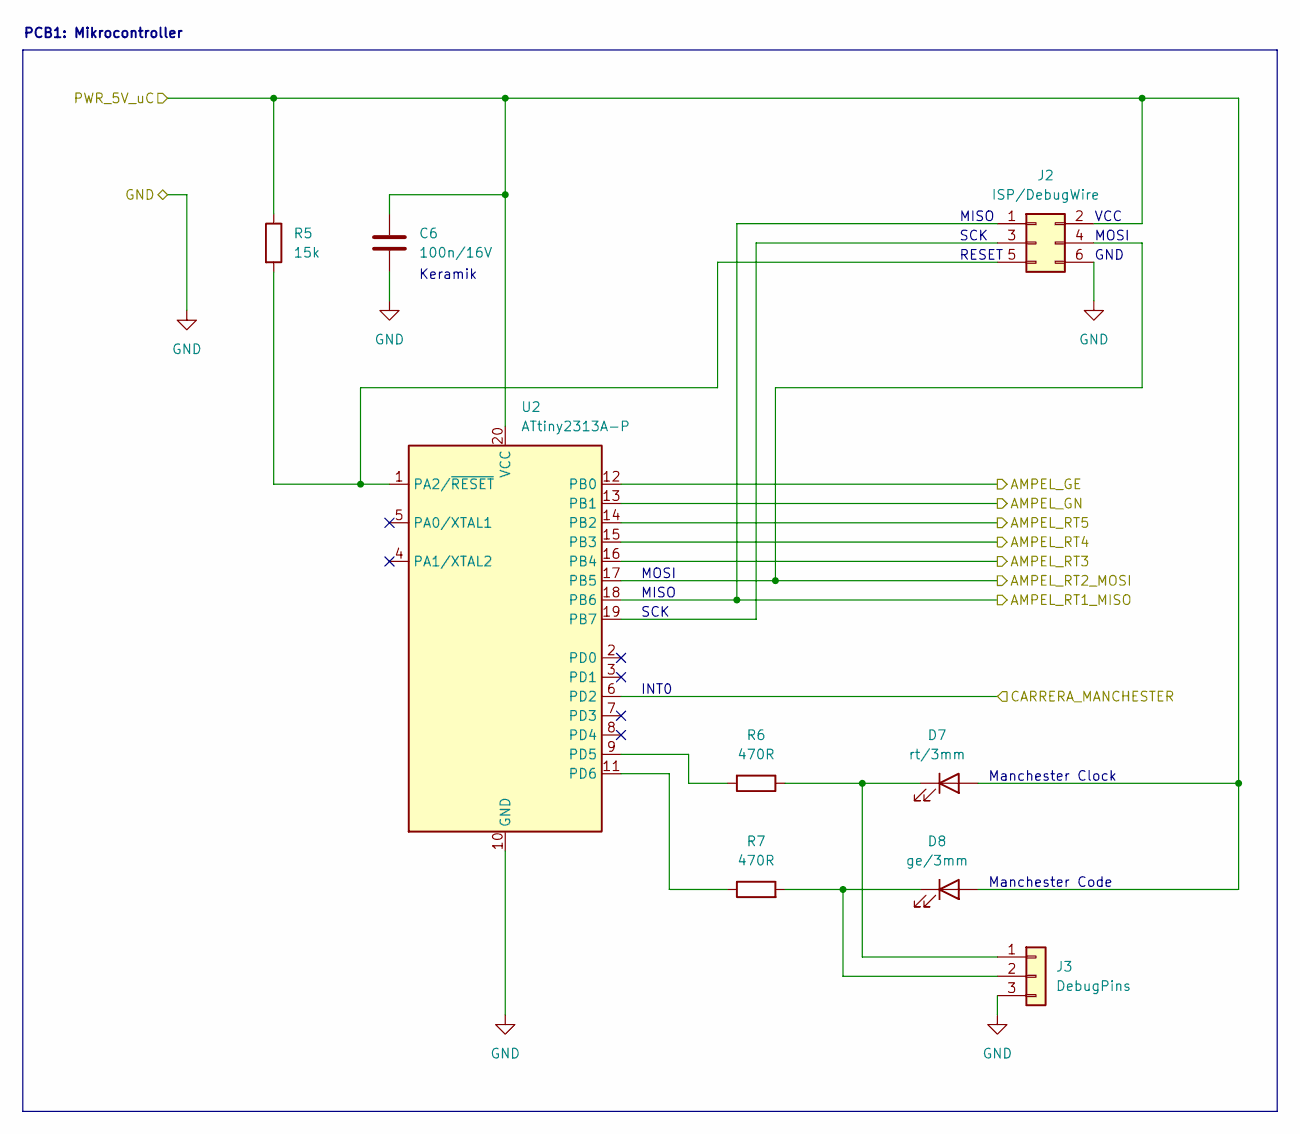
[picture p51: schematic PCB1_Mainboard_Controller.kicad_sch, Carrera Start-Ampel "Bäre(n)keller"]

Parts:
C6: 100n/16V; C_Disc_D5.0mm_W2.5mm_P5.00mm
D7: rt/3mm; LED_D3.0mm-rd
D8: ge/3mm; LED_D3.0mm-ye
J2: ISP/DebugWire; PinHeader_2x03_P2.54mm_Horizontal
J3: DebugPins; PinHeader_1x03_P2.54mm_Horizontal
R5: 15k; R_Axial_DIN0207_L6.3mm_D2.5mm_P10.16mm_Horizontal
R6, R7: 470R; R_Axial_DIN0207_L6.3mm_D2.5mm_P10.16mm_Horizontal
U2: ATtiny2313A-P; DIP-20_W7.62mm

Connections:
/PCB1: Mikrocontroller/AMPEL_GE: U2.12 (PB0); also elsewhere on the board
/PCB1: Mikrocontroller/AMPEL_GN: U2.13 (PB1); also elsewhere on the board
/PCB1: Mikrocontroller/AMPEL_RT1_MISO: J2.1, U2.18 (PB6); also elsewhere on the board
/PCB1: Mikrocontroller/AMPEL_RT2_MOSI: J2.4, U2.17 (PB5); also elsewhere on the board
/PCB1: Mikrocontroller/AMPEL_RT3: U2.16 (PB4); also elsewhere on the board
/PCB1: Mikrocontroller/AMPEL_RT4: U2.15 (PB3); also elsewhere on the board
/PCB1: Mikrocontroller/AMPEL_RT5: U2.14 (PB2); also elsewhere on the board
/PCB1: Mikrocontroller/CARRERA_MANCHESTER: U2.6 (PD2); also elsewhere on the board
/PCB1: Mikrocontroller/PWR_5V_uC: C6.1, D7.2 (A), D8.2 (A), J2.2, R5.1, U2.20 (VCC); also elsewhere on the board
GND: C6.2, J2.6, J3.3, U2.10 (GND); also elsewhere on the board
unnamed: D7.1 (K), J3.1, R6.1
unnamed: D8.1 (K), J3.2, R7.2
unnamed: J2.3, U2.19 (PB7)
unnamed: J2.5, R5.2, U2.1 (PA2/~RESET)
unnamed: R6.2, U2.9 (PD5)
unnamed: R7.1, U2.11 (PD6)

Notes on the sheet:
SCK
MISO
Manchester Clock
PCB1: Mikrocontroller
Keramik
GND
Manchester Code
MOSI
RESET
INT0
VCC

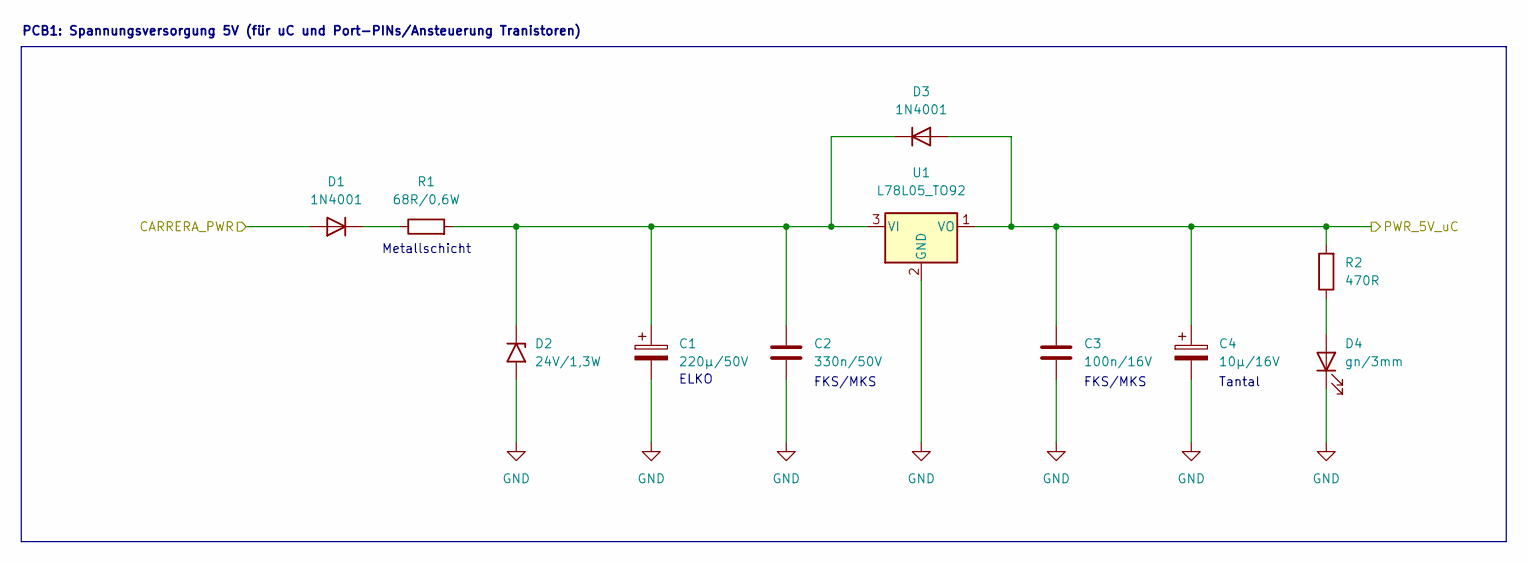
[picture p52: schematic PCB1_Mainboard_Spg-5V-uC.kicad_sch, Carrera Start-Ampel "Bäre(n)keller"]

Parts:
C1: 220µ/50V; CP_Radial_D10.0mm_P5.00mm
C2: 330n/50V; C_Rect_L7.2mm_W2.5mm_P5.00mm_FKS2_FKP2_MKS2_MKP2
C3: 100n/16V; C_Rect_L7.2mm_W2.5mm_P5.00mm_FKS2_FKP2_MKS2_MKP2
C4: 10µ/16V; CP_Radial_Tantal_D5.5mm_P2.50mm
D1, D3: 1N4001; D_DO-41_SOD81_P10.16mm_Horizontal
D2: 24V/1,3W; D_DO-41_SOD81_P10.16mm_Horizontal
D4: gn/3mm; LED_D3.0mm-gn
R1: 68R/0,6W; R_Axial_DIN0207_L6.3mm_D2.5mm_P10.16mm_Horizontal
R2: 470R; R_Axial_DIN0207_L6.3mm_D2.5mm_P10.16mm_Horizontal
U1: L78L05_TO92; TO-92_Wide

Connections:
/PCB1: Mikrocontroller/PWR_5V_uC: C3.1, C4.1, D3.2 (A), R2.2, U1.1 (VO); also elsewhere on the board
/PCB1: Signalaufbereitung/CARRERA_PWR: D1.2 (A); also elsewhere on the board
GND: C1.2, C2.2, C3.2, C4.2, D2.2 (A2), D4.1 (K), U1.2 (GND); also elsewhere on the board
unnamed: D1.1 (K), R1.1
unnamed: C1.1, C2.1, D2.1 (A1), D3.1 (K), R1.2, U1.3 (VI)
unnamed: D4.2 (A), R2.1

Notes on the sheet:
Tantal
Metallschicht
ELKO
PCB1: Spannungsversorgung 5V (für uC und Port-PINs/Ansteuerung Tranistoren)
FKS/MKS

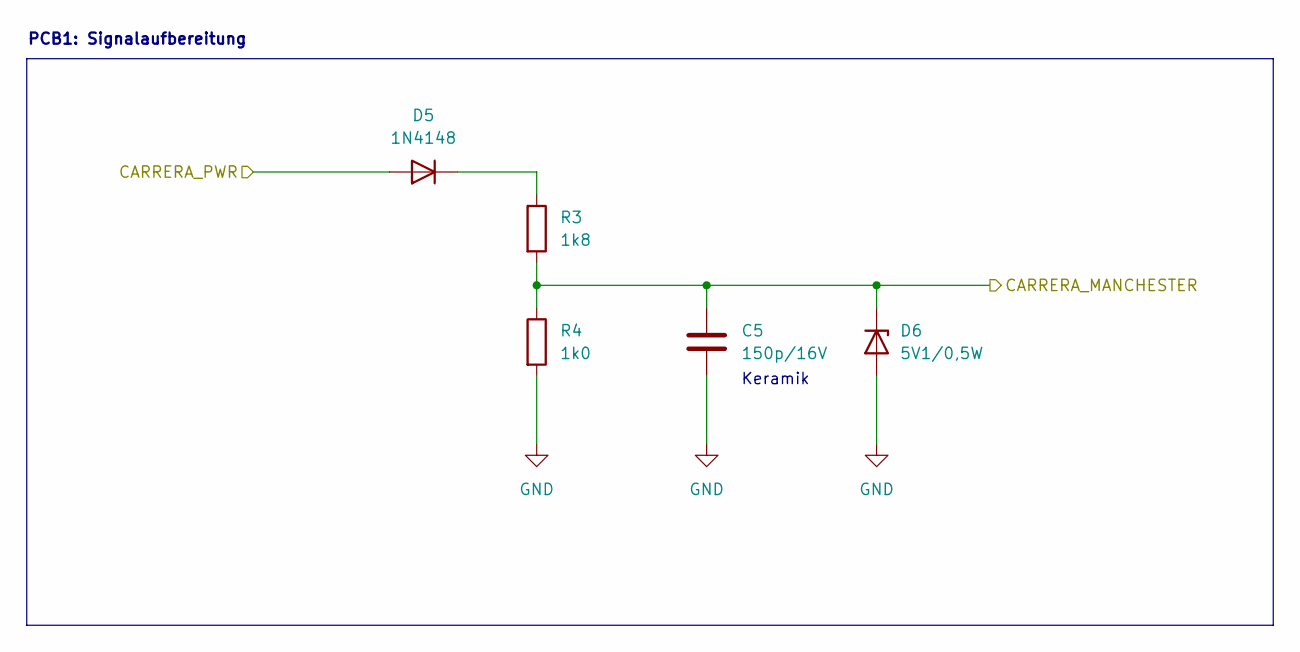
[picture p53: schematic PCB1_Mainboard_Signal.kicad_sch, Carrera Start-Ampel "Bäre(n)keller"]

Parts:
C5: 150p/16V; C_Disc_D5.0mm_W2.5mm_P5.00mm
D5: 1N4148; D_DO-35_SOD27_P10.16mm_Horizontal
D6: 5V1/0,5W; D_DO-35_SOD27_P10.16mm_Horizontal
R3: 1k8; R_Axial_DIN0207_L6.3mm_D2.5mm_P10.16mm_Horizontal
R4: 1k0; R_Axial_DIN0207_L6.3mm_D2.5mm_P10.16mm_Horizontal

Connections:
/PCB1: Mikrocontroller/CARRERA_MANCHESTER: C5.1, D6.1 (K), R3.2, R4.1; also elsewhere on the board
/PCB1: Signalaufbereitung/CARRERA_PWR: D5.2 (A); also elsewhere on the board
GND: C5.2, D6.2 (A), R4.2; also elsewhere on the board
unnamed: D5.1 (K), R3.1

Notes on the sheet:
PCB1: Signalaufbereitung
Keramik

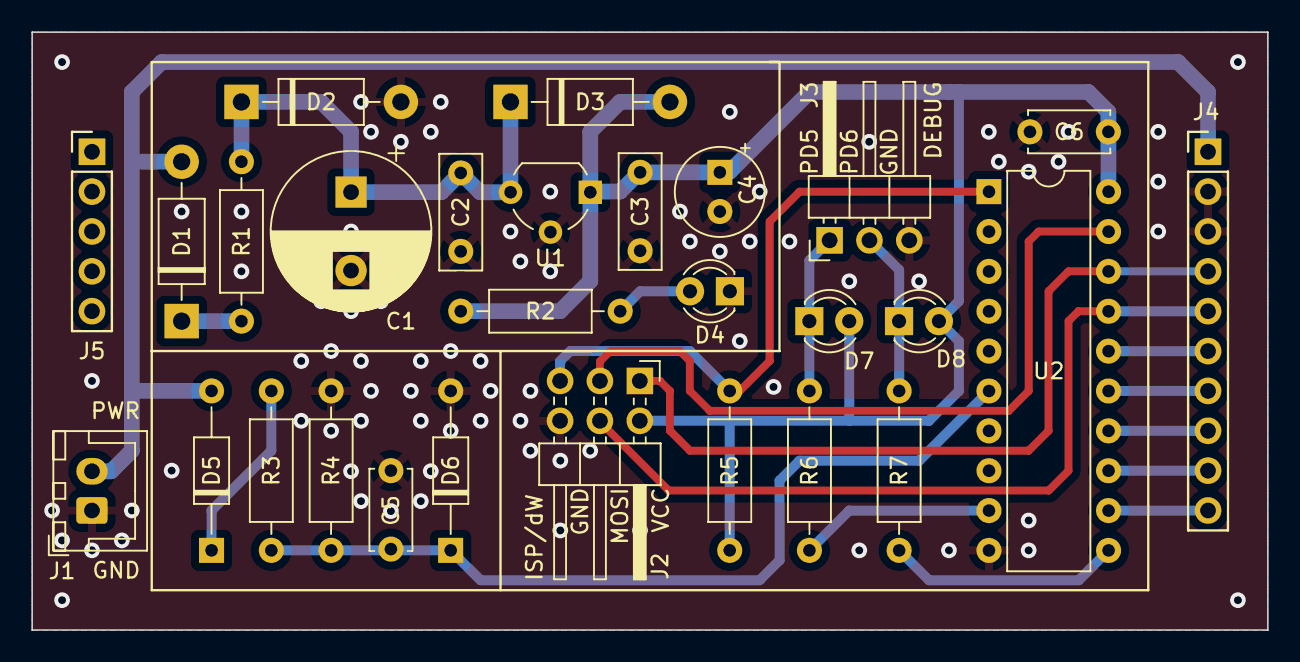
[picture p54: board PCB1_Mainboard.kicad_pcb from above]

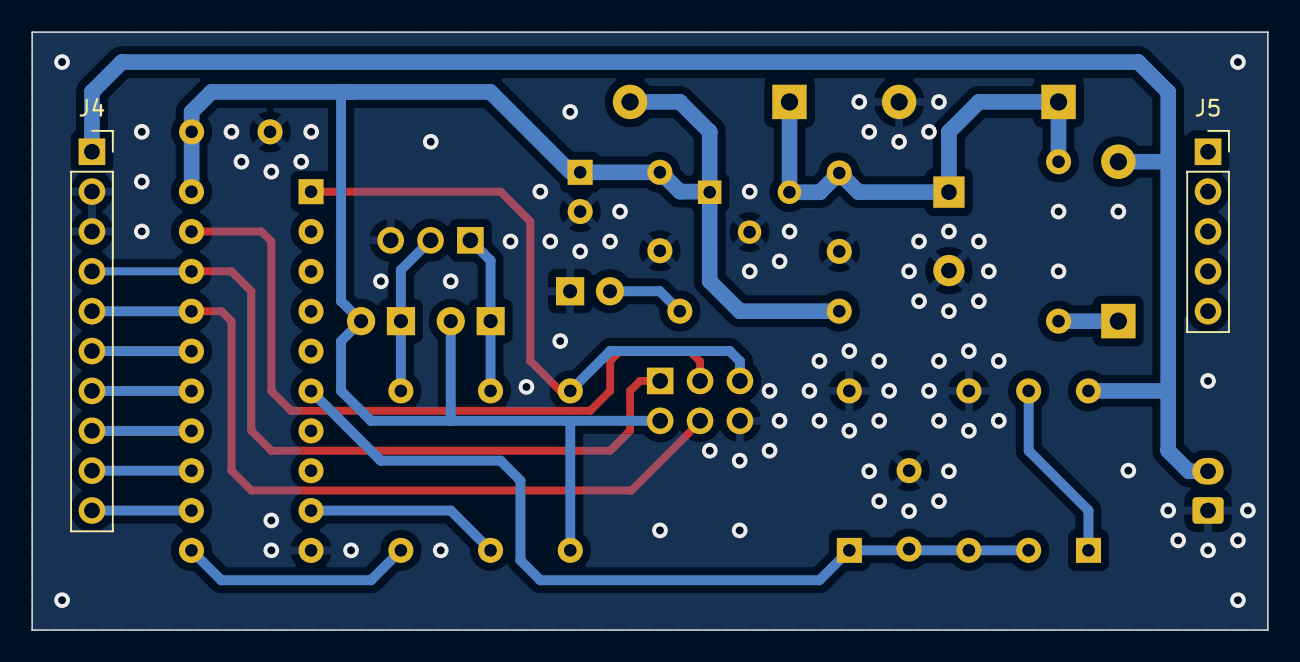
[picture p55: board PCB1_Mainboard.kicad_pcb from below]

Board: 2 copper layers, 78.7 x 38.1 mm, 28 parts (2 on the bottom side), 21 nets.

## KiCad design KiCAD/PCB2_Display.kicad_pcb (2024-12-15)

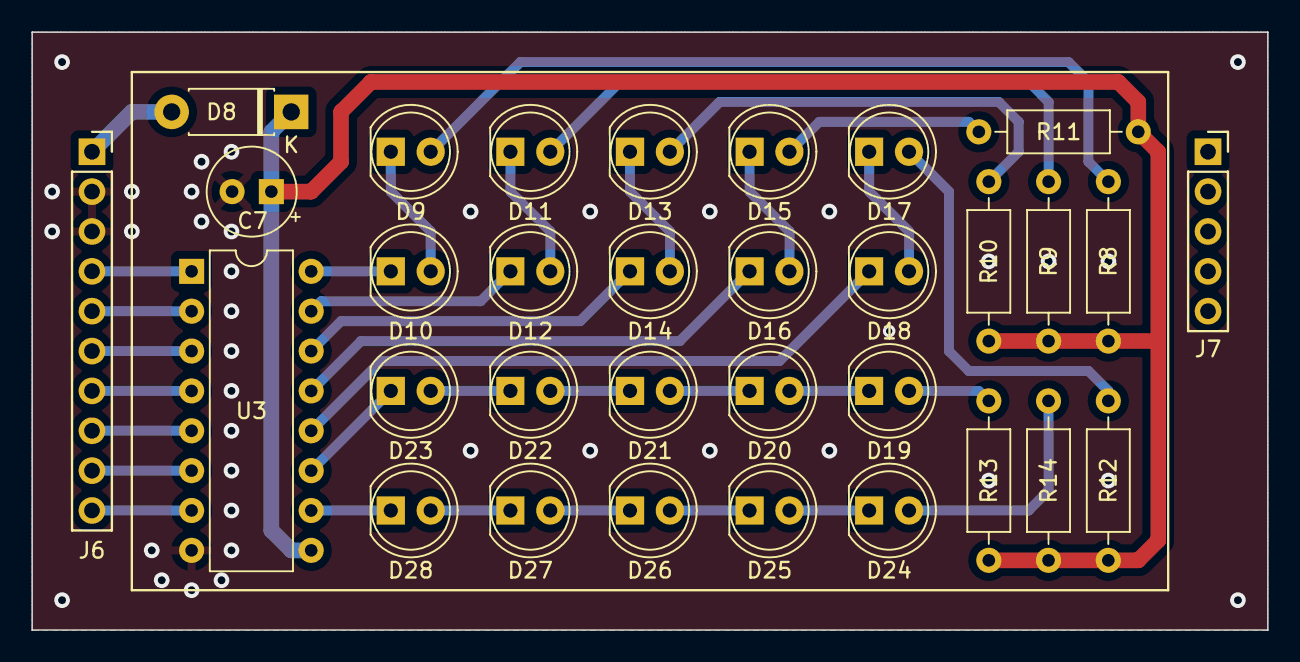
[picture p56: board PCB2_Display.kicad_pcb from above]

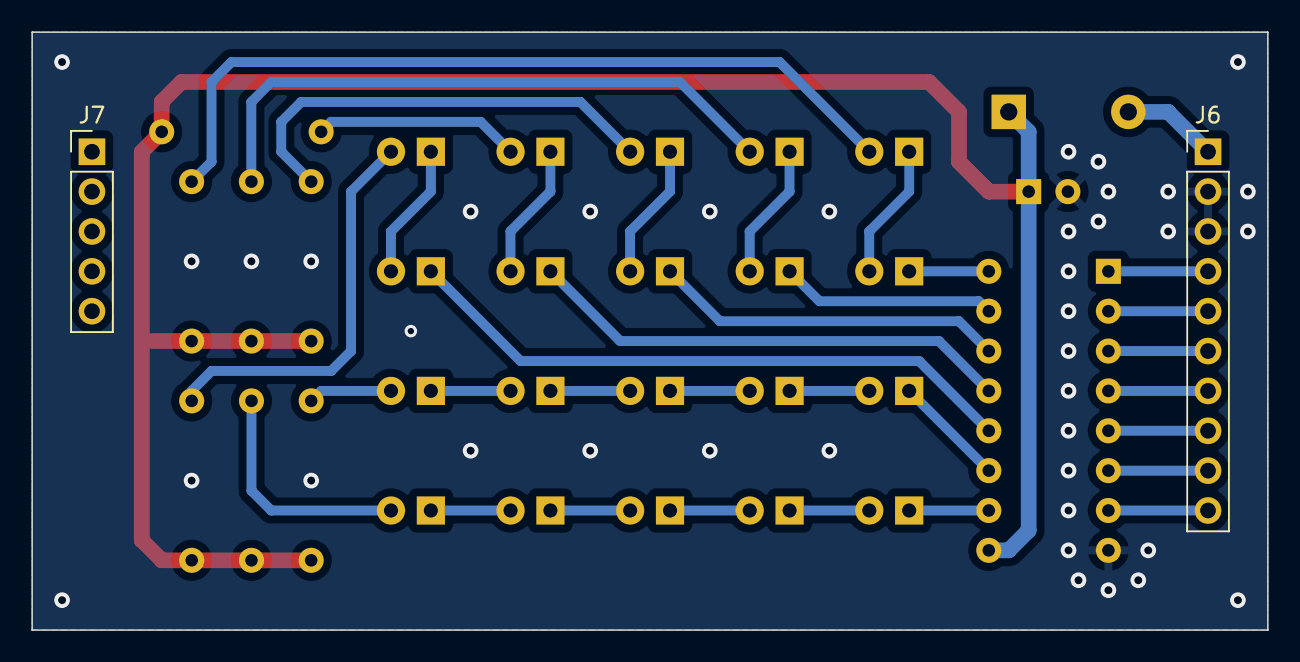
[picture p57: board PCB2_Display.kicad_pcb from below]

Board: 2 copper layers, 78.7 x 38.1 mm, 32 parts (2 on the bottom side), 37 nets.

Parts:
C7: 10uF/50V; CP_Radial_Tantal_D5.5mm_P2.50mm
D8: 1N4001; D_DO-41_SOD81_P7.62mm_Horizontal
D9, D10, D11, D12, D13, D14, D15, D16, D17, D18: rt/5mm; LED_D5.0mm_rd
D19, D20, D21, D22, D23: gn/5mm; LED_D5.0mm_gn
D24, D25, D26, D27, D28: ge/5mm; LED_D5.0mm_ye
J6: LED_IN; PinHeader_1x10_P2.54mm_Vertical
J7: HALTER; PinHeader_1x05_P2.54mm_Vertical
R8, R9, R10, R11, R12: 560R; R_Axial_DIN0207_L6.3mm_D2.5mm_P10.16mm_Horizontal
R13, R14: 220R; R_Axial_DIN0207_L6.3mm_D2.5mm_P10.16mm_Horizontal
U3: ULN2003A; DIP-16_W7.62mm

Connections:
GND: C7.2, J6.2, J6.3, U3.8 (GND)
unnamed: D8.2 (A), J6.1
unnamed: C7.1, D8.1 (K), R8.1, R9.1, R10.1, R11.1, R12.1, R13.2, R14.2, U3.9 (COM)
unnamed: D9.2 (A), R8.2
unnamed: D9.1 (K), D10.2 (A)
unnamed: D10.1 (K), U3.16 (O1)
unnamed: D11.2 (A), R9.2
unnamed: D11.1 (K), D12.2 (A)
unnamed: D12.1 (K), U3.15 (O2)
unnamed: D13.2 (A), R10.2
unnamed: D13.1 (K), D14.2 (A)
unnamed: D14.1 (K), U3.14 (O3)
unnamed: D15.2 (A), R11.2
unnamed: D15.1 (K), D16.2 (A)
unnamed: D16.1 (K), U3.13 (O4)
unnamed: D17.2 (A), R12.2
unnamed: D17.1 (K), D18.2 (A)
unnamed: D18.1 (K), U3.12 (O5)
unnamed: D19.2 (A), R13.1
unnamed: D19.1 (K), D20.2 (A)
unnamed: D20.1 (K), D21.2 (A)
unnamed: D21.1 (K), D22.2 (A)
unnamed: D22.1 (K), D23.2 (A)
unnamed: D23.1 (K), U3.11 (O6)
unnamed: D24.2 (A), R14.1
unnamed: D24.1 (K), D25.2 (A)
unnamed: D25.1 (K), D26.2 (A)
unnamed: D26.1 (K), D27.2 (A)
unnamed: D27.1 (K), D28.2 (A)
unnamed: D28.1 (K), U3.10 (O7)
unnamed: J6.4, U3.1 (I1)
unnamed: J6.5, U3.2 (I2)
unnamed: J6.6, U3.3 (I3)
unnamed: J6.7, U3.4 (I4)
unnamed: J6.8, U3.5 (I5)
unnamed: J6.9, U3.6 (I6)
unnamed: J6.10, U3.7 (I7)

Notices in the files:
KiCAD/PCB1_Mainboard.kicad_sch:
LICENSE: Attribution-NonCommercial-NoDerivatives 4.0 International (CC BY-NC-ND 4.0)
